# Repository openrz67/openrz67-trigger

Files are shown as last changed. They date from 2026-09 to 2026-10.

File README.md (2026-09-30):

# openrz67-trigger

ESP32 firmware and hardware for remote-triggering the Mamiya RZ67 analog camera over
Bluetooth LE. It runs on an ESP32-C3 connected to the camera's electrical remote port and is
controlled from the companion apps, [openrz67-android](https://github.com/openrz67/openrz67-android)
and [openrz67-ios](https://github.com/openrz67/openrz67-ios).

## Features

* Instant shutter release
* Bulb mode for remote long exposures
* Self-timer countdown with app-configurable duration
* Runs off a small LiPo, with light sleep between BLE events (see [Power](#power))

## Hardware

A custom PCB in a 3D-printed case:

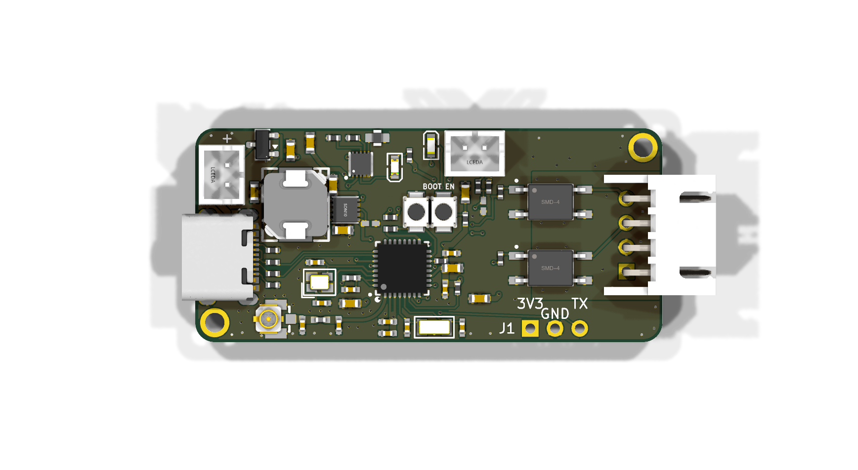
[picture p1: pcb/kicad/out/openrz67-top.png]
Custom PCB


| Directory | What |
|---|---|
| [`pcb/kicad/`](pcb/kicad/) | KiCad source, generated fab files in `out/`, design history in `notes/` |
| [`pcb/archive/`](pcb/archive/) | exactly what was sent to the fab, one folder per order |
| [`case/`](case/) | parametric build123d enclosure |
| [`BOM.md`](BOM.md) | every part that is not soldered to the PCB (cell, switch, antenna, cables) |

The boards in use are **rev 2**, verified working. The source is **rev 3**, not yet fabricated;
the case fits both.

On the board:

* ESP32-C3FH4 with an FPC antenna on a U.FL connector
* 2× Toshiba TLP172AM PhotoMOS relays (solid-state, isolated) close the shutter contacts
* TI BQ25185 charger (111 mA) and TPS63031 buck-boost, 250 mAh LiPo on `BAT1`, reverse-battery
  P-FET (rev 3)
* KCD11 rocker power switch on `S3`
* `J1`, unpopulated header for bench logging: 3V3, GND, GPIO21/TX (plus GPIO6 on rev 2)

The firmware also runs on any ESP32-C3 board with two isolated switch channels: assign two
output-capable GPIOs in `src/main.cpp`. On the PCB each GPIO drives a PhotoMOS LED through
150 Ω; the isolated output closes S1 or S2 to camera ground while the GPIO is HIGH. Keep
ESP32 ground and camera ground separate.

Wiring diagram for the ESP32-C3, two TLP172AM PhotoMOS channels and the Mamiya RZ67 camera port

### Pinout

| GPIO | Rev 2 (built) | Rev 3 (source) |
|---|---|---|
| 3 | Shutter output S2 (`S2_DRV`) | Battery sense (`VBAT_SENSE`): `SW_SYS` through a 1 MΩ / 1 MΩ divider |
| 4 | Shutter output S1 (`S1_DRV`) | same |
| 6 | `J1` pin 4, spare | Shutter output S2 (`S2_DRV`) |
| 20 | Status LED (`D4`, blue) | same |

The firmware covers every revision through build flags in `platformio.ini`: `S1_PIN` (rev 1),
`S2_PIN` and `VBAT_ADC_PIN` (rev 3).

### LEDs

Both LEDs sit under the same light pipe in the lid.

| LED | Meaning |
|-----|---|
| Red `D3`, steady | Charging. Driven by the charger IC, so it works with the power switch off. Off = full, no USB, or fault |
| Blue `D4`, slow soft pulse | On, waiting for a phone |
| Blue `D4`, dim steady | Phone connected |
| Blue `D4`, full steady | Trigger pulse (2 s) or bulb exposure |
| Blue `D4`, fast blink | Countdown running |

### Camera connector

`U4` is a JST S4B-XH-A four-pin side-entry header, opening out of the right board edge:

| U4 pin | Camera signal |
|---|---|
| 1 | Camera 6 V, unused by the board |
| 2 | GND |
| 3 | S1 |
| 4 | S2 |

Verify the pin 1 orientation before assembling the camera cable.

## Camera connection

Viewed from the front, the camera's four-pin remote-control port is:

1. 6 V — wired through, unused by the board
2. GND
3. S1 switch
4. S2 switch

To trigger the shutter, the PhotoMOS outputs short S1/S2 to camera GND. For bulb exposures,
set the shutter-speed dial to `B`. The camera closes the shutter by itself after about
60 seconds even if the switches stay closed.

## BLE protocol

The device advertises as `OpenRZ67` with service UUID `c9239c9e-6fc9-4168-b3aa-53105eb990b0`
and characteristic `458d4dc9-349f-401d-b092-a2b1c55f5319`. Send commands using Write Without
Response. The characteristic is open (no pairing): anyone in radio range can fire the camera,
which is accepted for a shutter release.

Also exposed: the standard Device Information Service (`0x180A`, firmware revision `0x2A26` =
`FW_VERSION` from `platformio.ini`), and on rev 3:

* characteristic `cda71ce6-4af9-4aa2-8d34-329c2acdae09` (read + notify): the `SW_SYS` voltage
  in millivolts, little-endian `uint16`, refreshed every 10 s. On battery this is the cell
  voltage (about 4200 full, 3500 low); on USB it is the charger's SYS voltage, which is higher.
  It is not a reliable USB-present flag: treat roughly 4250–4350 as undecided.
* Battery Service (`0x180F`, Battery Level `0x2A19`): the same reading as a percentage, linear
  from 3500 mV (0 %) to 4200 mV (100 %), which is what phones show without any app.

**Single-byte commands** (value = button × 10 + state):

| Value | Action |
|---|---|
| 11 | Trigger shutter with a 100 ms pulse |
| 10 | Clear status LED; no shutter action |
| 21 | Start bulb mode: holds S1/S2 closed until 20 is sent. Camera dial must be on `B` |
| 20 | End bulb mode |
| 31 | Start countdown with the default duration of 10 s |
| 30 | Cancel countdown |

**Three-byte commands** `[command, duration, action]`:

| Bytes | Action |
|---|---|
| `[3, n, 1]` | Start countdown of *n* seconds (`1–255`) |
| `[3, _, 0]` | Cancel countdown |

Starting a trigger or bulb exposure cancels any pending countdown. Commands are queued in
the BLE callback and executed in `loop()`, so the BLE stack never blocks on shutter timing.

## Building

[PlatformIO](https://platformio.org/) with the [pioarduino](https://github.com/pioarduino/platform-espressif32)
platform (Arduino core 3.3, ESP-IDF 5.5, NimBLE):

```bash
pio run
pio run -t upload
```

If uploading does not start, hold `BOOT`, press and release `EN`, then release `BOOT` and retry.

| Env | Board |
|---|---|
| default | rev 2 |
| `rev1` | rev 1 (S1 on GPIO 21) |
| `rev3`, `rev3-debug` | rev 3 (S2 on GPIO 6, battery sense on GPIO 3) |
| `debug` | rev 2 with USB CDC logging and `VERBOSE=1` |

The production build has no serial output. UART0 is not used for logging because its RX pin
(GPIO 20) drives the status LED; GPIO 21 (UART0 TX) is on `J1` for a TX-only dongle.

`pio check` runs cppcheck over `src/`; CI (`.github/workflows/firmware.yml`) builds every env
and runs it on each push.

## Power

The chip runs at 80 MHz with DFS down to 10 MHz, 0 dBm BLE TX power, and automatic light
sleep between BLE events: the radio wakes it for each one, so the phone connection stays up
and a trigger arrives as before. `custom_sdkconfig` in `platformio.ini` has pioarduino
rebuild the Arduino core with `CONFIG_PM_ENABLE`, tickless idle, BLE modem sleep and the
32.768 kHz crystal `X2` as the BLE low-power clock (the first build per machine takes a few
minutes). Consequences:

* The status LED runs on LEDC from `RC_FAST` in keep-alive mode, since the APB clock stops
  in light sleep.
* Light sleep releases every GPIO, so a PM lock keeps the chip awake while the shutter is
  open (bulb and the trigger pulse).
* The USB Serial/JTAG port drops off the bus in light sleep, so the `debug` env stays awake,
  and flashing a sleeping production build may need the `BOOT`/`EN` sequence above.

If `X2` does not start, ESP-IDF falls back to the internal RC and BLE keeps working without
light sleep. Current draw is not measured yet.

## License

[MIT](LICENSE), covering the firmware in `src/`, the KiCad design files in `pcb/kicad/` and
the enclosure sources in `case/`. MIT is written for software, but its grant is broad enough
to serve a hardware design; the closest hardware-specific equivalent is CERN-OHL-P.

Two things in this repository are **not** covered, because they are not mine to license:

* The footprints in `pcb/kicad/openrz67.pretty/` and the symbols in `openrz67.kicad_sym`
  were imported from the EasyEDA/LCSC part libraries.
* The 3D models in `pcb/kicad/openrz67.3dshapes/` were fetched per LCSC part number with
  `easyeda2kicad`.

Both are redistributed here for convenience under their originators' terms.

## Credits

The camera connector pinout that made this project possible was described to me by
Julio Ryuuzaki, who built and sold the Bluetooth [RZ Blue](https://ryuuzaki.jp/) trigger
for years. He answered a cold email in December 2022 with the essentials — four pins, one
ground, two live, one unconnected — and the warning that the camera closes the shutter by
itself after about a minute in bulb mode. Thank you.

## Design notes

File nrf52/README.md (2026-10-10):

# nRF52 coin-cell trigger

Second board design for the RZ67 trigger: an nRF54L15 module on a CR2032, no regulator,
charger or power switch. Rev A is ordered (fab package in [`kicad/archive/`](kicad/archive/)).

| Directory | What |
|---|---|
| `kicad/` | the board, generated from `tools/design.py`; fab files in `out/` |
| `case/` | build123d snap-fit box |
| `firmware/` | Zephyr application, builds on nRF Connect SDK v3.4.1 |
| `notes/` | reasoning and history |

## Parts to buy

Nothing is soldered by hand. The board comes assembled, everything else plugs in.

| What | Where | Note |
|---|---|---|
| Assembled board | JLCPCB, upload `kicad/out/openrz67-nrf-gerber.zip` + BOM + pos from `kicad/out/` | assembly on both sides |
| CR2032 | anywhere | one per board |
| SH1.0 4P to Dupont female cable (Qwiic / STEMMA QT pigtail) | AliExpress | three: one camera cable (`J1`), one for flashing (`J2`), one spare |
| Raspberry Pi Pico 2 WH | any Pi reseller | the flashing probe; H = headers pre-soldered, W is irrelevant here. Load Raspberry Pi's `debugprobe_on_pico2.uf2` on it; a Pico H (`debugprobe_on_pico.uf2`) works the same |

`J2` pin 2 carries the cell voltage out. Never plug a powered Qwiic device into `J2`; only the
probe cable belongs there. The camera end of the `J1` cable goes to the RZ67 socket as today (GND, S1, S2). Wiring for
`J2` to the Pico is in [`firmware/README.md`](firmware/README.md).

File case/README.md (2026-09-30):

# Parametric enclosure (build123d)

`openrz67_case.py` is a parametric two-part enclosure for the OpenRZ67 trigger PCB, written
in [build123d](https://build123d.readthedocs.io/). It is built from the board file and its
footprints, not from eyeballed measurements. Drawn for rev 2 (tag `pcb-rev2`); rev 3 keeps
the outline, holes and every connector and LED position, so the same case fits.

Layout: the LiPo cell lies flat **under the PCB** in a low rib pocket, the PCB sits on 8 mm
posts, and open pockets in front of (2 mm) and behind (4 mm) the board take fingers and the
battery lead. `U4` and its plug stay inside; only the heat-shrunk camera cable leaves
through a keyhole slot in the right wall. The lid snaps on, no hardware.

Finished size with default values: ~**64.9 × 36.0 × 25.5 mm**. The lid height is set by the
rocker switch's latch pocket. Printed in ABS; all fit numbers are ABS-measured.

The reasoning behind the numbers, and everything that was tried and dropped, is in
[`notes/design-history.md`](notes/design-history.md).

## Source data

Board coordinates in the script have the origin at the board's front-left corner with Y
toward the back; KiCad measures Y from the other long edge, so `board_y = 22 - kicad_y`
(`../pcb/kicad/out/openrz67-pos.csv` lists KiCad Y as negative numbers; drop the sign).

| Measurement | Value | Source |
|-----|---|---|
| Board outline | 48.0 × 22.0 mm, R2.0 | `openrz67.kicad_pcb` Edge.Cuts |
| Mounting holes | 2× Ø2.0 at (2,2) and (46,20) | `MountingHole_2.0mm_Pad3.0` footprints |
| PCB thickness | 1.6 mm | `pcb_t` (as ordered) |
| Component placement | see `openrz67_case.py` | `out/openrz67-pos.csv` |
| U4 camera connector | side-entry S4B-XH-A, pin row at (44.3, 11), mouth facing +X; body 12.4 wide × 6.1 tall, mouth 5.5 mm past the board edge | `CONN-TH_S4B-XH-A-LF-SN.kicad_mod` + `.wrl` |
| USB-C connector | body 8.95 × 3.2 mm, left edge 4.8 mm in from the PCB's left edge; shell protrudes ~2 mm past the board | measured |
| Rocker switch (KCD11) | snap-in body 13.5×8.5 (= panel cutout), flange 15×10, 10 deep behind the flange, two 2.8 mm tabs ~5 long at ~7 mm pitch; vendor drawings differ by ~0.5 mm | vendor data — measure your switch |
| FPC antenna | Ebyte TX2400-FPC-2509, 25 × 9 × ~0.2 mm, U.FL, ~100 mm cable, to `A1` | vendor data |
| LEDs | D3 red (20.5, 18.0), D4 blue (24.2, 20.2), 0603 top-emitting | `out/openrz67-pos.csv` |

Component heights are editable constants (`h_usbc`, `h_ph_plug`, `xh_h`) from the datasheets
and 3D models. Check them against your own parts.

The script carries **module-level assertions**: outer dimensions, probe checks that every
opening breaks through (USB, camera cable slot, LED window, locating-pin recesses, switch
hole and latch pocket), and that the fit-critical keepouts (switch body + tabs + receptacles,
USB-C body, U4 + mated plug, the cell under the PCB) stay open. They run on every export, so
a parameter tweak that closes a hole or re-introduces a known collision fails loudly.

## Construction

- **Base** (tub): floor, four **8 mm posts** (`standoff_h`; two at the mounting holes, two at
  `pcb_supports = [[2,20],[46,2]]`), and two **Ø1.85 locating pins** (`pin_d`) up into the
  board's Ø2 mounting holes. The cell lies on the floor between the posts, lengthwise from
  board-X `batt_x0`, inside a low rib ring (`batt_rib_t/h`, `batt_clr`) with foam tape on top.
  - **Through-hole solder relief** (`th_keepouts`, `[board_x, board_y, diameter]`,
    `th_keepout_depth` 3.5): a pocket in a post top where a through-hole part's tails stick down.
  - **Guide fins** (`frame_*`): fins from the wall across the pockets hold the PCB in Y, two
    per long edge (`frame_ribs_front/back`), ending `frame_clr` from the board edge with a
    lead-in lip `frame_proud` above it. The lid tongue is notched where they stand.
- **Lid**: telescopes into the base via a perimeter tongue (`lap` 7 mm). Carries the USB-C
  opening (left), the camera cable slot (right), the LED light-pipe seat (top) and the snap-in
  hole for the rocker switch (front). Top edge chamfered `lid_top_r` (2 mm, 45°): the lid
  prints upside-down, so this is the bed-side edge.
  - **Camera cable slot** (`cut_cable`): the U4 body and the mated XHP-4 plug (`xh_plug_proud`
    2.5 past the mouth, an estimate) stay inside; `xh_slack` (1.5) sets `pcb_overhang_right`
    (9.1). The cable leaves through a **keyhole** in the right wall: round top of `cable_d` +
    2 × `cable_clr` (Ø6) at the header's mid-height, open straight down to the seam, so the
    bundle drops in as the lid closes and the lid lifts off untethered.
  - **LED light pipe** (`led_*`, separate part, clear filament): a top hat with a tapered
    head in a 26.6° funnel seat and a rod down to `led_pipe_gap` (0.8) above the LEDs. **Slip
    fit, glued**: `led_stem_clr` = `led_pipe_clr` (0.2). A collar `led_collar_h` (2.6) off the
    ceiling keeps it straight. Parameters: `led_win_l/w/r`, `led_head_lip/t`, `led_pos`.
  - **Component clearance** (`comp_keepouts`): rectangles cut out of the lid's hold-down
    bosses where a boss would hit a component (e.g. the boss at hole (2,2) is D-shaped to
    clear the USB-C body).
  - **Antenna recess** (`ant_*`): a 25.6 × 9.6 × 0.3 mm pocket in the lid ceiling for the
    adhesive FPC antenna, in the free band between the rocker body and the light-pipe stem.
    `ant_cx_frac` (0.25) slides it along the band. Asserted to fit the band and to leave
    ≥ 0.8 mm of top plate under the lid text.
- **USB-C side**: `pcb_overhang_left` (2.0) makes room for the shell; `usb_shell_poke` (1.4)
  slides the board toward that wall so the shell noses into the recess. On the right,
  `pcb_overhang_right` (9.1) makes room for the mated XH plug.
- **Battery** (31 × 20 × 6 LiPo): under the PCB with `batt_foam` (1.5) between. Its lead comes
  out at the left end over the rib, into the 4 mm pocket behind the board, up past the edge
  and into BAT1 on top. Nothing is threaded: cell in, board onto the pins, lead over the
  edge, lid on. Parameters: `batt_w/l/t`, `batt_x0`, `batt_foam`, `batt_clr`, `batt_rib_t/h`,
  `pocket_front/back`.

## Closure — snap fingers

Four **cantilever fingers** cut free in the lid tongue (two per long wall, `snap_fingers_x`)
carry a bead (`snap_bead` 0.55, `bead_h` 1.4; 0.4 click-in chamfer below, 0.15 above) that
clicks into a pocket in the base lip (`pocket_extra_d/h`, `pocket_ch`). Each finger is
`finger_l` (12) long and `finger_t` (1.0) thick with a `finger_slot` (0.8) relief at each end;
the bead sits `bead_tip_h` (1.1) above the tip, so the lever is ~6 mm: about 2 % strain at
full deflection. The rest of the tongue and the base lip stay rigid (`wall` 3.2). The PCB is
pressed onto the posts by the lid's hold-down bosses (blind pin recesses, no holes through
the top). Open with a coin in the **pry slot** (`pry_w/d/h`) on the back wall; the back
fingers release first.

**Tune before the full print:** `SNAP_TEST=true ./export.sh` also exports a cropped
front-left corner pair (`openrz67-snaptest-*`) with one finger and one locating pin. Print
those and adjust `snap_bead` (click strength), `finger_t` (stiffness) and `lap_gap` (sliding
fit) until the corner snaps shut and pries open with reasonable force.

## Orientation mark — `orient_mark`

A raised rib on the front wall near the left corner, split across the seam: base carries the
lower half, lid the upper. Lid on the right way round, the halves line up; 180° wrong, the
lid's half lands at the other corner. Parameters `orient_mark_x/w/d/h`; delete the two
`orient_mark_rib` lines to remove it.

## Lid text — second colour (`lid_texts`)

Debossed nameplate in front of the LED seat: **"OpenRZ67"** (9.5 mm) over a tracked all-caps
**"TRIGGER"** (5 mm, +1.0 letter spacing), Futura Bold (macOS system font; OCCT falls back to
Arial if missing). A thin rail (`lid_rail_*`) runs across the LED row and breaks around the
light-pipe seat. Pockets are `lid_text_depth` (0.8 mm, 4 layers; 0.9 is the cap) deep and an
**inlay** solid (`lid_text`, exported as `openrz67-lid-text.stl`) fills them exactly.
Assertions enforce placement and printability (every glyph stroke ≥ `lid_text_min_stroke`
0.6 mm).

Colour it by **part, not by slicer paint**: `make_3mf.py` adds the inlay to the lid object as
a second part on filament 2 (`SUB_PARTS`). Set filament 2 to the letter colour and print. On
a single-filament printer, delete the inlay part and do a manual filament change at Z = 0.8
(slice the lid alone).

Edit `lid_texts`, `lid_font`, `lid_text_gap` and `lid_rail_*` to restyle; `LID_TEXT_SHOW=false`
disables the text.

## Usage

The parameters are plain Python constants at the top of `openrz67_case.py`. Requires
[uv](https://docs.astral.sh/uv/); the script carries its own dependency header.

```bash
cd case
./export.sh            # base, lid, lightpipe, lid text -> stl/  + openrz67-case.3mf
./export.sh out        # custom output dir (skips the .3mf)
```

Overrides from the environment:

```bash
LID_TEXT_SHOW=false  ./export.sh   # hide the lid text
LID_TEXT="My text"   ./export.sh   # the name line (TRIGGER stays)
LID_TEXT_SIZE=8.0    ./export.sh   # its font size (mm, default 9.5)
SNAP_TEST=true       ./export.sh   # also export the corner test pair
PCB_T=1.0            ./export.sh   # PCB thickness (sets the base/lid split)
MAKE_3MF=false       ./export.sh   # skip the .3mf
```

Or run the script directly: `uv run openrz67_case.py`. For a plain interpreter there is a
local venv: `uv venv .venv && uv pip install -p .venv "build123d>=0.11.1"` (git-ignored, as
is `stl/`). For a 3D preview, open the file with an OCP viewer (e.g. `ocp_vscode`) or inspect
the STLs in the slicer.

### Slicer project (.3mf)

`export.sh` rebuilds `openrz67-case.3mf`, a Bambu Studio / OrcaSlicer / QIDI Studio project:
base + lid on plate 1 (filament 1, lid text on filament 2), the light pipe alone on plate 2
(filament 3 = clear) with its own object settings (0.28 layers, 100 % infill, 8 walls,
20 mm/s). `make_3mf.py` swaps the fresh meshes into a template saved from the slicer
(`bambu-template.3mf`), so all slicer settings are preserved. To change print settings, plate
layout or filament mapping, edit the project in the slicer and re-save it over
`bambu-template.3mf`. Plate thumbnails are not regenerated; the slicer refreshes them.

Do not use height-range modifiers in the template: QIDI Studio crashes on opening a .3mf
that carries them. Per-object settings are safe.

## Print orientation

- **Base**: floor down. No supports.
- **Lid**: **upside down** (top plate on the bed). Bosses and lip point up, and the LED funnel
  is widest at the bed. Turn elephant-foot compensation on (~0.15) so the first layer does
  not close in on the funnel rim; support threshold 30° or lower.
- **Light pipe**: clear filament, upright (head down). For the clearest light: thick layers
  (0.28–0.3), 100 % infill, slow, hot, fan off, on a **smooth** plate (the head's top face
  prints against it).

## Worth adjusting before printing

- `pcb_t`: PCB thickness (1.6 as ordered). Sets the base/lid split height.
- `pcb_overhang_left`: air for the USB-C shell. Measure your connector. Default 2.0.
- `h_ph_plug`: PHR-2 plug + wire bend height on `BAT1`/`S3`. Lower it if yours sit lower.
- `xh_plug_proud` / `xh_slack`: mated XHP-4 plug past the U4 mouth (2.5, estimate) and air to
  the wall. `cable_d`: the heat-shrunk bundle's diameter (5.0).
- `snap_bead` / `finger_t` / `lap_gap`: tune with the `SNAP_TEST` corner pieces.
- `batt_*`: your cell and its pocket. `standoff_h` must stay ≥ cell + foam (asserted).
- `ant_l/w/clr/depth` / `ant_cx_frac`: the antenna and its recess. Optional part; BLE works
  without it at much less range.
- `sx`: rocker switch position, centred on the lid (`outer_w / 2`) on the front wall. The
  back wall carries S3, the LEDs and the lead pocket. `kcd_gap` (1.6) is the body's height
  above the PCB.
- **Switch mount**: hole `kcd_body_l/h` + 2 × `kcd_hole_clr` (0.3); the wall is pocketed from
  the inside to `kcd_panel_t` (2.0) for the latches, `kcd_latch_clr` (1.2) past the hole.
  Asserted clear of the tongue, ceiling, seam and chamfer. **Measure your switch first**: body,
  flange, depth, tab length and pitch, panel thickness.
- **Switch wiring**: two 2.8 mm **flag (90°) receptacles** on the tabs, 4–6 cm of 26 AWG to
  the PH plug in S3. A straight receptacle does not fit behind the switch (asserted). Fold
  the thin wire end double for the crimp.

## USB-C opening

Three layers in the wall, outside in:

- **Plug pocket** `usb_pocket_w/h/r/d` = 14 × 9.5 mm, R3, 1.2 deep, 45° bevel `usb_pocket_ch`
  (0.6). The cable's overmold sinks into it. Fits overmolds up to 13 × 8.5.
- **Pass-through** `usb_open_w/h` = 10 × 4.6 mm, R1.8. Its edge is the lip (0.8 mm, asserted)
  that stops the overmold.
- **Inner recess** `usb_recess_w/h/d` = 13 × 9 × 1.2 mm on the cavity side: the receptacle
  shell noses into it, 0.2 short of its floor (asserted).

The opening's centre (`usb_zc`) sits 1.65 mm above the base/lid split, so `cut_usb` is
subtracted from both parts and the base keeps full wall through the lap zone (`usb_solid_w`).
Measure your charging cable; test with a print of just the left end first.

## Known / to verify

- Check that your charging cable reaches the port.
- Measure `xh_plug_proud` and `cable_d` against your cable.
- Print the `SNAP_TEST` corner first.
- **Light pipe**: verify the rod lands over D3/D4 (`led_pos`) and clears them
  (`led_pipe_gap`). Drop it in and glue it on top. Rattles sideways: lengthen `led_collar_h`.
  Never a negative `led_stem_clr`.
- The USB-C and switch openings are open by necessity; the LED window is sealed by the pipe.

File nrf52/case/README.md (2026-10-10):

# Parametric enclosure for the nRF52 board (build123d)

`openrz67_nrf_case.py` is a two-part snap-fit box, plus a light pipe, for the coin-cell board in
[`../kicad/`](../kicad/). Outer size with default values: **39.7 × 37.2 × 12.6 mm**. Printed in
ABS, lid upside-down, base floor-down, no supports. The light pipe prints in clear filament,
head-down, and is glued into the lid.

Layout: the board rests on a 1 mm ledge around the base cavity, component side up, with the
CR2032 and its clip hanging below it. The lid presses the board onto the ledge with four
bosses and carries the button tab, the LED light pipe and the opening for the camera plug. The
floor is flat and closed, for velcro on the camera. Two hooks in the lid clip under the
board's side edges. To change the cell, pry the lid off with a coin in the front slot: the
board comes with it, and the cell slides backwards out of the clip. To take the board out of
the lid, pull the tab under each hook outward.

## Source data

Board coordinates are the KiCad coordinates of `openrz67-nrf.kicad_pcb` (origin top-left,
Y toward the back wall). KiCad's view turned 180° puts the antenna at the front, so board X
runs right to left in the case: the module sits front-right, the camera plug back-left. Values come from `../kicad/tools/design.py` and the part datasheets:

| What | Value |
|---|---|
| Board | 29.5 × 29 mm, R0.8, 1.6 thick, no mounting holes |
| Cell clip `BT1` (back) | 25.9 × 9.4, 3.75 high, cell Ø20 × 3.2 under it, centre (13.5, 18) |
| Button `SW1` | B3U-1000P at (6.0, 27.6), 1.6 high |
| LED `D1` | (18.2, 27.6) |
| Camera connector `J1` | SM04B-SRSS-TB at (23.6, 24.7), 6.0 wide, 2.9 high, mouth toward board y = 29 |
| SWD connector `J2` | same part at (12.3, 24.7), same mouth direction, no wall opening |
| Module `U1` | 15 × 19 × 2.0 incl. pads, antenna end at board y = 0 |

## Construction

- **Base**: tub with a board ledge: a wall standing on the floor up to `pcb_z`, `ledge_gap`
  (0.2) inside the lid tongue, reaching 1.0 under the board on every side (`ledge_w` 1.4
  from the front and back walls). Below the tongue it joins the outer wall. Broken on both
  sides where the clip passes and the hooks hang, and along the back where the cell comes
  within 1 mm of the board edge. The base keeps its full wall along the whole back. A 10 mm
  "+" is debossed 0.4 into the floor under the cell: the cell's + side faces the floor. The front
  ledge bridges `ant_wall_clr` (1.0 mm of air in front of the antenna end). Flat closed
  floor. Pry slot on the front wall at the seam. The bottom edge has the same 1 mm 45°
  chamfer (`edge_r`) as the lid's top edge.
- **Orientation rib** (`orient_mark_*`): a 2.5 × 0.8 rib on the front wall, 7 tall, split at
  the seam between base and lid. The halves line up only when the lid is on the right way
  around. Off-centre at board x 4, clear of the pry slot.
- **Lid**: telescoping tongue (`lap` 5) with four snap fingers on the **side** walls (the
  back wall carries the plug opening). Hold-down bosses (`bosses`, board x/y/Ø) at four free
  spots: the module owns the board's (0, 0) corner and `C1` + `J1` the (29.5, 29) one.
  - **Button**: a `tab_w × tab_l` (6 × 7.45) cantilever tab cut free by a `tab_slot` (0.7)
    U-slot with `tab_r` (1.5) corners at the free end, hinged at its front end, thinned to `tab_t` (0.8) from the inside, with a
    Ø`nub_d` (2.4) nub that stops `nub_gap` (0.3) above the switch cap. The free end is
    `tab_tip` (1.45) past the switch centre, so it ends over the cavity, not over the wall.
  - **LED light pipe**: a top hat over `D1`, as on the ESP32 case. Ø`led_stem_d` (2.2) stem,
    ending `led_pipe_gap` (0.8) above the board, in a slip-fit window (`led_pipe_clr` 0.2)
    that a collar off the ceiling lengthens down to the pipe's lower end. The head tapers out
    by `led_head_lip` (0.7) over `led_head_t` (1.4), 26.6° from vertical, into a matching
    funnel in the top, so it self-centres and nothing needs support. Glued.
  - **Text**: "OpenRZ67" (5.8) over a tracked "TRIGGER" (4.0), Futura Bold grown
    `lid_text_bold` (0.05) per side so every stroke is at least 0.6 mm, debossed
    `lid_text_depth` (0.8) into the top. Centred in X, and in Y between the front chamfer and
    the LED. A 0.9 mm rail runs from the left side into the LED seat, as on the ESP32 case.
    The pockets are filled by
    `openrz67-nrf-lid-text.stl` (text and rail), a second part of the lid on filament 2 in the .3mf.
    `LID_TEXT_SHOW=false` turns it off; `LID_TEXT` / `LID_TEXT_SIZE` change the name line.
  - **Board hooks** (`hook_*`): a 1.0 × 3.4 finger off the ceiling on each side wall, at
    board y 13.45, between the snap fingers and in front of the clip's solder legs. The barb
    reaches `hook_grip` (0.5) under the board, with a flat face toward the board and a 45°
    lead-in below it. `hook_flex` (0.7) of air behind the finger lets it spring out as the
    board goes in. A `hook_tab` (1.5) below the barb is the release: pull it outward with a
    fingernail between the tab and the clip leg. The hooks set the board-to-side-wall gap,
    `side_clr` (1.9).
  - **Plug opening**: connector width + 2 × `conn_clr` (0.5), from the board top up
    `conn_h + conn_clr`, open to the seam, so the lid lifts off with the plug in place.
  - **No tongue on the back wall**: the base has its full wall there instead. That gives the
    plug a floor, and with the board in the lid the cell slides out backwards under it.
- **Snap**: the ESP32 case's finger geometry unchanged (`snap_bead` 0.55, `bead_h` 1.4, 0.4
  click-in / 0.15 retention chamfers, `finger_t` 1.0, `finger_slot` 0.8), fingers 10 long,
  `wall` 3.2 so both lap halves stay two perimeters thick. Tune with `SNAP_TEST=true`.

The script carries module-level assertions: each part is one body, base and lid do not
overlap, outer dimensions, the board / cell / clip / module / connector / switch / LED
keepouts (the clip as strap plus solder legs, from its 3D model), the bosses and the light-pipe collar clear of every top-side part, the light pipe
clear of the lid, the button tab tip over the cavity, the
camera plug opening on the left (a board mapped without the mirror fails here), every opening breaking through, the orientation rib clear of the pry slot and the
lid chamfer, the front ledge actually being under the
board, the board hooks (placed where intended, clear of the snap finger slots, air behind
them, reaching under the board) and the cell's way out backwards with the board in the lid. They run on every export.

## Usage

```sh
cd nrf52/case
./export.sh                          # base + lid + light pipe -> stl/, then openrz67-nrf-case.3mf
SNAP_TEST=true ./export.sh           # also a cropped corner pair (not in the .3mf)
```

Requires [uv](https://docs.astral.sh/uv/); the script carries its own dependency header.

`openrz67-nrf-case.3mf` is the QIDI Studio project: plate 1 base floor-down and lid upside-down
(ABS profile, lid text on filament 2), plate 2 the light pipe head-down on filament 3 (clear,
0.28 mm layers, 100 % infill, 20 mm/s). The template has the ESP32 case's settings, except a
0.42 mm first-layer line width (the lid text is the first layer). `../../case/make_3mf.py` builds it by swapping the fresh STLs into
`qidi-template.3mf`, so the slicer settings survive every re-export. To change settings or the
plate layout: open the project in QIDI Studio, change it, save, and copy it over
`qidi-template.3mf`.

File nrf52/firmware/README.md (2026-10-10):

# Firmware for the nRF52 board (Zephyr / nRF Connect SDK)

Zephyr application for the coin-cell trigger in [`../kicad/`](../kicad/). Same Bluetooth
services and command bytes as the ESP32-C3 firmware in the repository root, so the
[Android](https://github.com/openrz67/openrz67-android) and
[iOS](https://github.com/openrz67/openrz67-ios) apps work unchanged. Builds with nRF Connect
SDK v3.4.1 (MCUboot 39 kB, app 147 kB flash, 45 kB RAM); not yet flashed on hardware.

| File | What |
|---|---|
| `src/main.c` | the application: GATT, advertising, shutter, countdown, LED, battery, sleep |
| `prj.conf` | Kconfig: Bluetooth peripheral, BAS, DIS, SMP (updates), ADC, GPIO, HFINT calibration, no serial |
| `sysbuild.conf`, `sysbuild/mcuboot.conf` | MCUboot as the bootloader, fed watchdog during a swap |
| `debug.conf` | add-on: logging over Segger RTT |
| `boards/openrz67/openrz67_nrf/` | the board: pin map (devicetree), SoC, flash runners |

## Behaviour

- Power on (or a button press from sleep): advertises as `OpenRZ67` for 5 minutes. No
  connection in that time: System OFF (about 0.7 µA), the button wakes it.
- Connected: stays on as long as the app holds the link. After a disconnect it advertises
  5 minutes again (started from the `recycled` connection callback), then sleeps.
- Button held 3 s: off. It disconnects the app, waits for the button to be released (a held
  button would wake it again at once) and goes to System OFF. A press wakes it.
- Commands on the command characteristic, write without response:
  - 1 byte `button * 10 + state`: button 1 trigger, 2 bulb, 3 countdown; state 1 start, 0 stop.
  - 3 bytes `[3, seconds, state]`: countdown with its duration.
- Trigger: S1 on, 10 ms, S2 on, 100 ms, both off. Bulb: S1 then S2 on until stop or a
  disconnect. Countdown: fast LED blink, then a trigger.
- Watchdog: 5 s. A hung main loop resets the chip, which releases S1/S2.
- LED: solid while the shutter is held or for 2 s after a trigger, fast blink in a
  countdown, a short blink every 2 s while advertising, off when connected and idle.
- Battery: VDD measured on the internal ADC channel every 60 s; mV on the custom
  characteristic (uint16 LE, notify), percent on the Battery Service, linear 2.5 to 3.0 V.

## Pins

| Function | nRF54L15 | Module pad |
|---|---|---|
| S1 PhotoMOS LED, high drive | P2.04 | 27 |
| S2 PhotoMOS LED, high drive | P2.05 | 28 |
| Status LED | P2.00 | 18 |
| Button, to GND (SENSE, latch detect, no GPIOTE channel) | P1.04 | 7 |
| SWCLK / SWDIO | | 11 / 12, `J2` pins 3 / 4 |

Both crystals (32 MHz, 32.768 kHz) are inside the module. Ebyte does not give their load
capacitance; the devicetree uses the nRF54L15 DK values. At boot the firmware asks the chip
whether the module has the DC/DC inductor and turns DC/DC on if so (about half the radio
current); otherwise it stays on the LDO.

Chip anomalies handled: 114 (a bouncing button on a SENSE pin can leave ~300 µA on in idle;
`latch-detect` on the port), 30 (HFINT drifts in the cold and GRTC wake-ups fail;
`CONFIG_CLOCK_CONTROL_NRF_HFINT_CALIBRATION`).

## Build and flash

Needs the nRF Connect SDK (west workspace) and the Zephyr SDK toolchain. One-time setup, as
done on the development Mac:

```sh
brew install cmake ninja dtc
uv venv --python 3.12 ~/ncs/.venv && uv pip install -p ~/ncs/.venv west
cd ~/ncs && source .venv/bin/activate
west init -m https://github.com/nrfconnect/sdk-nrf --mr v3.4.1 . && west update --narrow -o=--depth=1
uv pip install -p .venv -r zephyr/scripts/requirements.txt -r nrf/scripts/requirements-build.txt
# Zephyr SDK 1.0.1 (zephyr/SDK_VERSION): minimal bundle + the arm toolchain into gnu/, then setup.sh -h -c
```

Build (the board lives in this directory, so pass it as `BOARD_ROOT`). Sysbuild builds
MCUboot and the app and signs the app:

```sh
cd ~/ncs && source .venv/bin/activate && export ZEPHYR_SDK_INSTALL_DIR=~/zephyr-sdk-1.0.1
FW=/path/to/openrz67-trigger/nrf52/firmware
KEY=~/.openrz67/mcuboot-ed25519.pem
west build -b openrz67_nrf/nrf54l15/cpuapp -s $FW -d $FW/build -- -DBOARD_ROOT=$FW -DSB_CONFIG_BOOT_SIGNATURE_KEY_FILE=\"$KEY\"
west build -b openrz67_nrf/nrf54l15/cpuapp -s $FW -d $FW/build -- -DBOARD_ROOT=$FW -DSB_CONFIG_BOOT_SIGNATURE_KEY_FILE=\"$KEY\" -DEXTRA_CONF_FILE=debug.conf   # RTT logging
```

MCUboot only boots images signed with the key it was built with. Make the key once, outside
the repository, and keep a backup: without it, updates need the probe again.

```sh
mkdir -p ~/.openrz67 && ~/ncs/.venv/bin/python ~/ncs/bootloader/mcuboot/scripts/imgtool.py keygen -t ed25519 -k ~/.openrz67/mcuboot-ed25519.pem
```

Without `SB_CONFIG_BOOT_SIGNATURE_KEY_FILE` the build uses MCUboot's public test key (with a
warning), and anyone could sign an image the board accepts.

Outputs: `build/merged.hex` (MCUboot + app, for the probe) and `build/dfu_application.zip`
(app only, for an update over Bluetooth).

### Update over Bluetooth

Once MCUboot is on the board, the app updates from a phone. Close the OpenRZ67 app first, the
board takes one connection.

1. Copy `build/dfu_application.zip` to the phone.
2. Wake the board (button) so it advertises.
3. In nRF Connect Device Manager (Nordic, iOS and Android): pick `OpenRZ67`, Image, Firmware
   Upgrade, select the zip, mode "Test and Confirm", Start.

The board restarts into the new image. If that image does not come back on Bluetooth, MCUboot
falls back to the old one on the next reset.

### First flash with the probe

Flashing is over SWD through `J2`, a JST SH 1.0 mm connector: a Qwiic / STEMMA QT cable with
female Dupont ends goes straight onto a Raspberry Pi Pico 2 WH (pre-soldered headers) running
Raspberry Pi's `debugprobe_on_pico2.uf2` (CMSIS-DAP; `debugprobe_on_pico.uf2` on a Pico H),
no soldering anywhere. pyOCD drives it; a
J-Link works through its own runner:

```sh
pip install 'pyocd>=0.37'    # nrf54l target built in, no pack
west flash -d $FW/build --runner pyocd
west flash -d $FW/build --runner jlink
```

| `J2` pin | Qwiic wire | Pico pin |
|---|---|---|
| 1 GND | black | GND (pin 3) |
| 2 VDD | red | 3V3(OUT) (pin 36), with the cell **out**: the probe powers the board, so both sides run at 3.3 V. Never with the cell in, it would charge the CR2032 |
| 3 SWCLK | blue | GP2 (pin 4) |
| 4 SWDIO | yellow | GP3 (pin 5) |

There is no reset line; the probe resets the chip over SWD.

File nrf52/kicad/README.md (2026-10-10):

# openrz67 nRF52 PCB — KiCad project

KiCad 10 project for the coin-cell trigger: 29.5 × 29 mm, 2 layers, Ebyte E73-2G4M08S1F
(nRF54L15) module, CR2032 clip on the back, two TLP172AM PhotoMOS relays, JST SH 1.0 mm
side-entry camera connector, a second SH connector for SWD, one button, one LED, a P-MOSFET against a reversed cell. No regulator, no charger, no power
switch. Concept stage, not fabricated.

The schematic and the board are **generated**: `tools/design.py` holds parts, placement,
nets and every track, and the two generators write the KiCad files from it. Edit the model
and run `tools/regen.sh`; do not edit the `.kicad_sch` / `.kicad_pcb` by hand, the next
run overwrites them.

| File | What |
|---|---|
| `tools/design.py` | the design: parts with LCSC numbers, positions, nets, tracks, vias, keepout |
| `tools/gen_sch.py` | writes `openrz67-nrf.kicad_sch`: one symbol per part, a global label on every used pin, a no-connect on every unused one |
| `tools/gen_pcb.py` | writes `openrz67-nrf.kicad_pcb` with pcbnew: footprints, nets, outline, GND pours, antenna keepout, tracks, design rules |
| `tools/regen.sh` | runs both generators, then exports everything in `out/` and runs DRC (with schematic parity) and ERC |
| `tools/fetch_3d.sh` | downloads STEP+WRL models for every LCSC part in the BOM into `openrz67-nrf.3dshapes/` |
| `tools/module_3d.py` | box model of the E73 module (none on LCSC or from Ebyte): `uv run tools/module_3d.py` |
| `tools/export_step.sh` | board STEP to `out/openrz67-nrf.step` (gitignored); fetches missing part models first |
| `openrz67-nrf.3dshapes/` | 3D models; `.wrl` committed (renders), `.step` gitignored except the module's |
| `openrz67-nrf.kicad_sym`, `openrz67-nrf.pretty/` | project libraries: LCSC/EasyEDA imports via easyeda2kicad and KiCad's `R` |
| `out/` | generated: Gerber+drill zip, position file, BOM with LCSC numbers, schematic PDF, top/bottom renders, DRC/ERC reports |

## Regenerate

```sh
tools/regen.sh
```

Close KiCad first. Needs `kicad-cli` and KiCad's bundled python (for pcbnew); override with
`KICAD_CLI=… KICAD_PY=…`. It exits non-zero on any DRC/ERC error or unconnected pad.

## Circuit

The cell (`VBAT`) feeds the module through `Q1`, an AO3401A P-MOSFET with its drain on the
clip, source on `VDD` and gate on GND. The right way round the body diode conducts until the
channel turns on (under 85 mΩ at V<sub>GS</sub> = −2.5 V, about 1 mV at 15 mA). A cell put in upside
down leaves it off, so `VDD` never goes negative. The module has one supply pad (9, 1.8–3.6 V
per Ebyte; the nRF54L15 itself starts at 1.75 V) and both crystals inside. 100 µF sits at the clip terminal, ahead of `Q1` (a ceramic, a reversed cell does not harm it),
100 nF right at module pad 9 (`C3`, ground straight to pad 10) and 100 nF at `Q1`/SWD (`C2`).
Each PhotoMOS LED is driven from a GPIO through 220 Ω: about 4 mA at 2.7 V with the worst-case
LED forward voltage, the TLP172AM needs up to 3 mA. The status LED has 1 kΩ (about 1 mA).
With a fresh cell both relays and the LED draw about 14 mA, inside Nordic's recommended 15 mA
sustained total for all GPIOs.
The PhotoMOS outputs go to the camera connector; camera ground (`CAM_GND`)
is a separate net from the cell's `GND`.

| nRF54L15 | Module pad | Function |
|---|---|---|
| P1.04 | 7 | button to GND, internal pull-up, wake from System OFF |
| P2.00 | 18 | status LED through 1 kΩ |
| P2.04 | 27 | S1 PhotoMOS LED through 220 Ω |
| P2.05 | 28 | S2 PhotoMOS LED through 220 Ω |
| SWCLK / SWDIO | 11 / 12 | `J2` pins 3 / 4 |
| nRESET | 19 | not brought out; reset over SWD |

The button has to be on P0 or P1: P2 cannot wake the chip from System OFF. The three outputs run
at high drive (S0H1) so the PhotoMOS LEDs get their 5 mA. The left pad column faces the board
edge; `VDD` (pad 9) and the button (pad 7) leave it on two tracks between the module and the edge.

Connectors:

| Ref | Pin | Signal |
|---|---|---|
| `J1` camera, SH 1.0 mm (Qwiic/STEMMA QT cable) | 1 | camera ground (black) |
| | 2 | not connected |
| | 3 | S1 (blue) |
| | 4 | S2 (yellow) |
| `J2` SWD, SH 1.0 mm (Qwiic cable to the probe) | 1 | GND (black) |
| | 2 | VDD (red). With the cell out, the probe's 3.3 V powers the board here. Never with the cell in: it would charge the CR2032 |
| | 3 | SWCLK (blue) |
| | 4 | SWDIO (yellow) |

## Design rules

Clearance 0.127 mm, min track 0.127, default track 0.20 (signals 0.16, power 0.25), via
0.45/0.25, hole-to-track 0.175, hole-to-hole 0.30, copper-to-edge 0.30, mask expansion
0.051. JLCPCB silkscreen minimums (1.0 mm text, 0.15 mm line). A rule area over the
module antenna (x 0–15, y 0–5.3) keeps copper, tracks and vias off both layers.

## Accepted warnings

DRC and ERC have **0 errors**. The warnings left in the reports:

| Check | Count | What |
|---|---|---|
| ERC `endpoint_off_grid` | 17 | Pins of the imported symbols are not on the 1.27 mm grid. Connectivity is by label; verified by the schematic-parity DRC. |
| `silk_over_copper` | 11 | The holder footprint's own silkscreen crosses its centre pad. Fab clips it. |

## Mechanical

Outline 29.5 × 29 mm, R0.8 corners, no mounting holes. All parts on top except the cell clip
on the back. Module antenna end is flush with the top edge (y = 0); both SH connectors sit along the
bottom edge with their mouths facing it (y = 29), SWD left of camera (the SWD cable is a
lid-off job, no wall opening); the button sits bottom-left, the LED between the two connectors.

| Part | Height over the board |
|---|---|
| CR2032 clip `BT1` (back) | 3.75 mm, the cell under it; cell centre (13.5, 18), slides in from either long side |
| `J1` camera and `J2` SWD connectors | 2.9 mm, body 6.0 × 4.3 each |
| Module `U1` | 2.4 mm (Ebyte drawing) |

`BT1` is only the positive clip (MYOUNG drawing: "TERMINAL(+)"). The cell's negative face
rests on the Ø10 mm bare pad in the middle of the back. It has no paste, so the cell rests on
the pad's finish, not on a solder dome with flux on it. On the back a copper-free ring 7.5 to 10.2 mm from the cell centre lies
under the cell's rim, where the + can wraps over the edge; inside the ring only GND copper,
the same potential as the cell face resting on it. Ebyte's manual gives no antenna keepout figure; the rule area covers the
PCB antenna (the module's top 5.2 mm) plus 2 mm to its right. The module's 3D model is a plain box from
`tools/module_3d.py`: blue PCB with the antenna, grey shield.

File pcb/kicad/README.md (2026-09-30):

# openrz67 PCB — KiCad project

KiCad 10 project for the OpenRZ67 trigger board: 48 × 22 mm, 2 layers, ESP32-C3, two
TLP172AM PhotoMOS relays, BQ25185 charger + TPS63031 buck-boost. This is the source.
Each fabricated revision's upload package is frozen in `../archive/`, and the EasyEDA Pro
project it was ported from in `../archive/easyeda/`.

| File | What |
|---|---|
| `openrz67.kicad_pro/.kicad_sch/.kicad_pcb` | project, schematic (1 sheet), board |
| `openrz67.kicad_sym`, `openrz67.pretty/` | symbols and footprints as imported from EasyEDA/LCSC (project-local libs) |
| `tools/regen.sh` | rebuilds everything in `out/`; run it after any change to the board or schematic |
| `tools/post_import.py` | design rules, net classes, zone settings, layer names. **Authoritative**: it overwrites `openrz67.kicad_pro`, so rule changes made in Board Setup are reverted on the next run. Edit the values in the script. Close KiCad first. Idempotent. |
| `tools/fetch_3d.sh` | downloads STEP+WRL models for every LCSC part into `openrz67.3dshapes/` |
| `tools/export_step.sh` | board STEP to `out/openrz67.step` (gitignored, ~20 MB); fetches missing part STEPs first |
| `openrz67.3dshapes/` | 3D models; `.wrl` committed (render), `.step` gitignored |
| `out/` | generated: Gerber+drill zip, position file, BOM (with LCSC numbers), schematic PDF, top/bottom renders, ERC/DRC reports |
| `notes/` | design history, reviews and research; see [Revisions](#revisions) |

## Regenerate outputs

Everything in `out/` is generated. Rebuild all of it with one command, so the committed
outputs and the check reports always describe the committed sources:

```sh
tools/regen.sh
```

It runs `post_import.py`, exports Gerbers, drill files and their maps, zips them, writes the
position file, the BOM, the schematic PDF and the two board renders, then runs DRC with
schematic parity and ERC. It exits non-zero on errors; warnings are printed and accepted
(see below). Close KiCad first: `post_import.py` rewrites the board and the project file.

Override the tool paths if KiCad is not in the macOS default location:

```sh
KICAD_CLI=/usr/bin/kicad-cli KICAD_PY=/usr/bin/python3 tools/regen.sh
```

## Design rules

Clearance 0.127 mm, min track 0.127, default track 0.16, via 0.45/0.25 (min 0.40/0.20),
hole-to-track 0.175, hole-to-hole 0.30, solder-mask expansion 0.051, thermal spoke 0.254 /
gap 0.152. Net classes: `gnd` (GND, 0.13 track), `3v` (VCC, VDDA, 0.20), `5v` (VBUS, BAT+,
BAT_CELL, VSYS, SW_SYS, SW1, SW2: 0.254 track, 0.5/0.3 via). Copper-to-edge 0.30 mm.
Silkscreen minimums are JLCPCB's: 1.0 mm text height, 0.15 mm line width. The only custom
rule is in `openrz67.kicad_dru` (hole clearance around USB1's two locating-peg holes).

## Accepted warnings

ERC and DRC both have **0 errors**. The warnings below are known and left in the reports
rather than silenced, so a genuinely new one stands out. No exclusions are configured.

| Check | Count | What |
|---|---|---|
| ERC `endpoint_off_grid` | 15 | The redrawn charger section sits on whole millimetres, not the 1.27 mm grid. Cosmetic; connectivity verified by netlist. |
| `courtyards_overlap` | 15 | Neighbours closer than 0.1 mm (USB1 corner, the U2/L3 power corner, R23 at U1, C32 at R24/R25, Q3 at BAT1/L3, C24 at L3/U2). Pad-to-pad ≥ 0.16 mm everywhere. |
| `silk_over_copper` | 4 | L3's and U2's outlines cross C24's mask openings by 0.05 mm; the fab clips silk there. |
| `silk_overlap` | 1 | U2's pin-1 dot touches L3's outline (0.02 mm). |
| `text_height`, `text_thickness` | 2 | The `BOOT EN` label is 0.5 mm / 0.10 mm, under JLCPCB's minimum. There is no room to enlarge it without moving parts. |

## Mechanical

Outline 48 × 22 mm, R2 corners, mounting holes at (2, 20) and (46, 2). All components are
on top. Under-board clearance the enclosure has to provide, from the datasheets:

| What | Height below the board |
|---|---|
| BAT1, S3 and U4 through-hole tails | 3.4 mm unclipped |
| USB1 shell posts | ~1 mm |

The cell can only sit against the board if those tails are clipped flush.

## Revisions

| Rev | Status | Package |
|---|---|---|
| 1 | fabricated, working; LGS5500 charger replaced in rev 2 | `../archive/2025-09-23-rev1/` |
| 2 | fabricated 2026-09-07, **working** (the boards in use) | `../archive/2026-09-07-rev2/` |
| 3 | **source**, not yet fabricated | this directory |

Rev 3 over rev 2: routing fixes from the 2026-09-08 review, R23 pull-up on GPIO8, battery
voltage sense on GPIO3 (S2 drive moved to GPIO6, J1 shrunk to 1×3), Q3 reverse-battery
P-FET, C24 moved to the buck-boost output, paste windows on the exposed pads, RF line
0.8 mm. The full change-by-change record, with coordinates and the reasoning behind every
part choice, is in [`notes/revisions.md`](notes/revisions.md); the reviews that drove it are
the other files in `notes/`.

Still open, not blocking: one-via ground islands, 0.16 mm power necks at the U2/U3 pads,
the U3 mask dam, and a 1 µF on VDD_SPI (no room on top).

## Ordering

Fab notes: 2 layers, 1.6 mm FR-4, 1 oz copper, no impedance control, smallest via
0.45/0.25 mm (pick the 0.25 mm minimum-hole option if the form asks). No bottom-side
assembly. BAT1, S3 and U4 are through-hole: confirm the assembler's through-hole service or
hand-solder them. J1 is DNP and absent from the BOM and position file.

`tools/regen.sh` writes `out/openrz67-gerber.zip`, which is what you upload; it is tracked so
the fab-ready file is always in the repo. `out/gerber/` is tracked unpacked so copper diffs
in git. When a revision is ordered, copy the zip, BOM and position file into
`../archive/<date>-rev<n>/`.

The BOM and position file are written in JLCPCB's column layout, so they upload without
mapping. Gerbers, drill and position all use the aux origin at the board's top-left corner.
`ROT_FIX` in `regen.sh` adds +90° for U1 (QFN-32) and U5/U6 (SO-4) because JLCPCB's library
orientation for those packages is 90° off the KiCad footprint.

**Before confirming the order:** U1, U5 and U6 must look like `out/openrz67-top.png` in the
preview; check pin 1 of U2, U3, U5, U6, Q3 and BAT1 against the same render; then check the
DFM analysis in Order History (U1, U5, U6, X1, D3, D4).

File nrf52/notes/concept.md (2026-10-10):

# nRF52 trigger: concept

A from-scratch second design. Same job as the ESP32-C3 board (close S1 and S2 to the camera's
ground over BLE, controlled from the existing apps), but built around the one thing the current
design cannot do: live on a coin cell with no power switch, no charger and no regulator.

## What stays

- The GATT: service `c9239c9e-…`, command characteristic `458d4dc9-…`, battery mV characteristic
  `cda71ce6-…`, DIS 0x180A, BAS 0x180F. The apps do not change.
- Two TLP172AM PhotoMOS channels. Isolated, bidirectional, proven on the camera.
- The camera cable's camera end. The board end becomes a JST SH plug (see layout decisions).

## What goes

| Today | Why it is not needed |
|---|---|
| TPS63031 + 7 × 6.5 mm inductor + 6 × 10 µF | nRF52 runs 1.7–3.6 V straight off the cell |
| BQ25185, USB-C, NTC, reverse-battery FET, LiPo + JST PH | primary cell, replaced not charged |
| KCD11 rocker + SW_SYS divider | System OFF is ~0.5 µA; the button is the power button |
| Bare ESP32-C3 + 2 crystals + matching + U.FL + FPC antenna | module with ceramic antenna |
| VBAT divider | nRF52 ADC measures VDD internally |

## Board

- **MCU**: nRF52840 module with ceramic antenna. Candidate Ebyte E73-2G4M08S1C (13 × 18 mm, LCSC
  stock, JLC-assemblable). Smaller alternative Raytac MDBT50Q-1MV2 (10.5 × 15.5 mm, not at LCSC).
  nRF52840 over nRF52832 for the USB peripheral: not used now, free option for a USB-flash variant later.
- **Cell**: CR2032 in an SMD holder. 220 mAh, 20 mm. CR2450 (620 mAh, 24.5 mm) if the case
  can take it; same holder family, decide when the outline is drawn.
- **Outputs**: 2 × TLP172AM, LED resistor **330 Ω** (not 150 Ω): 5.2 mA at 3.0 V, 3.4 mA at
  2.5 V, still above IFT max 3 mA (TLP172AM datasheet §11, see `../../pcb/kicad/notes/review-2026-09-10-verify.md` 4.2).
  Nominal IF 5 mA is the RON ≤ 2 Ω test point. Camera GND stays separate from cell GND.
- **Bulk cap**: 100–220 µF across the cell. CR2032 internal resistance is 10–40 Ω and climbs
  with age; worst-case peak is 2 × 5 mA LEDs + ~6 mA radio TX at 0 dBm ≈ 16 mA ≈ 0.6 V sag at
  end of life. The cap carries the radio bursts; TX power stays at 0 dBm.
- **UI**: one button (B3U-1000P, as today), one 0603 LED.
- **Programming**: SWD pads (SWDIO, SWCLK, GND, VDD, RESET), Tag-Connect TC2030 footprint or
  five 1.27 mm pads. No USB on the device. Probe: a Raspberry Pi Pico running debugprobe
  (CMSIS-DAP) or a J-Link EDU Mini.
- **Size**: the holder sets it, roughly 26 × 30 mm, 2 layers. Module antenna end over the
  board edge, keepout per the module datasheet, cell holder at the other end.

## Power behaviour

| State | Current | Note |
|---|---|---|
| System OFF, button wake | ~0.5 µA | default state |
| Advertising, 30–60 ms interval | ~150 µA (estimate) | 5 min after a press or a disconnect, then OFF |
| Connected, idle, 30–50 ms interval | ~25 µA (estimate) | no timeout, lasts as long as the app holds the link |
| Shutter held | 5 mA per channel | 1 min bulb = 0.1 mAh |

A press wakes it and it advertises for 5 min. Once the app connects the timer no longer
applies. After a disconnect it advertises for another 5 min so the app can reconnect
unattended, then goes back to OFF. A 5 min advertising window is 0.01 mAh, a whole day connected
is 0.6 mAh of 220; cell life is set by shelf life, not use. The fast intervals are the ESP32
firmware's values, kept so the apps behave the same; slowing them is a tuning item for later.

## Firmware

Zephyr via nRF Connect SDK (west + the VS Code nRF Connect extension). System OFF, advertising
timeouts, BAS and DIS are built in, and the Nordic BLE stack is the reference one. The
Arduino route (Adafruit nRF52 core) needs the Adafruit bootloader on the module and gives less
control of sleep. The command protocol is reimplemented 1:1 from `src/main.cpp`.

## Case

A new, much smaller box: cell holder, module and two PhotoMOS stacked in one layer, roughly
30 × 34 × 12 mm. Button through the lid, LED through a thin wall or a short pipe (glued, as
today). The lid comes off for the cell, so the snap closure must survive many cycles; the
press-fit walls on the current case are known to loosen. Cable exit through the wall at the
XH connector, as today.

## To verify before drawing

- E73-2G4M08S1C: JLC assembly class. (LCSC C356849, stock OK; Ebyte gives no keepout figure.)
- CR2450 clip variant, if the case wants the bigger cell.
- 100–220 µF in 1206/1210 at 6.3 V, or a tantalum.
- Actual TX current of the chosen module at 0 dBm with DC/DC enabled.
- Camera-side requirements in `../../case/notes/rz67-remote-inputs.md` still hold for 5 mA drive.

## Layout decisions (kicad/, first pass)

- **Board 27 × 29.** The clip's two feet span 25.9 mm, that is the width. The cell sits on
  the back, centred, 5 mm below the antenna end. (The first pass was 31 × 30 because of the
  17 mm wide XH connector.)
- **JST SH 1.0 mm (SM04B-SRSS-TB, C160404) instead of XH.** The user does not need the XH
  plug. XH side-entry is 7 mm tall and 17 mm wide with its tabs, SH is 2.9 × 6 mm, and SH
  4-pin is the Qwiic / STEMMA QT cable, so pigtails are everywhere. Pin 1 is camera ground
  so a Qwiic cable's black wire is ground. (The through-hole XH was never an option here:
  its tails would sit under the cell.)
- **Connector at the bottom edge, module at the top.** With the connector on the right edge
  there was no corridor for the SWD and drive traces between the module pads and the
  connector pads.
- **SWD on a second JST SH connector (`J2`)**, not Tag-Connect and not bare pads. The
  user does not want to solder: a Qwiic cable onto a Pico H is a zero-solder probe. Pin 1
  GND so the cable's black wire is ground, like `J1`. Reset is not brought out: pyOCD /
  J-Link reset the nRF52 over SWD. (Tag-Connect's locating holes did not fit anyway.) The
  mouth faces into the board, so flashing needs the lid off.
- **GPIO choice is dictated by the module footprint.** Only the outer pad rows can be
  routed on the top layer (the inner row is boxed in). Button on P0.30 (last pad of the left
  column), LED on P0.00/XL1 (first pad of the bottom row), S1/S2 on the NFC pins P0.09/P0.10.
  The module has no 32 kHz crystal, so XL1 is a free GPIO when LFCLK runs from RC.
- **Both clip feet are VDD** and tied together on the back layer below the cell pad; 100 µF
  sits at the right foot. Electrically redundant with the clip itself, but it keeps the
  netlist honest and puts the bulk cap at the cell.
- **Antenna keepout** is a rule area over the module's antenna end, both layers, 3.8 mm
  deep. Ebyte's manual gives no number; this is the module's own antenna length plus 1 mm.

## Case decisions (case/, first pass)

- **Board on a ledge, cell hanging below, component side up.** The button and LED must face
  the lid, and the cell only needs the board lifted out to be changed: lid off, base turned
  over, the board drops out. (The first pass had a Ø14 push-out hole in the floor; it went
  so the floor stays flat for velcro on the camera, as on the ESP32 case.)
- **Ledge stands on the floor.** Above `split_z - lap` the base wall is only its outer half,
  the lid tongue fills the inner half, so the first-pass ledge hung on the wall was two
  floating bodies in the STL. It is now a wall from the floor up, 0.2 mm inside the tongue.
  The same check found the lid tongue overlapping the base's full-thickness wall beside the
  plug opening (the tongue notch was narrower than the zone the base keeps); the notch now
  spans it. Both are module-level checks now: one body per part, no base/lid overlap.
- **Snap fingers moved to the side walls.** The back wall carries the plug opening, the
  front wall faces the antenna end; the ESP32 case's finger geometry is reused unchanged,
  which is why the wall stays 3.2 mm on a box this small.
- **Button as a cantilever tab in the lid**, not a separate cap: nothing to lose, no extra
  part, and ABS at 1.0 mm over an 8 mm tab flexes the 0.3 mm the switch needs. Untested.
- **No light pipe** (first pass; replaced, see below). A Ø1.6 hole 3 mm above a 0603 LED shows the light; a pipe can be glued
  in later if it is too dim. `D1` was moved 1.6 mm away from `SW1` on the board so the hole
  clears the tab's slot.
- **The clip feet are tied on the back layer outside the cell**, up at y = 6.5 and down the
  two side edges: the LED drive had to cross to the back to get under `J2`, and nothing but
  GND may lie under the cell (see the review fixes below).
- **Lid bosses sit on free copper, not on the board corners.** The module fills the
  front-left corner and `C1` + `J1` the back-right one; `J1` moved 0.7 mm and `C1` 2.8 mm
  on the board to free a spot.

## Review fixes (2026-10-04, before ordering)

A second-opinion review of the board and the firmware. Applied:

- **Copper-free ring under the cell rim** (`CELL_KEEPOUT`, B.Cu rule area, r 7.5 to 10.2 mm):
  the CR2032's + can wraps over the edge of its negative face, and the only thing between it
  and the back-layer copper was solder mask. Nothing but mask now sits under that rim; inside
  the ring the GND pour stays, it is the same potential as the cell face on it. The VDD loop
  that tied the clip feet at y = 10 ran under the cell and moved to y = 6.5.
- **GND vias on the back under the module** (6.0, 10.0), (20.8, 8.8), (21.0, 5.2), (7.0, 19.7):
  the VDD loop and the ring had cut the back pour into islands that the filler removed, so
  the module had no ground under it on the back.
- **PhotoMOS pins at high drive** (`NRF_GPIO_DRIVE_S0H1`): standard drive guarantees only
  about 2 mA at 3 V, the TLP172AM needs up to 3 mA; the 330 Ω asks for 5.
- **Advertising restarts from `recycled`**, not from `disconnected`: with one connection slot
  the object is still held in `disconnected()` and `bt_le_adv_start` returns -ENOMEM, which
  would have left the board unreachable until it slept.
- **Button on SENSE** (`sense-edge-mask`), not a GPIOTE channel, so the idle current while
  awake stays at the sleep figure.
- **PhotoMOS 3D model**: LCSC ships a 6-pin SOP model for C2152276; the board now uses the
  main board's `SMD-4_L3.7-W4.6-H2.2-LS7.0-P2.54` model, so the STEP export (and the case
  that reads it) sees the real 4-pin body.

Noted, not changed:

- **DC/DC regulator stays off.** It would halve the radio current, but it needs an inductor on
  the nRF52840's DCC pin, and that pin is inside the module. Ebyte's user manual (checked
  2026-10-04) lists DCCH (pad 25, "DC/DC converter output") but no DCC and says nothing about
  an inductor, so whether REG1 can run as DC/DC is unknown. First thing to try on hardware,
  with the probe attached: set `regulator-initial-mode = <NRF5X_REG_MODE_DCDC>` on `&reg1`
  and see if the chip stays up. Without the inductor the core rail collapses and it resets,
  which is harmless. The gain is about 10 µA connected and 70 µA while advertising, not a
  battery-life question for a 220 mAh cell.
- `J2` pin 2 is the cell voltage; a powered Qwiic device plugged in there with the cell in
  would charge it. There is no silkscreen room for a warning.
- `J1`'s mouth sits about 1.7 mm inside the board edge, so the plug reaches through the case
  wall; the case opening is sized for it.
- `S2_DRV` runs at y = 2.3 beside the antenna keepout, and copper fills the top-right corner
  from y = 0. Slight range cost at most; left as is.
- `BT1` on the back means two-sided assembly at JLCPCB (or hand-soldering the clip).
- The power table above was corrected to the intervals the code actually uses.

## Firmware decisions (firmware/, builds, not flashed)

- **Zephyr app with its own board** (`boards/openrz67/openrz67_nrf`), not an overlay on the
  nRF52840 DK: the pin map lives in one devicetree file next to the code, and `west build
  -b openrz67_nrf` says what it is.
- **GATT copied byte for byte** from the ESP32 firmware, including the legacy 1-byte and
  the 3-byte countdown commands, so both apps keep working.
- **Main loop sleeps as long as it can.** `next_wait()` wakes it for LED edges and the
  countdown only; idle and connected it wakes once a second. The radio runs on its own.
- **System OFF, not deep sleep with a timer**: the button's SENSE wakes the chip, nothing
  else needs to. Advertising runs 5 minutes after boot and after each disconnect.
- **No UART, no console** in the normal build; `debug.conf` adds RTT logging for a probe
  session. The board has no serial pins.
- **Battery from VDD** on the SAADC's internal channel, no divider. 2.5 to 3.0 V = 0 to
  100 % on the Battery Service, raw mV on the custom characteristic.

## Second review (2026-10-04)

Datasheet pass over every part (all pins and footprints matched) plus firmware and case.
Board changes:

- **No paste on the cell's negative pad.** A 10 mm paste disc reflows to an uneven dome with
  flux on the contact surface; ENIG alone is the contact.
- **`VBUS` (pad 27) to GND**, as in nRF52840 PS reference config 6 (supply on VDD, no USB).
  It floated before.
- **Two vias out of pads**: the VDD via sat in both `C1`'s pad and the clip foot, the GND via
  beside `SW1` in its pad. Both wick solder; they now sit beside the pads.
- **Flashing powers the board from the probe, cell out.** The Pico's SWD lines are 3.3 V; on
  a cell at 2.8–3.0 V that is past the nRF52's VDD + 0.3 V limit. With the cell out and the
  red wire on the Pico's 3V3, both sides run at 3.3 V.

Checked and left: P0.09/P0.10 are "standard drive, low frequency I/O only" in the PS; high
drive at DC works and is what the PhotoMOS needs. NFC pins leak up to 10 µA when at
different levels; both idle low. The 100 µF X5R is about 58 µF at 3 V and may leak up to
6 µA by spec; measure sleep current on the first board.

Case changes:

- **Board X mirrored.** `bx()` mapped board X straight into case X while board Y (down in
  KiCad) went toward the back wall: that is a mirror image, not a rotation. Tab, LED hole,
  plug opening and bosses sat over the wrong parts, and the tongue notch lets the lid on one
  way only. Every keepout used the same mapping, so no check saw it. Now `bx` mirrors, and a
  check pins the plug opening to the left half.
- **Button tab tip off the wall.** The tip ended 0.2 mm over the inner wall with 0.6 mm of
  air; the nub needs 0.45 mm (gap 0.3 + B3U travel 0.15), which at the tip is 0.6 mm. The tip
  now ends 0.35 mm inside the cavity (`tab_tip` 1.45).
- **Tab 0.8 thick, not 1.0.** At 1.0 the tab alone takes about 6 N to bend 0.45 mm, 8 N with
  the switch; at 0.8 it is about 5 N. The "0.3 mm the switch needs" above was 0.45.
- **Bosses checked against every top-side part** (footprint bounding boxes); the board-wide
  keepout cut them out, so only a few parts were seen before.

Firmware changes:

- **Long-press power-off waits for a steady release** (three 20 ms reads in a row). It
  stopped at the first released read; a bounce after that pulled the SENSE pin low and woke
  the chip straight out of System OFF.
- **Commands follow the ESP32's `handleCommand()` exactly**: only value 1 starts, `10`/`20` no
  longer cancel a countdown and `30` no longer ends a bulb exposure. The apps never send
  these, but the GATT is meant to be the same device.
- **GAP preferred supervision timeout 4 s** (`BT_PERIPHERAL_PREF_TIMEOUT`), the same as the
  update request; the default was 420 ms until that request goes out 5 s after connecting.

Left as is: a link lost during bulb ends in power-off after the 5 min advertising window,
which closes the shutter. The camera closes it after about 60 s on its own anyway.

## Light pipe (2026-10-04)

The bare Ø1.6 hole was replaced by a printed clear light pipe, the ESP32 case's top hat made
round. The LED top is 4.5 mm under the lid surface and the advertising blink is 40 ms, so
through a hole it shows only from straight above and is easy to miss in daylight. The collar
ends at the pipe's lower end, 0.8 above the board: only `D1` and `R3` (both under 0.6) are
under its ring, `J1`'s body is 0.4 away. `qidi-template.3mf` was rebuilt from the ESP32
case's template (identical print settings) with the objects renamed, so the pipe keeps its
plate 2 / clear filament / per-object profile.

## Cell change with the board in the lid (2026-10-04)

Users put in and change the cell themselves, so the board no longer drops loose out of the
base. Two hooks off the lid ceiling hold it in the lid, and the lid tongue is gone from the
back wall, so the cell slides out of the clip backwards. It cannot go forwards: it needs
14.5 mm of travel to clear the strap, and the front ledge stops it after 7.

Rejected:
- **Coin-twist hatch in the floor**: the clip loads sideways, and no top-loading CR2032 holder
  on JLC fits a 27 × 29 board (all are 28-33 mm tail to tail).
- **Glue the board to the lid bosses**: a broken case would scrap the board. With hooks the
  board comes out and a new case can be mailed.

The hooks hang from the ceiling, not off the tongue: on the tongue the barb would sit 1.6 mm
below the finger root, too stiff to spring 0.5 mm. From the ceiling the finger is 5.6 mm to the
barb, about 2.4 % strain, under the snap fingers' 3.3 %. They need 1.9 mm between the board's
side edge and the wall (was 0.4), so the case is 3 mm wider. The clip keepout was a full box;
the 3D model shows only the solder legs within 2.5 mm of the board, so the check is now strap
plus legs, and the hooks sit in front of the legs.

Untested: the hook click and release force, and the barb's flat face. It prints as a 0.7 mm
overhang, like the snap bead's retention face.

Polarity marking: the nRF52 has no reverse protection, and a cell put in upside down puts
-3 V on VDD. There is a "+" in the base floor under the cell and `CR2032  + SIDE OUT` on
B.SilkS in the strip between the front edge and the cell (`SILK` in design.py).

## Visual pass (2026-10-04)

- Lid text printed fuzzy. "TRIGGER" at 3.2 was too small for a 0.4 nozzle, and the 0.1 bold
  growth closed the counters in "OpenRZ67". Now 5.8 / 4.0 with 0.05 growth. 5.8 is the
  widest the lid allows: caps 4.4 mm, at the ~4.4 mm legibility limit for a 0.4 nozzle;
  lowercase is 3.0. DIN Condensed Bold would give 7.0 / 5.0 at the same width, but Futura
  keeps the ESP32 case's look. Avenir Next Condensed was in between; Futura Condensed
  ExtraBold breaks OCCT's offset. A diagonal text line gains nothing with two lines.
- The ESP32 case's rail added: from the left side into the LED seat. It cannot run past the
  LED as on the ESP32 case: the button tab sits on the same row.
- Base bottom edge got the lid's 1 mm chamfer; the button tab's free end got round corners.
- First-layer line width 0.5 -> 0.42 in `qidi-template.3mf`: the lid text is the first layer, and
  0.5 lines blurred it. It is a print-wide setting in QIDI/Bambu Studio (GCodeConfig), not per
  object, so the base and light pipe get it too. The textured PEI plate also roughens the text
  edges; no smooth plate on hand.

## Third review (2026-10-05)

- C2 -> CL05B104KO5NNNC (C1525, basic) and R3 1 kΩ -> 330 Ω (same part as R1/R2): one
  extended part and one BOM line fewer. The LED gets ~3 mA instead of ~1 mA.
- Firmware: 5 s watchdog, and a disconnect ends a bulb. Before, a hung loop or a lost link
  mid-bulb kept S1/S2 on until the cell was pulled.
- Case: module height 2.0 -> 3.1 (manual: 3.0 ±0.1). Only the lid keepout check uses it;
  it still passes and the meshes do not change.
- Kept as is: R1/R2 at 330 Ω. 220 Ω only helps a worst-case VF at an almost empty cell, and
  costs ~50 % more cell current per channel while the shutter is held. DC/DC off: cell life
  is set by shelf life, not use (see Power behaviour), so the saving is small and an LDO
  boots with or without the module's inductor.
- Cheaper parts checked: LTV-357T-C (C119091) for U2/U3 saves ~1.1 USD per board but conducts
  one way only; measure S1/S2 polarity on the camera first. No cheaper module fits without a
  new layout. Everything stays JLC-assembled, BT1 included.

## Reverse-cell block (2026-10-08)

- `Q1` AO3401A (C15127, basic, the main board's Q3 part and KiCad `SOT-23` footprint) between
  the clip and `VDD`: drain on the new net `VBAT` (both clip feet, the back loop, `C1`), source
  on `VDD`, gate on GND. Before, the "+" marks were the only guard and a cell put in upside down
  put −3 V on the module, a new assembled board. Q1 sits at (5.4, 21.3) rot 90 where the left
  foot's via fed the module; "SWD" moved to (4.3, 24.4) off its pads.
- `C1` stays at the clip, on `VBAT`: a ceramic takes −3 V, and moving it would cost a track
  across the cell rim ring.
- `J2` pin 2 is on `VDD`. With the cell in, the channel is on, so the probe's 3.3 V still
  reaches the cell: the README rule (cell out when the probe powers the board) stands.
- Rotation for JLC: none in `ROT_FIX`. The main board's Q3 with the same footprint matched the
  order preview on 2026-09-25 without one.
- Case: `Q1` added to the boss clearance list; all checks pass, meshes unchanged.

## Surface finish (2026-10-08)

ENIG is no longer a requirement in the READMEs. The argument was oxidation of the bare cell
pad, but tin's oxide film is thin enough that the clip pressure breaks through it, and the
user's other HASL boards show no trouble. Nothing measured says HASL fails here; ENIG stays an
option if the cell contact ever proves flaky.

## Module change: E73-2G4M08S1F / nRF54L15 (2026-10-09)

- Why: the S1F is about 2 USD cheaper per board at JLC (5.66 vs 7.63), 12 × 17.2 mm instead of
  13 × 18, and the nRF54L15 needs roughly half the radio current of the nRF52840 when its DC/DC
  runs (TX 0 dBm 4.8 mA, RX 3.4 mA vs 10.6 / 9.9 mA on the LDO). Nothing was ordered yet, so
  the change costs no extra test boards. USB, the reason for the nRF52840, was never used.
- Rejected: E73-2G4M08S1CX (same footprint, IPEX instead of an antenna), nRF52832/52810
  modules (28.7 mm long, or out of stock), a bare nRF54L15 (own RF design).
- Pins: the button must be on P0/P1, since P2 has no SENSE and cannot wake from System OFF.
  P1.04 on the left column; P1.02/P1.03 (NFC), P1.08 (CLK16M/EXTREF) and P1.11/P1.12 avoided.
  The outputs sit on P2 (P2.00, P2.04, P2.05), which faces the parts. Total GPIO current
  with both PhotoMOS and the LED on is about 14 mA, under the 15 mA the PS recommends.
- Layout: module at (7.0, 11.2), rot 0, antenna at the top edge. Its left column faces the
  board edge, so `VDD` (pad 9) and the button (pad 7) run down two tracks between the module and
  the edge. SWD comes off pads 11/12 in the order SWCLK, SWDIO, so `J2` pins 3/4 swapped to
  SWCLK/SWDIO; the other order crosses. Antenna keepout 15 × 5.3 mm. `SW1`, `D1`, `J1` and the
  case are unchanged; `J2` stays in place.
- DC/DC: the inductor goes on DCC, which the module does not bring out, and Ebyte does not say
  whether it is inside. The firmware reads `VREGMAIN.INDUCTORDET` at boot and enables DC/DC
  only when it is there.
- Crystals are in the module (the S1C had none): LFXO replaces the RC oscillator. Load
  capacitance unknown, DK values used. Check the 32 MHz frequency on the first board.
- Flashing: pyOCD ≥ 0.37 has the `nrf54l` target built in and erases a locked chip itself.
  The Pico debugprobe stays.
- Errata: 114 (SENSE + bouncing button, `latch-detect`), 30 (cold, HFINT calibration).
  Chip revision on Ebyte's parts unknown.
- No nRESET RC as in Ebyte's reference circuit: a reset pulse during power-on prolongs
  anomalies 100/103, and the internal pull-up holds it.
- Risk: new module (datasheet 2025-11), 144 in stock at JLC on 2026-10-08. No 3D model from LCSC or Ebyte;
  `kicad/tools/module_3d.py` draws a box from the manual's dimensions instead.

## Relay drive and module decoupling (2026-10-10)

From `kicad/notes/review-2026-10-10.md`.

- R1/R2 330 Ω -> 220 Ω (C25091, basic). The third review kept 330 Ω on typical figures; with
  the datasheet limits (VOH = VDD − 0.4 V, VF 1.4 V) 330 Ω drops below the TLP172AM's 3 mA
  IFT at about 2.8 V, well before a CR2032 is empty. 220 Ω gives 4.1 mA at 2.7 V and 3.2 mA
  at 2.5 V. The extra cell current only runs while the shutter is held, 3–4 s in normal use.
- R3 330 Ω -> 1 kΩ (C11702, basic): the LED shares Nordic's 15 mA recommended GPIO total with
  both relays. A fresh cell gives about 14 mA for all three. Costs one BOM line back.
- C3 100 nF at module pad 9, GND straight to pad 10, below the module's bottom-left corner.
  C2 sat 8.7 mm away at Q1 with about 20 mm of VDD track to pad 9; it stays for J2 and Q1.
- Open: bulb test at 4 s and 60 s with a used and a cold cell on the first boards.

## Updates over Bluetooth (2026-10-10)

- Why: flashing needs the lid off and the Pico on `J2`. MCUboot + SMP over Bluetooth makes
  the probe a one-time tool; later updates come from nRF Connect Device Manager on a phone.
- Rejected: USB-C. The nRF54L15 has no USB, so it needs a bridge chip, a 5 V to 3 V path that
  can never charge the CR2032, edge space on a 29.5 mm board and a case opening. Going back to
  the nRF52840 for its USB gives up the 2 USD and the half radio current that motivated the
  module change.
- Swap using move (NCS default on the nRF54L15), so a new image that never confirms falls
  back. MCUboot feeds the watchdog during a swap: NCS turns that off for the nRF54L15, but the
  app's 5 s watchdog may still run after the reset into the bootloader.
- Signing key outside the repository, passed at build time. The build falls back to MCUboot's
  public test key with a warning.
- Cost: 39 kB MCUboot, app 127 to 147 kB, RAM 26 to 45 kB. Each wake from System OFF goes
  through MCUboot, which checks the app's signature first; measure that on the first board.

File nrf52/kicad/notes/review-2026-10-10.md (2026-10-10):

# Review av nRF-boardet

> Status: relédrift (R1/R2 220 Ω, R3 1 kΩ) og lokal avkobling (C3 ved U1.9) er fikset,
> se `../../notes/concept.md`. Bulb-testen på 4 og 60 sekunder står igjen.

Dato: 2026-10-10. Grunnlag: arbeidskopien etter `456e1cb`, med U1-bytte i
`6eff6cd`. KiCad 10, 29,5 × 29 mm, to kobberlag, 14 komponenter.

Ingen pinoutfeil eller manglende forbindelser ble funnet i den nye U1-koblingen.
Relédriften har derimot for liten dokumentert margin ved lav batterispenning.
Jeg ville løst strøm- og avkoblingspunktene før produksjon. En prototype må
testes med et belastet, delvis utladet CR2032. Bulb brukes normalt i 3–4 sekunder,
med en absolutt bruksgrense på 60 sekunder oppgitt av brukeren.

## Funn

| Prioritet | Funn | Grunnlag og sikkerhet | Tiltak |
|---|---|---|---|
| P1 | R1/R2 på 330 Ω gir utilstrekkelig dokumentert innkoblingsmargin ved lav VDD. | Datablad og beregning. Høy sikkerhet om manglende garanti; faktisk svikt er ikke målt. | Dimensjoner relédriften for valgt minste batterispenning og temperatur. Vurder relé med lavere innkoblingsstrøm eller separat driver. |
| P2 | CR2032 må levere reléstrøm gjennom bulb, normalt 3–4 s og maksimalt 60 s; C1 dekker bare korte topper. | Skjema, firmware og ladningsberegning. Høy sikkerhet om belastningen; batteriets spenningsfall må måles. | Test 4 s og 60 s med brukt og kald celle. Behov for endring avgjøres av spenningsfall og reléfunksjon. |
| P2 | C2 er 8,65 mm fra U1 pad 9, med omtrent 20,13 mm VDD-spor mellom padsentrene. | Målt i rå PCB-fil. Høy sikkerhet. | Flytt eller legg til lokal avkobling ved pad 9, med kort forbindelse til pad 10/GND. |

### Reléstrøm og batterigrense

U2/U3 drives fra P2.04/P2.05 gjennom 330 Ω. Firmware velger `S0H1`.
Nordic spesifiserer VOH ≥ VDD − 0,4 V ved 3 mA i high drive fra 1,7 V,
og ved 5 mA fra 2,7 V. Det er spenningsgarantier ved angitt last, ikke en
hard strømbegrensning. [Nordic, GPIO Electrical Specification](https://docs.nordicsemi.com/r/bundle/ps_nrf54l15/page/_tmp/nrf54l15/autodita/gpio/parameters.elec_spec.html).

TLP172AM oppgir IFT maksimalt 3 mA ved 25 °C. Anbefalt LED-strøm starter på
5 mA; maksimal RON og switchingtider er også oppgitt ved 5 mA.
VF maksimalt 1,4 V er spesifisert ved 10 mA og brukes her som et konservativt
anslag ved 25 °C. Dette er ikke en full temperatur- eller toleranseanalyse.
[Toshiba, TLP172AM, side 3 og 5](https://toshiba-semicon-storage.com/info/TLP172AM_datasheet_en_20230522.pdf?did=36714&prodName=TLP172AM).

`IF = (VDD − 0,4 V − 1,4 V) / 330 Ω` gir:

| VDD under last | Beregnet IF per relé |
|---|---:|
| 3,0 V | 3,64 mA |
| 2,7 V | 2,73 mA |
| 2,5 V | 2,12 mA |
| 2,0 V | 0,61 mA |

Ved 2,5 V er det dermed ikke dokumentert margin til maksimal innkoblingsstrøm.
Omtrent 2,79 V gir 3 mA i denne beregningen, før motstandstoleranse, temperatur
og aldringsmargin. Typiske eksemplarer kan fungere ved lavere strøm.
`VBAT_EMPTY_MV = 2500` brukes til batteriprosent, men stopper ikke utløsning.
U1 kan derfor fortsatt kjøre og motta kommandoer etter at relédriften har
mistet innkoblingsmarginen.

Ikke reduser R1/R2 uten å kontrollere hele strømområdet. Nordic anbefaler
maksimalt 15 mA samlet vedvarende GPIO-strøm. To reléer og status-LED deler
denne grensen, og en mindre motstand øker også batteribelastningen.
Ved ny dimensjonering bør R3 økes slik at status-LED ikke bruker unødig strøm.

### Bulb og strømreserve

`open_shutter()` aktiverer S1 og deretter S2. Begge blir stående aktive gjennom
hele bulb-eksponeringen. Tiltenkt reléstrøm på 5 mA per kanal betyr omtrent
10 mA under eksponeringen, i tillegg til MCU, BLE og LED-blink.
Brukeren oppgir normalt maksimalt 3–4 sekunder og absolutt maksimalt 60 sekunder.
Dette er bruksforutsetningen for reviewen; håndheving av 60-sekundersgrensen
er ikke kontrollert i app eller firmware.

Ved 10 mA bruker reléene omtrent 0,011 mAh på 4 sekunder og 0,167 mAh på
60 sekunder. Varigheten gir dermed liten ladningsbruk per eksponering.
Det uavklarte punktet er spenningsfall under last, særlig med brukt eller kald
celle. Batteripunktet vurderes som P2 og et krav til prototypetest, ikke som en
påvist grunn til å endre strømforsyningen.

Selv en ideell C1 på 100 µF gir bare `C × ΔV / I = 5 ms` ved 0,5 V fall og
10 mA last uten bidrag fra cellen. Den kan ikke holde spenningen oppe gjennom
en eksponering på 3–4 eller 60 sekunder. Dette påviser ikke at CR2032
svikter; cellen leverer hoveddelen av strømmen. Test begge varigheter, og
kontroller reléenes innkobling og hold, samt laveste VDD under BLE-aktivitet.

C1 er Samsung CL31A107MQHNNNE, 100 µF ±20 %, X5R, 6,3 V.
Effektiv kapasitet ved DC-bias er ikke målt eller hentet fra bias-kurven;
beregningen over bruker nominell verdi. [Samsung komponentdata](https://product.samsungsem.com/cn/mlcc/CL31A107MQHNNN.do).

### Lokal avkobling

C2 ligger ved Q1 og J2, mens U1s VDD går rundt nedre venstre del av boardet.
Den bør derfor ikke beskrives som lokal avkobling ved modulen.
En ekstra 100 nF ved U1.9 med kort retur til U1.10/GND vil redusere sløyfen.
Vurder også en liten lokal bulk-kondensator; nødvendig verdi må avklares mot
modulens interne avkobling og belastningstest. Modulens interne komponenter
er ikke kartlagt i denne reviewen.

### SWD

| J2 | Signal |
|---|---|
| 1 | GND |
| 2 | VDD |
| 3 | SWCLK |
| 4 | SWDIO |

Dagens skjema, PCB og README er enige. Boardet har aldri vært produsert,
så tidligere pinout gir ikke noe kompatibilitetskrav. SWD er godkjent i denne
reviewen. Det er ingen fysisk nRESET på J2.
Nordic støtter reset via CTRL-AP, og nRESET har intern pull-up.
[Nordic, Pin reset](https://docs.nordicsemi.com/r/bundle/ps_nrf54l15/page/chapters/power-and-clock/reset/doc/reset.html-pin_reset).

## Kontroll av komponenter og forbindelser

KiCad-eksportert XML-netliste ble sammenholdt med alle PCB-padnettene:
78 netlistede pads, inkludert NC-nett, ga 0 avvik. Antall komponenter er 14
i skjema, netliste og PCB; rå skjema-fil har dessuten tre PWR_FLAG-symboler.
Det finnes 15 tilkoblede nett og 29 NC-nett.

| Komponent | Kontroll | Resultat og begrensning |
|---|---|---|
| U1 | Alle 40 pinnavn, brukte nett og footprintorientering. | Samsvar med Ebytes pin-tabell. Pad 7 = P1.04, 9 = VDD, 11/12 = SWCLK/SWDIO, 18 = P2.00, 27/28 = P2.04/P2.05. Alle sju GND-pads er tilkoblet. |
| U1, firmware | GPIO-valg og wakeup. | Devicetree stemmer. Knappen bruker P1.04, som kan vekke fra System OFF. P2 brukes bare som utganger. |
| U2/U3 | Fysisk anode/katode og utgangsside mot Toshiba side 2. | Korrekt. Lokale padnumre 1/2/3/4 tilsvarer produsentens 1/3/4/6; ren nummerforskjell er ikke en feil. |
| Q1 | AO3401A, pinfunksjoner og body-diode mot AOS side 1. | G = GND, S = VDD, D = VBAT er korrekt for reverscellebeskyttelsen. Q1 er P-kanal. |
| J1/J2 | JST SH pitch, pinne 1, orientering og alle nett. | Samsvar med JST SH-katalog side 3 og PCB. J1.2 er NC; øvrige signaler er CAM_GND/S1/S2. |
| R1/R2/R3 | Verdier, footprint og begge padnett. | Alle 330 Ω, 0402, ingen intern avvik. Reléverdiene har marginproblemet over. |
| C1/C2 | Verdi, footprint, strømnett og polaritet. | 100 µF på VBAT, 100 nF på VDD. Begge keramiske og upolariserte. C2-plassering må forbedres. |
| SW1 | Knappenett og retur. | BTN til GND stemmer; fysisk produsenttegning ble ikke kontrollert. |
| D1 | Symbol- og PCB-nett. | Anode via R3, katode til GND. Fysisk KENTO-polaritetsmerking er ikke kontrollert mot datablad. |
| BT1 | Begge klipsføtter på VBAT og midtpad på GND. | Intern konsistens og kobberfri ring kontrollert. MYOUNGs mekaniske tegning og faktisk kontakttrykk ble ikke kontrollert på nytt. |

Ebytes nedlastingslenke merket E73-2G4M08S1F leverer nå en manual med navnet
E73-2G4M54LP(15). Pin-tabellen samsvarer med den opprinnelige produktsiden,
og måltegningen har samme 12 × 17,2 mm modul, padmønster og antenneretning.
Dette navneskiftet bør avklares mot konkret modul før endelig godkjenning av
footprintet. [Ebyte produktside og manual](https://www.ebyte.com/product/2769.html).
[Nordic portfunksjoner](https://docs.nordicsemi.com/r/bundle/ps_nrf54l15/page/gpio.html-concept_port_capabilities),
[AOS AO3401A](https://www.aosmd.com/pdfs/datasheet/AO3401A.pdf),
[JST SH-katalog](https://www.jst-mfg.com/product/pdf/eng/eSH.pdf).

## Strøm, layout og produksjon

Strømveien er `CR2032 → VBAT → Q1 → VDD → U1/J2`.
C1 er foran Q1, C2 etter. Reléinngangene returnerer til GND; reléutgangene
bruker CAM_GND. Det er ingen tilsiktet galvanisk forbindelse mellom
batterijord og kamerajord. Dette er lavspenningsisolasjon for funksjon,
ikke vurdert som sikkerhetsisolasjon for nettspenning.

- Antenne-keepout finnes på begge kobberlag, x = 0–15 og y = 0–5,3 mm.
  DRC finner ingen keepoutbrudd. RF-rekkevidde med batteri og kapsling er ikke målt.
- Alle 13 viaers kobberskiver ligger utenfor batteriets rim-bånd,
  r = 7,5–10,2 mm fra (13,5; 18). Midtpad for cellens minus har ingen paste.
- Strømspor på 0,25 mm er ikke en begrensning for den tiltenkte mA-lasten.
  Viaene er 0,45/0,25 mm med 0,10 mm annular ring. Dette møter prosjektets
  regler; fabrikkens aksept av disse dimensjonene er ikke kontrollert her.
- SW1 står med kanten omtrent 0,1 mm fra boardkanten. Det er en tilsiktet
  plassering, men panelisering og depanelisering må gi plass til knappen.
- Det finnes ingen dedikerte testpunkter. J2 gir tilgang til strøm og SWD;
  målepunkt ved U1-VDD vil gjøre feilsøking av spenningsfall enklere.
- Ved ekstern strøm på J2.2 kan Q1 lede tilbake til cellen. Kravet i README
  om å ta ut CR2032 før probe-strøm er fortsatt nødvendig.

## Kjørte kontroller

| Kontroll | Resultat |
|---|---|
| Ny KiCad DRC med schematic parity | 0 feil, 0 uforbundne pads, 0 parity-avvik. 11 advarsler gjelder BT1-silketrykk over minuspad. Første sandbox-kjøring krasjet; ny kjøring utenfor sandkassen fullførte. |
| Ny KiCad ERC | 0 feil, 17 off-grid-advarsler. Labels/netliste/parity kontrollert. |
| `analyze_schematic.py` | Kjørt; MPN på alle komponenter. Ingen lokal datasheet-cache i prosjektet. Kritiske deler kontrollert manuelt. |
| `analyze_pcb.py --full` | Kjørt; 14 footprints, 64 sporsegmenter, 13 vias, komplett routing. |
| `cross_analysis.py` | Kjørt; eneste funn var en ikke relevant VBAT-plane-advarsel. |
| `analyze_emc.py` | Kjørt; 13 heuristiske funn, gjennomgått under. Ingen målt EMC-vurdering. |
| `analyze_thermal.py` | Kjørt, men ingen kvantifiserbar Tj-vurdering: mangler modeller for faktisk dissipasjon. Ingen termisk godkjenning. |
| `analyze_gerbers.py` | Kjørt på eksisterende eksport. Kobber/mask/paste/silk/outline og begge drillfiler finnes; 13 hull. |
| `lifecycle_audit.py` | Kjørt; API-oppslag ga ukjent status for alle 10 unike MPN-er. Resultatet sier ingenting om EOL. |
| `diff_analysis.py` | Kjørt mot skjema før U1-bytte. Manuell gjennomgang av routing og J2-endringen i tillegg. |
| Deep review og `deep_review_gate.py` | Tre beregningsfunn passerte evidenskontroll, ingen quarantined-funn. |

SPICE ble ikke kjørt: ngspice, LTspice og Xyce ble ikke funnet.
Datablad ble lest manuelt; ingen strukturert ekstraksjonscache ble skrevet.
Det finnes ingen tidligere reviewrapport for nRF-boardet i repoet.
ESP32-reviewene gjelder et annet board og brukes ikke som godkjenningsgrunnlag.
Analyser, datablad og beregningsscript ligger midlertidig i
`/tmp/openrz67-review-20261010/`; tallene og relevante kilder er gjengitt her.

## Falske treff og reviewer-overstyringer

- PhotoMOS har ingen VCC-pin. Krav om avkoblingskondensator på U2/U3 forkastes.
- Keepout-analysen bruker bounding box og treffer hullet i batteriets ring.
  Geometrisk kontroll av hele via-kobberskiven og faktisk DRC gir ingen brudd.
- Manglende nRESET-pull-up er et falskt treff: Nordic har intern pull-up.
- VBAT er et strømnett med spor, ikke en referanseplane for signalretur.
  Plane-split-funnet er derfor ikke en layoutblokkering.
- CAM_GND skal være separat. Den skal ikke kobles til GND for å fjerne EMC-varsel.
- J1 har to aktive signaler, én kamerajord og NC-pad/mekaniske pads.
  Verktøyets «fem signaler per jordpinne» er misvisende.
- Plane-gap på det 1,8 mm lange LED_A-nettet gjelder en langsom status-LED.
  Det er ikke en kritisk EMC-feil. S1 bruker CAM_GND som retur.
- SWCLK ved SWD-kontakten er tilsiktet. SWD-kabel er et servicegrensesnitt.
- Få pasteåpninger på baksiden er korrekt: bare klipsføttene loddes;
  cellens minuspad og viaer skal ikke ha paste.
- Via i BT1s minuspad er ingen solder-wicking-feil siden denne pad-en ikke loddes.
  Kontaktflate og slitasje må likevel vurderes på fysisk prototype.
- Automatiske merker for Q1 som N-kanal og C1 som X7R forkastes mot produsentdata.

## Begrensninger og anbefalt neste steg

Det er ikke kjørt fysisk RF-/ESD-test, batteribelastningstest eller temperaturtest.
Kamerakabelens pinout og kamerainngangenes strøm/spenning er ikke målt på nytt.
Gerberne er analysert fra eksisterende eksport; de er ikke regenerert i reviewen.
Produksjonsrotasjonene er ikke validert i en ny assembly-preview.

U1-bytte og firmware-pinvalg ser konsistente ut. Prioriter reléstrømmen over
batteriets arbeidsområde og lokal avkobling ved U1.
Produksjonsgodkjenning krever at disse punktene avklares,
og at bulb-testene på 4 og 60 sekunder holder med brukt celle.

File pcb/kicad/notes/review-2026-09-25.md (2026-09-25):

# Review 2026-09-25: rev 3 source against industry practice

Question asked: is the board "as good as it gets", does it follow reference designs and
good practice? Reviewed with the kicad analyzers, ERC/DRC via kicad-cli, and the Espressif
ESP32-C3 hardware design guidelines, BQ25185 / TPS63031 datasheet layout sections, USB-C and
LiPo practice from memory (no `datasheets/` extraction in the repo). Verdict: electrically
sound and unusually well documented for a hobby board; the gaps below are the distance to a
commercial reference layout, not bugs. Rev 2 works; nothing here is a must-fix.

| Sev | Finding | Disposition |
|---|---|---|
| should | No ESD/TVS on USB-C D+/D−/VBUS/CC | **Accepted.** No room: the 0402 column (R4/R5/R9/R10) sits 0.4 mm from the USB pads and L3 / A1 close the corner above and below. The bottom side is 0.5 mm over the cell's foam and would need two-sided assembly. The C3's USB pins are ±2 kV HBM behind 22 Ω, D± only carry the `debug` build, and VBUS feeds the 20 V-rated BQ25185 IN through 10 µF. Revisit if the USB corner is ever re-laid out (a SOT-23-6 USBLC6-2SC6 in flow-through between the pads and the resistors). |
| should | RF line ~60 Ω (0.5 mm coplanar, 0.127 gap, 1.6 mm FR-4) | **Widened to 0.8 mm** (~52 Ω, hand calculation) from the U.FL pad to C2. The 0.3 mm tail into pin 1 stays: nothing wider fits between 0.5 mm pitch pads, and 7 mm total is ≈ λ/10. |
| should | π-match at the U.FL end, 5 mm from LNA_IN, values untuned | **Accepted.** Moving C1/L1/C2 next to pin 1 means re-laying the strip past C15/C4 and the VCC via. Values are Espressif's placeholders; tuning needs a VNA. Range is verified good in use. |
| should | TPS63031 output cap 5 mm from VOUT (pin 1) | **Fixed.** C24 to (134.15, 95.9), VCC pad 0.8 mm from pin 1, return GND via beside its GND pad. (First cut went next to pin 10 = FB; PR review caught it.) |
| should | BQ25185 IN/SYS/BAT caps 5–10 mm from the pins | **Accepted.** Linear charger: no switching loop, the 10 µF caps remain the transient sink. Moving three 0603 into the U3 corner means moving D3, the ISET/ILIM parts and the STAT2 route. |
| should | Battery input unprotected (reverse polarity, no fuse) | **Fixed for polarity:** Q3 AO3401A P-FET reverse-battery block, `+` on the top silk. No fuse/PTC: the cell's own PCM covers overcurrent, and there is no room for a 1206 PTC in the BAT+ path. README already requires a protected cell. |
| should | Bottom silk said `v2` | **Fixed** (`v3`). |
| should | Schematic note said S2 = GPIO3 | **Fixed.** |
| should | 0.4/0.2 via (JLCPCB surcharge); 0.10 mm annular rings board-wide | **Via fixed** to 0.45/0.25 at (144.605, 104.295). **Rings accepted:** 0.45/0.25 is what rev 1 and rev 2 were fabricated with and is the no-surcharge floor. |
| nice | CHIP_EN RC 11 mm from pin 7 | **Accepted.** The strip below the pad row (GPIO2, 32K_N, VBAT_SENSE) has no 0402 slot. |
| nice | EP paste 100 % with untented vias | **Fixed.** U1 four windows (66 %), U2/U3 85 % area. |
| nice | Still-open README items (VDD_SPI 1 µF, BAT1 `+`, U3 mask dam, power necks, one-via islands) | `+` done, the rest still open. |
| nice | No test points or fiducials | **Accepted.** JLCPCB adds panel fiducials; the bottom faces the cell, the top is full. |
| nice | No fab notes / stackup statement | **Added** to the Ordering section. |

Analyzer output dropped as false positives: "no MPNs" (they are in `Manufacturer Part`),
"U2 VIN has no DC path" (through S3), "VBAT_SENSE no source" (divider tap), "missing pull-up"
on STAT1/STAT2/TS (open-drain / NTC), one-via GND islands (DRC: 0 unconnected), courtyard
edge-distance warnings (copper-to-edge 0.3 passes).

Result: DRC 0 errors / 16 warnings (13 courtyard, 1 silk, 2 text; 2 new courtyard from Q3, 1
gone with C24), ERC 0 errors / 15 warnings (unchanged), schematic parity clean.

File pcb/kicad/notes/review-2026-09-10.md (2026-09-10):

# Designgjennomgang 2026-09-10: nåværende KiCad-brett mot rev 1 (EasyEDA)

Metode: 10 uavhengige gransker-agenter (lader, buck-boost, ESP32-kjerne, PhotoMOS/kamera, USB, bibliotek/pinkart,
layout/DFM, strømbudsjett, rev 1-delta, friske øyne) med datablad for BQ25185, TPS63031, ESP32-C3 (datablad +
HW-guidelines), 40 MHz-krystall, JST PH, TLP172AM (hentet fra Toshiba underveis). Skeptiker-runden (to motlesere per funn)
og samle-agenten falt ut på tokenkvote. Funnene under er derfor **ikke motlest av en andre agent**; de tre viktigste
(GPIO8, VDD_SPI, X2 på GPIO0/1) er kontrollert manuelt mot schematic.json og databladteksten og stemmer.
Analyse-JSON fra kicad-skillen (schematic/pcb --full/gerber/cross/thermal) ble brukt som spor, ikke som fasit.

## 1. Konklusjon

- **Brettet fungerer.** Ingen funn sier «virker ikke». Alle pinkart (U1, U2, U3, U5/U6, USB1, U4, BAT1/S3, LED-er, krystaller)
  er verifisert mot datablad eller mot rev 1-kobber som er bygget og virker. Ladestrøm, buck-boost-komponenter, USB-CC,
  AGND-isolasjon og firmware-pinner stemmer.
- **Klart for neste bestilling? Nesten.** Tre små schematic-endringer bør inn først, alle billige 0402-deler som allerede er i BOM:
  1. **10 kΩ pull-up på GPIO8** (U1 pinne 14 er i lufta). Uten den er BOOT+EN-nødprosedyren et myntkast. Arv fra rev 1.
  2. **1 µF på VDD_SPI** (U1 pinne 18 er i lufta). Espressif anbefaler den for innebygd flash. Arv fra rev 1.
  3. **Bestem X2 (32,768 kHz).** Firmware bruker den ikke, og den opptar GPIO0/GPIO1, de eneste frie ADC-pinnene.
     Fjern X2/C30/C31 og legg en batterispenningsdeler på GPIO0, så kan firmware varsle før BQ25185 kutter ved 3,0 V.
- **Viktigste ikke-PCB-funn:** firmware har ingen lavstrømstilstand mens S3 er på. BLE annonserer kontinuerlig, ~40–70 mA,
  dvs. 3,5–6 timer på 250 mAh uansett bruk. Maskinvaren støtter dyp søvn. Dette bør måles på rev 2-prototypen først.
- **Rev 2-brettene som er i posten** er commit 0e1376e og mangler alle 2026-09-08-fiksene (U2/U3 EP-vias, C23-flytting,
  GND-halser, GPIO21-omlegging, pin-1-prikker). BOM/CPL er like (unntatt C23-posisjon), så monteringen påvirkes ikke.

## 2. Bør fikses før neste bestilling

| Id | Hva | Hvor | Bevis | Fiks |
|---|---|---|---|---|
| U1-01 / FE-1 | GPIO8 strapping-pinne flyter | U1 pinne 14, ingen nett | ESP32-C3 DS tabell 3-1: GPIO8 default «Floating»; tabell 3-3: Joint Download Boot krever GPIO8=1. esptool via USB-Serial-JTAG tvinger download uavhengig, derfor har det virket. | 10 kΩ 0402 (C25744, samme som R6/R7/R8) fra pinne 14 til VCC |
| U1-02 / FE-2 | Ingen 1 µF på VDD_SPI | U1 pinne 18, ingen nett | HW-guidelines 1.3.2: «add a 1 µF capacitor close to VDD_SPI». FH4 driver intern flash via RSPI 7,5 Ω. | 1 µF (C15849, i BOM) fra pinne 18 til GND med egen via |
| U1-03 / FE-3 / PWR-02 | X2 ubrukt, blokkerer ADC1-pinner, ingen batterimåling | X2, C30, C31 på GPIO0/1 | sdkconfig i framework: RTC_CLK_SRC_INT_RC, PM_ENABLE av; main.cpp har ingen sleep/RTC-kode. BQ25185 BUVLO 3,0 V m/ 150 mV hysterese gir boot-loop på tom celle. | Fjern X2/C30/C31; 2×1 MΩ + 100 nF fra VSYS til GPIO0 |
| DELTA-01 | Bestilte rev 2-brett mangler 2026-09-08-fiksene | archive/2026-09-07-rev2 vs out/ | Gerber-diff F_Cu 2949 linjer, B_Cu 1260; archive drc.rpt har 4 starved_thermal. | Test de mottatte brettene med det i mente; ikke oppdater archive/ før neste bestilling; evt. git-tag 0e1376e |
| L-01 | Østre tredel av B.Cu-GND henger på 0,26 mm bånd | B.Cu y 0,31–0,56, x 25,75–32,0 (brettramme) | Erosjonstest: 0,14 mm/side deler planet i 115 + 363 mm². 12 vias binder østblokken til F.Cu, så elektrisk OK. Samme klasse som halsen som ble fikset under U1. | Flytt B.Cu VCC-løpet ved y≈0,7 0,3 mm sør, eller to GND-vias ved (33,0, 1,0) og (33,5, 17,9) |
| TPS-01 / TPS-02 | C24 (eneste 10 µF på VOUT) 6,5 mm unna, ingen returvia; 0,16 mm halser i pinne 1/5/10-utganger | U2, C24 (19,3, 6,5) | SLVS696D 9.2.2.3.3: Cout så nær VOUT/PGND som mulig. 0,16 mm bærer ~0,5 A topp (IPC ~0,6 A), under 5v-klassens 0,254. | C24 på pinne 1-siden ca. (15,4, 6,3) med egen GND-via; 0,254 mm utganger; via på C23 pad 2 ned på B.Cu SW_SYS |
| L-02 | U3 maskedam 0,098 mm < JLCPCB 0,10 | U3 pads 1–10 | 0,20 gap − 2×0,051 ekspansjon. Kjent i README. | Lokal maskemargin 0,04 mm på U3s ti signalpads |

## 3. Bør vurderes (minor)

| Id | Hva | Kommentar |
|---|---|---|
| PWR-01 | Ingen lavstrømstilstand mens S3 er på (3,5–6 t batteritid) | Firmware/framework, ikke PCB. Mål aktiv strøm på prototypen først. |
| CHG-1 | D3-tolkning i README er ufullstendig | STAT2 lav også ved låst feil (safety timer 6 t); blinker uten batteri. Rett README, evt. STAT1 til GPIO6/J1. |
| CHG-3 / FE-4 / PWR-03 | R16 NTC 3,2 mm fra U3 måler laderens egenvarme; >67 °C tolkes som knappetrykk → factory mode-fall | Trip ~1 °C / ~59 °C ved brettet. Flytt R16 mot BAT1, eller fast 10 kΩ. Dokumenter. |
| U1-04 / SH-3 | GPIO3/GPIO4 har 10 mA default drivstyrke, LED-sløyfa vil ha 8–13 mA | DS tabell 2-1 fotnote 4. `gpio_set_drive_capability(..., GPIO_DRIVE_CAP_3)` i setup(); null BOM-kostnad. |
| L-04 | To GND-øyer med én via (68 mm² B.Cu, 56 mm² F.Cu) | Kjent i README. Én via hver til. |
| SH-1 | AGND/GND-gap er bare 0,127 mm (pour-clearance) | Elektrisk harmløst ved 6 V, men isolasjonen er «på papiret». Regel i .kicad_dru: AGND clearance 0,5 mm. |
| SH-2 / FE-6 / USB-1 | Ingen TVS på S1/S2/AGND eller USB | TLP172AM VOFF 60 V, ESD-følsom. Valgfritt: én bidireksjonal TVS per linje på AGND-øya. USB: rev 1 hadde heller ingen. |
| CHG-2 / USB-2 | IN/SYS/BAT-kondensatorer 5–11 mm fra U3 | Lineær lader, tåler det. Ved neste respin: C22 nær pinne 1, C20 nær pinne 10. |
| U1-08 | CHIP_EN RC 17 mm og to vias fra pinne 7 | Guideline vil ha kort spor. 100 nF rett ved pinne 7. Arv fra rev 1, ingen kjente resets. |
| U1-05 / U1-06 / U1-07 | RF-spor ~69 Ω (ikke 50), pi-match utenfor Espressifs område, 15 pF gir CL ~10 pF mot 12 pF | Alt arv fra rev 1, som fungerer på BLE. Mål TX-tone-offset før du endrer. |
| TPS-03 / TPS-05 | Power-save-rippel på VCC (ingen PWM-valg), én derated 10 µF på inngangen bak S3-ledninger | Mål rippel og BLE-sensitivitet på prototypen. |
| FE-5 | BOOT/EN ikke tilgjengelig med lukket kabinett | To Ø1,5 mm hull i lokket, eller noter i README. |
| PROC-01 | Bibliotek ikke beskåret som README sier | 6 symboler, 3 footprints, 4 .wrl (LGS5500, ME6211, R12, S2B) ligger igjen. |
| PROC-02 / L-11 / FE-8 / PROC-04 | Stale tekst | README mangler plassering av nye power-corner-deler; J1-GND-tekst; B.SilkS «5V/NC» på U4 pinne 1 (er ~6 V); schematic-note «ledPin = D7»; R20 Datasheet-URL peker på 10 k-delen; tittelblokk-dato. |
| LIB-03 | BAT1-polaritet har ingen «+» på silk | Kjent i README. |

## 4. Sammenlignet med rev 1

**Forbedret:** ladestrøm 1 A → 111 mA (cellen tåler 120); VCC holder 3,3 V ned til 3,0 V i stedet for LDO-sag; relé (67 mA
spolestrøm, 5,2 mm høy) → PhotoMOS (2,2 mm, ~10 mA); S1 flyttet fra GPIO21 (U0TXD, høy under boot) til GPIO4; C5 flyttet til VDDA
(før var VDDA udekoplet); J1 GPIO-header for logging; U2/U3 EP-vias, GND-halser og GPIO21-løp fikset (i kilden, ikke på de bestilte brettene).

**Regresjon / ny risiko:** PhotoMOS-utgangene er halvledere (60 V, ESD-følsomme) der reléet var passivt metall (SH-2);
switching-regulator gir rippel/EMI som LDO-en ikke hadde (TPS-03); TS/MR-factory-mode-fallen finnes ikke i rev 1 (FE-4);
ny 0,26 mm GND-hals langs S3-kanten (L-01).

**Uendret (arv):** GPIO8 flytende, VDD_SPI udekoplet, X2 ubrukt, RF-spor/matching, CHIP_EN-plassering, USB uten ESD, ingen
sikring på BAT+, USB1/U1/BAT1/S3/X1/X2/D3/D4/A1/L3/S1/S2-footprints identiske med rev 1-kobber.

## 5. Verifisert OK (fra granskerne, én linje per sjekk)

### Shutter output stage U5/U6 TLP172AM, LED drive R21/R22, camera connector U4, AGND isolation, firmware sequencing; comparison with rev 1 relay stage

- TLP172AM datasheet (Toshiba Rev.11.0.A, 2026-04-07, fetched via WebFetch, text+page renders in scratchpad/work/tlp172am.*): pin 1 anode, 3 cathode, 4 drain, 6 drain; internal circuit is two source-connected MOSFETs with body diodes -> output is bidirectional, no polarity constraint on S1/S2 vs AGND.
- Symbol->footprint->package map: openrz67.kicad_sym TLP172AM pins 1=A, 2=K, 3=D, 4=D; footprint pads 1 (3.5,1.27), 2 (3.5,-1.27), 3 (-3.5,-1.27), 4 (-3.5,1.27); datasheet top view has pin 1 across from pin 6 and pin 3 across from pin 4, rows 7.0 mm apart, 2.54 pitch -> pad1=pin1 anode, pad2=pin3 cathode, pad3=pin4 drain, pad4=pin6 drain. LED pair and output pair each on one row; no mirroring.
- Package dimensions vs footprint: lead span 7.0+/-0.4 (pads centred +/-3.5), pitch 2.54+/-0.25 (pads +/-1.27), body 4.55 x 3.7 (silk 4.6 x 3.6), lead width 0.4 / foot >=0.5 under 1.5 x 0.8 pads. Pin-1 dot (F.Fab 1.7,1.25; F.SilkS 3.5,2.2) sits at pad 1, matching the datasheet's marked corner.
- Board placement (board frame, aux origin 120,90): U5 (36.5,14.4) and U6 (36.5,7.6) rot 180 -> pad 1 (anode) at x=33.0, pad 2 (cathode, GND) at x=33.0, pads 3/4 (AGND, S1/S2) at x=40.0. Track ends confirm: Net-(U5-A) ends (33.0,13.13), S1 starts (40.0,13.13); Net-(U6-A) ends (33.0,6.33), S2 starts (40.0,6.33). out/openrz67-top.png shows both dots on the west (LED) side. LED side lies in the GND domain (AGND pour starts x=34.6), output side in the AGND island.
- Schematic netlist (analysis/schematic.json): U5 A<-R21<-S1_DRV (U1 pin 9 MTMS/GPIO4), U5 K=GND, U5 D3=AGND, U5 D4=S1->U4 pin 3; U6 A<-R22<-S2_DRV (U1 pin 8 GPIO3), U6 K=GND, U6 D3=AGND, U6 D4=S2->U4 pin 4; U4 pin 2=AGND, pin 1 no-connect. ESP32-C3 datasheet table 2-1 confirms pin 8=GPIO3, pin 9=MTMS=GPIO4.
- U4 pin order 1=BW(6 V, unused) 2=GND 3=S1 4=S2 matches notes/rz67-remote-inputs.md (repair manual p.104 fig.122) and is identical to the fabricated rev 1 EasyEDA PCB (PAD_NET rows: U4 pad2 AGND, pad3 S1, pad4 S2; K1 pads 3/4 AGND/S1, K2 pads 6/5 AGND/S2). Pin 1 is the square pad, at board (44.3,14.73), toward the switch edge.
- LED current: VF 1.1/1.27/1.4 V (IF=10 mA). Nominal 3.3 V, 150 ohm: (3.3-1.27)/150 = 13.5 mA (12.7 mA with VF max). Worst case VOH 0.8*3.3=2.64 V, VF 1.4 V, R +1%: 8.2 mA. Recommended IF 5-25 mA, trigger current IFT max 3 mA, abs max IF 30 mA, PD 50 mW (13.5 mA*1.27 V = 17 mW). All inside spec; RON 2 ohm max is specified at IF=5 mA, so 8.2 mA worst case keeps that guarantee.
- GPIO source capability: ESP32-C3 IOH 40 mA at PAD_DRIVER=3 (datasheet DC table); current is set by R21/R22, max 13.5 mA, no pin overload.
- Off-state / dynamics: IOFF 1 uA max at 60 V (typ 0.1 nA), COFF 20 pF typ, tON 2 ms max, tOFF 0.5 ms max. Firmware openShutter() writes S1 high, delay(10), S2 high -> 10 ms >> 2 ms tON; closeShutter() drops S2 then S1. triggerShutter() holds 100 ms. VOFF 60 V vs ~6 V camera rail; ION 500 mA.
- Boot state: src/main.cpp S1_PIN default 4 (rev1 env 21), shutterPinS2 = 3, matching the schematic. ESP32-C3 table 2-1: GPIO3 at reset IE only, MTMS at reset no pull, after reset IE; neither drives high, so both PhotoMOS LEDs are off until setup(). pinMode(OUTPUT) via gpio_config leaves the output register at 0 -> LOW. GPIO3/GPIO4 are not strapping pins (GPIO2/8/9 are). S1-on-GPIO21-at-boot from rev 1 is fixed.
- Isolation: AGND net members in schematic = U4 pin 2, U5 pin 3, U6 pin 3 (+PWR_FLAG). On the PCB the AGND net has those three pads, 30 AGND stitching vias, and F.Cu/B.Cu pours (bbox x 34.6-47.7, y 4.47-17.66). No track, via or footprint of any other net has an endpoint inside the AGND island (scan of pcb.json tracks/vias/footprints). Analyzer ground_domains: two domains, only U5/U6 bridge them (LED side GND, output side AGND) which is by design. No GND/AGND copper bridge.
- AGND island is separated from the GPIO header J1 (y=20.6) and from the mounting holes; U5/U6 GND cathode pads (x 32.25-33.75) are 0.85 mm from the AGND pour edge.
- DRC/ERC (out/drc.rpt, out/erc.rpt): no item mentions U4/U5/U6/AGND/S1/S2. BOM: U5,U6 TLP172AM C2152276; R21,R22 150 ohm C25082; U4 S4B-XH-A C157925. POS: U5/U6 rotation 270 after ROT_FIX (README documents JLCPCB's 90 deg library offset).
- Rev 1 -> current, gains: no coil current (relays gone), no contact bounce, 3750 Vrms isolation vs relay coil-contact, tallest part 5.2 -> 2.2 mm, 8 parts -> 4, S1 no longer on U0TXD (closed during boot log in rev 1).
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

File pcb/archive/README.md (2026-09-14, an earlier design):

# PCB archive

Frozen fabrication packages: exactly what was uploaded to the fab, one folder per order.
Nothing here is the source of truth and nothing here changes after the order; the live
design is the KiCad project in [`../kicad/`](../kicad/). Whether a revision turned out to
work is a status line in its section below, not a separate folder.

## `2026-09-07-rev2/`

**Status: fabricated, assembled and working.** Received and tested 2026-09-14: powers up on
USB and battery, advertises over BLE, fires the camera.

The fabrication package for **rev 2** (PhotoMOS relays, side-entry `U4`, BQ25185 +
TPS63031 power path, `J1` header), generated by `../kicad/tools/regen.sh` at commit
`0e1376e`. The boards do *not* have the pin-1 silk dots (`24bc07f`) or the routing
review fixes (`64ef2b8`, `4550987`: C23 at U2 VIN, opened GND necks, GPIO21 on one
layer, U3 EP vias) that are in `../kicad/` now; those go on the next order.

| File | What |
|---|---|
| `openrz67-gerber.zip` | Gerber and drill files, downloaded back from the JLCPCB order (identical to `0e1376e` apart from the header timestamp) |
| `openrz67-bom.csv` | BOM, downloaded back from the order; identical to `0e1376e` |
| `openrz67-pos.csv` | CPL, downloaded back from the order; identical to `0e1376e` |
| `openrz67-schematic.pdf` | schematic at that commit |
| `openrz67-top.png`, `openrz67-bottom.png` | renders |
| `drc.rpt`, `erc.rpt` | KiCad DRC/ERC at that commit (clean) |

## `2025-09-23-rev1/`

**Status: fabricated, assembled and working.** Its LGS5500 charger/boost was the reason
for the rev 2 power-path change.

The fabrication package for **rev 1**, exported from EasyEDA Pro on 2025-09-23. The enclosure in
[`../../case/`](../../case/) was first drawn against it; since 2026-09-05 it follows rev 2.

| File | What |
|---|---|
| `Gerber_…zip` | Gerber and drill files as ordered, including the board outline (`.GKO`) and `Drill_PTH_Through.DRL` |
| `BOM_…csv` | bill of materials as ordered |
| `PickAndPlace_…csv` | component placement as ordered; the source for the case's component positions |
| `3D_…step` | assembled board as STEP |
| `3D_…png` | render |

## `easyeda/`

The EasyEDA Pro project the KiCad port was made from, kept so the port stays
reversible.

| File | What |
|---|---|
| `ProPrj_…epro` | EasyEDA Pro **v2** export. This is the one that imports into KiCad; use it if the port ever has to be redone. |
| `ProPrj_…epro2` | EasyEDA Pro **v3** export. KiCad 10.0.6 imports this as an empty board, so it is kept for EasyEDA's own use only. |

The filenames carry spaces because they are the exports as EasyEDA produced them.
They are left unrenamed so they can be matched against the cloud project.

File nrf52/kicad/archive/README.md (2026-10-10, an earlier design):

# nRF board archive

Frozen fabrication packages: exactly what was uploaded to the fab, one folder per order.
Nothing here changes after the order; the live design is generated in [`../`](../).
Whether a revision turned out to work is a status line in its section below.

## `2026-10-10-rev-a/`

**Status: ordered, not received.** Two boards, JLCPCB Standard PCBA, assembly on both sides.
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

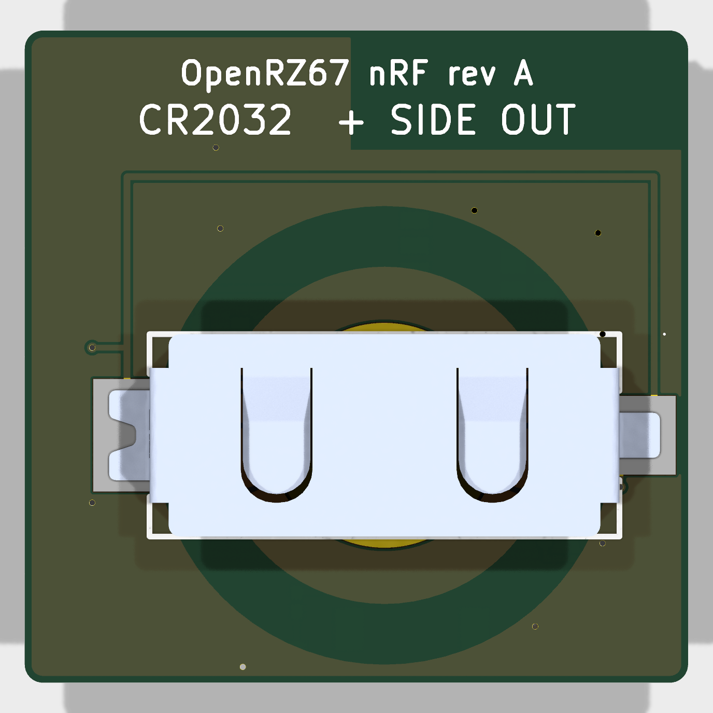
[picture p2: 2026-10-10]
nrf52/kicad/out/openrz67-nrf-bottom.png

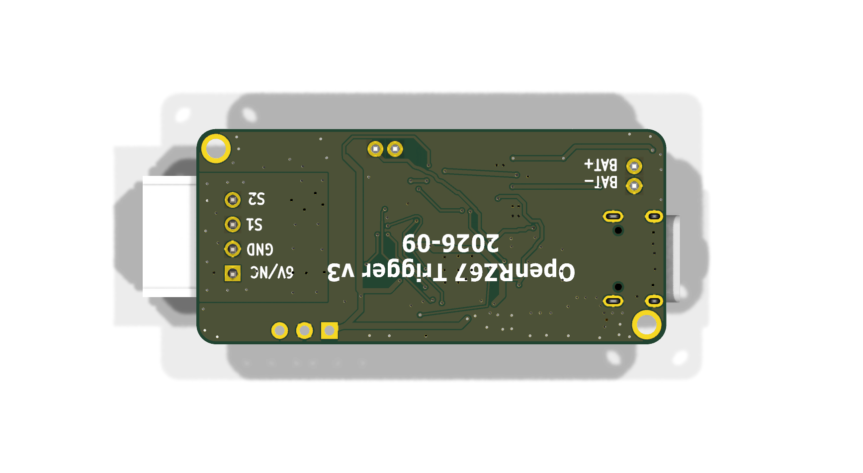
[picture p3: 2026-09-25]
pcb/kicad/out/openrz67-bottom.png

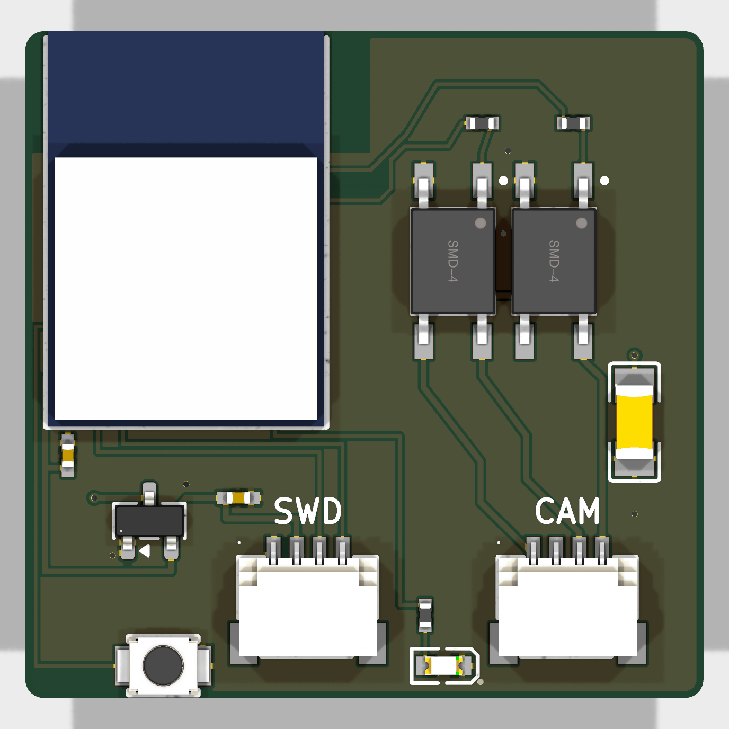
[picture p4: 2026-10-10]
nrf52/kicad/out/openrz67-nrf-top.png

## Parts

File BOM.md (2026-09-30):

# Off-board parts (external BOM)

Everything the trigger needs that is **not soldered on the PCB**. The on-board parts are in
[`pcb/kicad/out/openrz67-bom.csv`](pcb/kicad/out/openrz67-bom.csv). Mating connector part
numbers follow [`pcb/kicad/README.md`](pcb/kicad/README.md); case geometry follows
[`case/README.md`](case/README.md).

| # | Part | Spec | Qty | Mates with | Notes |
|---|---|---|-----|---|---|
| 1 | LiPo cell | 250 mAh, 3.7 V, **31 × 20 × 6 mm** (602030 size), with protection PCB, lead terminated in a **JST PHR-2** plug | 1 | `BAT1` (B2B-PH-K-S, top entry) | Lies flat under the PCB in the base pocket. Cell rated ≥ 120 mA charge (charger delivers 111 mA). Lead ~30–40 mm; longer leads must loop in the 2 mm air above the plug. |
| 2 | Power switch | **KCD11** snap-in rocker, SPST, panel cutout 13.5 × 8.5 mm, two 2.8 mm tabs | 1 | `S3` via wire | Snap-in from outside, no screws. Vendor drawings disagree by ~0.5 mm: measure the switch before printing the lid. |
| 3 | Switch lead | 2× **2.8 mm flag (90°) crimp receptacle**, 2× wire 26 AWG ~60 mm, 1× **JST PHR-2** housing + 2× **SPH-002T-P0.5S** contacts | 1 set | KCD11 tabs ↔ `S3` header | Flag type, not straight: a straight receptacle plus wire bend does not fit behind the switch. |
| 4 | Antenna | **Ebyte TX2400-FPC-2509**, 2.4 GHz FPC, 25 × 9 mm, 2 dBi, adhesive back, U.FL / IPEX-1 plug, ~100 mm cable | 1 | `A1` (Hirose U.FL-R-SMT-1(80)) | Stuck in the 25.6 × 9.6 × 0.3 recess in the lid ceiling. The board has no PCB antenna, so BLE works without this part but with much shorter range. Not MHF4/IPEX-4. Fallback: Molex 146153-0050 (34.9 × 9, 50 mm cable). |
| 5 | Camera cable, board end | **JST XHP-4** housing + 4× **SXH-001T-P0.6** contacts, wire 26 AWG | 1 | `U4` (S4B-XH-A side entry, mouth through the right wall) | Mated plug sticks ~2.5 mm past the mouth (estimate, `xh_plug_proud`). |
| 6 | Camera cable, camera end | 4× female **2.54 mm Dupont sleeves**, pushed onto the camera pins one by one and taped | 1 | Mamiya RZ67 RC outlet (Ø0.8 pins, 2.54 pitch) | Triangle-marked position = camera 6 V pin, wired through to `U4` pin 1, which the board leaves unconnected. Camera ground stays isolated from ESP32 ground. |
| 7 | USB-C cable | Any USB 2.0 C cable, plug shell ≤ 10 × 4.6 mm at the case opening | 1 | `USB1` | Charging and flashing. |
| 8 | Printed: base + lid | ABS (all fit numbers are ABS-measured); the lid text is a separate inlay part on filament 2 | 1 each | — | `case/stl/openrz67-base.stl`, `openrz67-lid.stl`. See [`case/README.md`](case/README.md). |
| 9 | Printed: light pipe | **Clear** filament, 0.28 mm layers, 100 % infill, slow | 1 | lid funnel seat | `openrz67-lightpipe.stl`. Glued in. |
| 10 | Glue | Clear CA or UV glue, one drop | — | light pipe | Optional: removable tack (Blu Tack) to hold the PCB on the pins during assembly. Never CA on the PCB or pins. |
| 11 | Bench only: J1 header | 1×3 2.54 mm pin header (3V3, GND, TX) on rev 3, 1×4 on rev 2 | 0 (DNP) | `J1` | Not fitted; the lid boss sits over it. Solder flying leads if needed. |

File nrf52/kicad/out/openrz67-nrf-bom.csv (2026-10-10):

Comment | Designator | Footprint | LCSC Part # | Manufacturer | MPN | Qty
CR2032 | BT1 | BAT-SMD_MY-2032-16 | C2902340 | MYOUNG | MY-2032-16 | 1
100uF | C1 | C1206 | C15008 | Samsung | CL31A107MQHNNNE | 1
100nF | C2,C3 | C0402 | C1525 | Samsung | CL05B104KO5NNNC | 2
LED | D1 | LED0603-RD | C2286 | KENTO | KT-0603R | 1
Camera | J1 | CONN-SMD_4P-P1.00_SM04B-SRSS-TB-LF-SN | C160404 | JST | SM04B-SRSS-TB(LF)(SN) | 1
SWD | J2 | CONN-SMD_4P-P1.00_SM04B-SRSS-TB-LF-SN | C160404 | JST | SM04B-SRSS-TB(LF)(SN) | 1
AO3401A | Q1 | SOT-23 | C15127 | Alpha & Omega Semicon | AO3401A | 1
220Ω | R1,R2 | R0402 | C25091 | UNI-ROYAL | 0402WGF2200TCE | 2
1kΩ | R3 | R0402 | C11702 | UNI-ROYAL | 0402WGF1001TCE | 1
B3U-1000P | SW1 | KEY-SMD_B3U-1000PM | C231329 | OMRON | B3U-1000P | 1
E73-2G4M08S1F | U1 | WIRELM-SMD_E73-2G4M08S1F | C54337734 | Ebyte | E73-2G4M08S1F | 1
TLP172AM | U2,U3 | SMD-4_L4.6-W3.7-P2.54-LS7.0-BR | C2152276 | TOSHIBA | TLP172AM(TPL,E) | 2

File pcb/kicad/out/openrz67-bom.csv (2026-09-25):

Comment | Designator | Footprint | LCSC Part # | Manufacturer | MPN | Qty
U.FL-R-SMT-1(80) | A1 | RF-SMD_FRF05002-JSS103M | C88374 | HRS(广濑) | U.FL-R-SMT-1(80) | 1
B2B-PH-K-S(LF)(SN) | BAT1,S3 | CONN-TH_B2B-PH-K-S | C131337 | JST | B2B-PH-K-S(LF)(SN) | 2
1pF | C1,C2 | C0402 | C277493 | YAGEO(国巨) | CC0402CRNPO9BN1R0 | 2
100nF | C3,C4,C5,C6,C7,C25,C32 | C0402 | C77020 | muRata(村田) | GRM155R71H104KE14D | 7
15pF | C8,C9 | C0402 | C441742 | muRata(村田) | GJM1555C1H150FB01D | 2
1uF | C14,C26,C29 | C0603 | C15849 | Samsung Electro-Mechanics | CL10A105KB8NNNC | 3
10uF | C15,C20,C21,C22,C23,C24 | C0603 | C96446 | SAMSUNG(三星) | CL10A106MA8NRNC | 6
18pF | C30,C31 | C0402 | C161534 | muRata(村田) | GRM1555C1H180FA01D | 2
KT-0603R | D3 | LED0603-RD | C2286 | KENTO | KT-0603R | 1
XL-1608UBC-04 | D4 | LED0603-RD_BLUE | C965807 | XINGLIGHT(成兴光) | XL-1608UBC-04 | 1
3.9nH | L1 | L0402 | C77109 | muRata(村田) | LQG15HS3N9S02D | 1
BLM15AG601SN1D | L2 | L0402 | C76884 | muRata(村田) | BLM15AG601SN1D | 1
2.2uH | L3 | IND-SMD_L7.1-W6.5-P5.60 | C76855 | TDK | SPM6530T-2R2M | 1
AO3401A | Q3 | SOT-23 | C15127 | Alpha & Omega Semicon | AO3401A | 1
22Ω | R4,R5 | R0402 | C25092 | UNI-ROYAL(厚声) | 0402WGF220JTCE | 2
10kΩ | R6,R7,R8,R23 | R0402 | C25744 | UNI-ROYAL(厚声) | 0402WGF1002TCE | 4
5.1kΩ | R9,R10 | R0402 | C25905 | UNI-ROYAL(厚声) | 0402WGF5101TCE | 2
2.7kΩ | R11 | R0402 | C25885 | UNI-ROYAL(厚声) | 0402WGF2701TCE | 1
18kΩ | R13 | R0402 | C25762 | UNI-ROYAL(厚声) | 0402WGF1802TCE | 1
NCP18XH103F03RB | R16 | R0603 | C13564 | muRata(村田) | NCP18XH103F03RB | 1
3kΩ | R18 | R0402 | C2909355 | FOJAN | FRC0402F3001TS | 1
1kΩ | R20 | R0402 | C11702 | UNI-ROYAL(厚声) | 0402WGF1001TCE | 1
150Ω | R21,R22 | R0402 | C25082 | UNI-ROYAL(厚声) | 0402WGF1500TCE | 2
1MΩ | R24,R25 | R0402 | C26083 | UNI-ROYAL(厚声) | 0402WGF1004TCE | 2
B3U-1000P | S1,S2 | KEY-SMD_B3U-1000PM | C231329 | OMRON(欧姆龙) | B3U-1000P | 2
ESP32-C3FH4 | U1 | QFN-32_L5.0-W5.0-P0.50-BL-EP3.7 | C2858491 | ESPRESSIF(乐鑫) | ESP32-C3FH4 | 1
TPS63031DSKR | U2 | VSON-10_L2.5-W2.5-P0.50-EP1.2x2.0 | C15516 | Texas Instruments | TPS63031DSKR | 1
BQ25185DLHR | U3 | WSON-10_L2.2-W2.0-P0.40-EP0.9x1.5 | C19725033 | Texas Instruments | BQ25185DLHR | 1
S4B-XH-A(LF)(SN) | U4 | CONN-TH_S4B-XH-A-LF-SN | C157925 | JST | S4B-XH-A(LF)(SN) | 1
TLP172AM | U5,U6 | SMD-4_L4.6-W3.7-P2.54-LS7.0-BR | C2152276 | TOSHIBA(东芝) | TLP172AM(TPL,E) | 2
TYPE-C 16PIN 2MD(073) | USB1 | USB-C-SMD_TYPE-C-6PIN-2MD-073 | C2765186 | SHOU HAN(首韩) | TYPE-C 16PIN 2MD(073) | 1
40MHz | X1 | CRYSTAL-SMD_4P-L2.0-W1.6-BL-2 | C20885029 | YJX(雅晶鑫) | T201640MFBDE2X | 1
32.768kHz | X2 | CRYSTAL-SMD_L3.2-W1.5-1 | C5213671 | YXC(扬兴晶振) | XKXGI-SUA-32.768K | 1

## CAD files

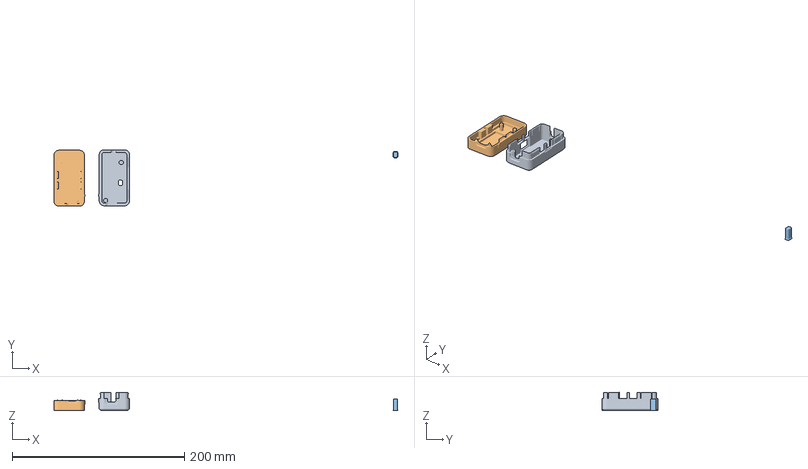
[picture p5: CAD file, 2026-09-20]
case/bambu-template.3mf
398.9 x 65.4 x 20.9 mm
openrz67-lid.stl
openrz67-base.stl
openrz67-lightpipe.stl

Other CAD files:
nrf52/case/qidi-template.3mf

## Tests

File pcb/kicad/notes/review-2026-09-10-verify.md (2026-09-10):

# Motlesing 2026-09-10: adversariell verifikasjon av review-2026-09-10.md

Metode: 6 motleser-agenter + verifikasjonsrunde på hver av dem (den runden originalen mistet på tokenkvote).
Hver rad i originalens seksjon 2 er regnet ut på nytt fra `pcb/kicad/openrz67.kicad_pcb`, `openrz67.kicad_sch`,
`openrz67.kicad_pro`, `openrz67.kicad_dru`, `openrz67.pretty/`, `openrz67.kicad_sym`, `out/gerber/`, arkivpakkene
og databladene — ikke lest ut av originalen. Verktøy: `kicad-cli` 10.0.6 (`/opt/homebrew/bin/kicad-cli`, samme binær
som `/Applications/KiCad/`) og KiCads egen `pcbnew`-Python for eksakte polygonbooleans. Datablad: ESP32-C3 DS v2.4,
ESP Hardware Design Guidelines (master, esp32c3), ESP32-C3-MINI-1 DS v2.2, TPS63031 SLVS696D, BQ25185 SLUSF65B,
TLP172AM Rev.11.0.A (Toshiba, 2026-04-07), JST ePH.pdf.

**Read-only:** ingen designfil er endret. Alle "hva skjer hvis"-tester (flyttet spor, innlagte vias, nye DRU-regler,
fjernede no-connect-flagg) er kjørt på kopier utenfor repoet. `git status` er uendret.

Denne fila **erstatter ikke** originalen; den sier hvilke rader som står, hvilke som faller, og hva som ble målt feil.
Der originalen og denne fila er uenige, gjelder denne — hvert tall her er reprodusert to ganger uavhengig.

## 1. Sammendrag

- **Ingen rad i seksjon 2 faller helt.** Alle sju identifiserer en reell egenskap ved brettet.
- **Tre fiksforslag er feil og må ikke gjennomføres som skrevet:** X2-deleren på VSYS (feil node, bryter
  strømbudsjettet i originalens §5), L-01s to GND-vias (måler 0,2610 mm hals før *og* etter — nullverdi), og
  L-01s 0,3 mm sørflytting av VCC (fysisk umulig, maks 0,170 mm).
- **Fire delpåstander er REFUTED:** «C24 er eneste 10 µF på VOUT» (C15 er også 10 µF på samme nett),
  «bare U3 er under maskedam-grensen» (USB1 pads 3–10 er på nøyaktig samme 0,098 mm, og brettets minste dam
  er 0,0655 mm ved U2/C25), «NTC-selvoppvarming kan nå knappetrykk-terskelen og felle brettet i factory mode»
  (HOT-trippen kutter varmekilden 8 K før), og originalens bevisledd for U1-04 («tabell 5-4 VOH 0,8×VDD
  spesifisert med PAD_DRIVER = 3» — tabellen har ingen slik betingelse; fotnoten sier høyimpedant last).
- **Ett nytt funn av samme klasse som seksjon 2:** J1s GPIO6-spor på F.Cu står **0,170 mm** fra AGND-pouren i to
  segmenter, altså trangere enn alt annet på brettet unntatt AGND↔GND selv — og `pcb/kicad/README.md:170-171`
  påstår eksplisitt at J1 ikke rører kameraisolasjonen. En AGND-regel skrevet som «AGND mot GND» lar den stå.
- **Originalen motsier seg selv ett sted:** linje 289 sier at arkivpakken «was not unpacked and diffed», mens
  DELTA-01s bevislinje (311) sier «diff of unzipped archive gerbers vs out/gerber». Konklusjonen holder uansett —
  diffen er nå faktisk kjørt.
- **DRC/ERC er kjørt friskt** og er bit-for-bit identisk med `out/drc.rpt` og `out/erc.rpt`. Sonefyllet i fila er
  ferskt (`--refill-zones --save-board` gir byte-identisk `.kicad_pcb`).
- **Minnenotatet om at 2026-09-08-fiksene er «uncommitted» er utdatert.** `24bc07f`, `64ef2b8`, `4550987` og
  arkiveringen `5f30622` er alle i `main`; det eneste usporede er selve review-fila.

## 2. Verdikt per rad i originalens seksjon 2

| Id | Verdikt | Hva står | Hva faller / må korrigeres |
|---|---|---|---|
| U1-01 / FE-1 | **CONFIRMED** | GPIO8 er eksplisitt no-connect i sch og har `unconnected-(U1-GPIO8-Pad14)` uten kobber i pcb. Fiks og del er riktig. | Bevis-kolonnen bør bytte kilde: HDG *anbefaler* ikke pull-up på GPIO8 spesifikt; grunnlaget er DS tabell 3-3 + HDG §1.3.10 + esptool-doket. «esptool tvinger download uavhengig» er for absolutt (HDG §1.5). Fiksen krever *to* schematic-endringer: motstand **og** fjerning av no-connect. |
| U1-02 / FE-2 | **CONFIRMED, styrket** | Pinne 18 er no-connect (`power_out`) og har ikke kobber. HDG §1.3.2 ordrett; Espressifs egen MINI-1 med samme FH4-brikke har C11 = 1 µF på pinne 18 (figur 8-1, s. 32). | «RSPI-fall 150–190 mV» er et statisk IR-fall en kondensator ikke fjerner — feil mekanisme, funnet er dekopling. C15849 er **0603**, ikke 0402. Plassen ved pad 18 er verre enn originalen tror (se §3.2). |
| U1-03 / FE-3 / PWR-02 | **Delt: «X2 ubrukt» CONFIRMED · fiksen REFUTED som skrevet** | X2/C30/C31 er ubestykket brukt: begge Arduino-pakkene på disk (3.20014 og 3.20017) har `RTC_CLK_SRC_INT_RC=y` og `PM_ENABLE` av. GPIO0/1 er de eneste frie ADC1-pinnene og er ikke strapping. | **VSYS er feil node** (oppstrøms S3 → 2,1 µA døgnet rundt, +35 % på originalens eget ≤ 6 µA-budsjett). VSYS er dessuten låst til 4,5 V med USB i. Boot-loop-en er *ikke* argumentet for en ADC. C30/C31 = 18 pF er **riktig** matchet mot X2. |
| DELTA-01 | **CONFIRMED** | Alle **fem** 2026-09-08-endringene mangler i arkivpakken, hver verifisert i `.kicad_pcb`. 4 `starved_thermal` bekreftet. BOM byte-identisk, CPL skiller i én linje (C23). | F_Cu er 2953 diff-linjer (ikke 2949); PTH.drl 19 uten tidsstempel (23 med). Av de fem via-koordinatene originalen tilskriver GPIO21 er to på nett GND, og en femte GPIO21-via er utelatt. Drill-deltaet er 10 nye / 5 fjernet / 2 flyttet. |
| L-01 | **CONFIRMED · begge fikser REFUTED** | Halsen er **0,2610 mm** konstant over 6,3 mm (x 25,75–32,06, y 0,3005–0,5615), reprodusert med to uavhengige metoder. 12 GND-vias binder østblokken; DRC 0 unconnected. | Fiks 1 (0,3 mm sør) gir **to** `shorting_items` mot S3 pad 1/2 + 2× `solder_mask_bridge`; maks lovlig flytt er **0,170 mm** → hals 0,427 mm. Fiks 2 (to GND-vias) endrer **ingenting**: hals og sonearealer identiske etter refill. |
| TPS-01 / TPS-02 | **Avstand CONFIRMED · «eneste 10 µF» REFUTED · konsekvens nedgradert** | 6,521 mm kobber U2.1 → C24.2, ingen parallell vei; nærmeste GND-via til C24s GND-pad er 2,866 mm; 0,16 mm-halsene finnes. SLVS696D §11.1 sier «must be placed as close as possible». | «6,5 mm» er *sporlengde*, ikke avstand (senter 5,064, kant 4,278). C15 er også 10 µF på VCC. `VCC` er netklasse `3v` (0,20 mm), ikke `5v`. IR-fall/varme er neglisjerbart — det som står igjen er induktans/EMI, som ikke kan lukkes uten skop. **Fiks 1 er ikke gjennomførbar**: (15,4, 6,3) er okkupert av BAT+-via og -løp. |
| L-02 | **Geometri CONFIRMED · «bare U3» REFUTED · alvorlighet nedgradert** | 0,400 − 0,200 = 0,200 kobbergap, − 2×0,051 = **0,0980 mm**, målt direkte i `out/gerber/openrz67-F_Mask.gts` (aperture D47, ti separate flash). Fiksen (margin 0,04 → dam 0,120) er aritmetisk riktig og innenfor TIs «0.05 MAX ALL AROUND». | Brettets minste dam er **0,0655 mm** (U2 pad 6 ↔ C25 pad 2, begge `SW_SYS`), og USB1 pads 3–10 ligger på samme 0,098 som U3. Det fabrikerte rev 1-settet hadde 0,0198 mm damer på samme USB1-rad og ett par sammensmeltede åpninger — JLCPCB bygde det. Risikoen er **loddebro på 0,4 mm pitch under montering**, ikke at fabben avviser fila. |

## 3. Detaljert motlesing

### 3.1 U1-01 / FE-1 — GPIO8

| Felt | Innhold |
|---|---|
| Verdikt | **CONFIRMED** |
| Schematic | `openrz67.kicad_sch:3200` `(no_connect (at 158.75 207.01) …)`. U1-instans `:5545` `(at 154.94 180.34)` rot 0 + symbolpinne 14 `GPIO8` `(at 3.81 -26.67)` = nøyaktig (158,75, 207,01). Strengen finnes én gang i fila — pinnen er **eksplisitt** NC-merket, derfor er ERC ren og vil aldri minne om funnet. |
| PCB | `openrz67.kicad_pcb:14489` pad `"14"` `(at 2.55 -0.75)`, footprint `(at 141.257 104.4195)` → brettkoordinat **(23,807, 13,669)**, net `unconnected-(U1-GPIO8-Pad14)`, netnavnet forekommer 1 gang i fila → ingen kobber. |
| Datablad | DS v2.4 tabell 3-1 «GPIO8 · Floating»; tabell 2-1 pinne 14 «At Reset: **IE**» (mot GPIO9 «IE, WPU»); tabell 3-3 «Joint download boot: GPIO2 1, GPIO8 **1**, GPIO9 0»; tabell 3-4 med `EFUSE_UART_PRINT_CONTROL = 0`: GPIO8 «Ignored». HDG tabell 5 «GPIO8 nr. 14 Reset 1», legende «1 – input enabled, in high impedance state». HDG **§1.3.10 GPIO**: «For unused pins in the high-impedance state without an internal pull-up or pull-down, it is recommended to add a pull-up or pull-down resistor …» — den dekker GPIO8 og er den HDG-hjemmelen originalen mangler. esptool-doket: «The strapping combination of GPIO8 = 0 and GPIO9 = 0 is invalid and will trigger unexpected behavior.» |
| Korreksjon til originalen | (a) «esptool via USB-Serial-JTAG tvinger download uavhengig» er for absolutt: HDG §1.5 sier «If the flash is empty, set the chip or module to Joint Download Boot mode», og at auto-download faller bort når applikasjonen slår av USB PHY — nøyaktig scenariet READMEs BOOT+EN-prosedyre skal berge, og som light sleep utløser. (b) Feilmodus er verre enn «kommer ikke inn i download»: låser pinnen lavt mens S1 holdes, er GPIO8 = 0 / GPIO9 = 0, som esptool kaller «invalid». (c) Fiksen krever at `no_connect`-flagget på `:3200` fjernes samtidig, ellers ERC-feil. |
| Kontekst | R6/R7/R8 = 10 kΩ (C25744, 0402) sitter allerede på GPIO9, CHIP_EN og GPIO2. GPIO8 er **den eneste** strapping-pinnen uten. Firmware rører ikke GPIO8 (`grep -rn "GPIO8\|GPIO_NUM_8" src/ README.md` → 0 treff), så en pull-up koster ingenting i drift. Ukoblet også i rev 1: `["PAD_NET","e579","14","","e95",0]` i `.epcb`. |
| Fiks-feasibilitet | Ikke kartlagt godt nok til å love. Originalens «pinne 17 / C29-området er ved siden av» og motlesningens første forslag «rut til pad 11» er **begge** tvilsomme: pad 11 (VDD3P3_RTC) ligger 1,50 mm unna i samme 0,5 mm-pitch-kolonne, med pad 12 og 13 imellom — et spor langs kolonnen er umulig. Nærmeste VCC-kobber er B.Cu-sporet (18,847, 12,293)→(23,727, 12,293), 1,378 mm fra pad 14. Avgjør med et faktisk layoutforsøk + DRC, ikke på papiret. |

### 3.2 U1-02 / FE-2 — VDD_SPI

| Felt | Innhold |
|---|---|
| Verdikt | **CONFIRMED, og styrket av Espressifs eget referansedesign** |
| Schematic | `openrz67.kicad_sch:3191` `(no_connect (at 176.53 186.69) …)`; symbolpinne 18 `VDD_SPI` er type **`power_out`** (`openrz67.kicad_sym:724-727`), derfor måtte flagget settes for å holde ERC ren. |
| PCB | `openrz67.kicad_pcb:14517` pad `"18"` `(at 1.25 -2.55)` → **(22,507, 11,870)**, net `unconnected-(U1-VDD_SPI-Pad18)`, 1 forekomst → ingen kobber. Pinnene 19–24 (SPIHD/SPIWP/SPICS0/SPICLK/SPID/SPIQ) er alle NC — **korrekt** for in-package flash og identisk med MINI-1-skjemaet. Bør stå i «Verifisert OK», ellers ser seks NC-flagg på rad ut som en glipp. |
| Datablad | HDG §1.3.2 *Power Supply → Digital Power Supply*, ordrett: «When the VDD_SPI outputs 3.3 V, it is recommended that users add a 1 μF capacitor close to VDD_SPI.» + Attention: «When using VDD_SPI as the power supply pin for the in-package flash …, the supply voltage should be 3.0 V or above». DS tabell 2-9: pinne 18 «Output: In-package and off-package flash»; tabell 5-3 R_SPI 7,5 Ω typ. **Referansedesign:** ESP32-C3-MINI-1 DS v2.2, figur 8-1 (s. 32), modulen bygget på ESP32-C3FH4: pinne 18 → **C11 1 µF → GND**, pinne 17 → C10 0,1 µF → GND. |
| Korreksjon til originalen | (a) «FH4 driver intern flash via RSPI 7,5 Ω» brukt som begrunnelse er feil mekanisme. 20–25 mA × 7,5 Ω = 150–188 mV er et **statisk** IR-fall som en kondensator på pinne 18 ikke fjerner; marginen er dessuten grei (3,3 − 0,19 = 3,11 V > DS-kravet 3,0 V). Funnet er dekopling/robusthet. Bytt bevis-kolonnen til HDG-setningen + MINI-1 figur 8-1 — det er langt sterkere. (b) C15849 er **0603** (`out/openrz67-bom.csv:7`, gruppen C14/C26/C29), ikke 0402. |
| Fiks-feasibilitet | **Trangere enn originalen antar.** Kobber rundt pad 18: F.Cu VCC-stubben fra pad 17 løper (23,058, 11,993)→…→(19,895, 11,049) w 0,2285 og passerer **0,82 mm** fra padden; på B.Cu ligger et 0,635 mm bredt VCC-spor (18,847, 12,293)→(23,727, 12,293) **0,42 mm** unna. GPIO9-sporet på y = 10,320 er altså ikke den nærmeste hindringen. Et 0603 (~2,6 × 0,95 mm landmønster) er tvilsomt her; et 0402 1 µF er tryggere, men blir en **ny** BOM-linje. Kravet om egen GND-via står (brettet har GND-soner på begge lag, men ikke inn i denne lommen). |

### 3.3 U1-03 / FE-3 / PWR-02 — X2, GPIO0 og VSYS-deleren

| Felt | Innhold |
|---|---|
| Verdikt | **«X2 ubrukt»: CONFIRMED · «blokkerer eneste frie ADC1-pinner»: CONFIRMED · foreslått fiks: REFUTED som skrevet** |
| PCB | X2 `XKXGI-SUA-32.768K` CL 12,5 pF (C5213671), `openrz67.kicad_pcb:100` (144,5595, 110,4765) rot 180; pad 1 → `32K_N`, pad 2 → `32K_P`. U1 pad 4 → `32K_P`, pad 5 → `32K_N` = **GPIO0 / GPIO1**. C30/C31 = 18 pF ±1 % mot GND. ADC1-status: GPIO2 (CH2) opptatt av strapping-pullup R8, GPIO3 (CH3) = S2_DRV, GPIO4 (CH4) = S1_DRV, GPIO5 = ADC2 (ikke fabrikkkalibrert, JTAG). GPIO0/1 er de eneste frie ADC1-pinnene. |
| Framework | `framework-arduinoespressif32@3.20014.231204/tools/sdk/esp32c3/sdkconfig:832` `CONFIG_ESP32C3_RTC_CLK_SRC_INT_RC=y`, `:833` EXT_CRYS not set, `:983` `# CONFIG_PM_ENABLE is not set`; samme i den forkompilerte `qout_qspi/include/sdkconfig.h:269-270`. **Også** den nyere pakken på disk (3.20017.241212) har `:846 INT_RC=y` og `:1002 PM_ENABLE` av. `.pio/build/rev1/idedata.json` bekrefter at det er 3.20014 som bygges. Dette **lukker** originalens åpne post «the prebuilt sdkconfig was not inspected on disk». |
| Firmware | Ingen ADC-kode, ingen treff på GPIO0/GPIO1/32768/`esp_sleep`/`analogRead`. `src/main.cpp:294-316` `configurePowerManagement()` ber faktisk om light sleep (`:300 .light_sleep_enable = !ARDUINO_USB_CDC_ON_BOOT`, `:308 esp_pm_configure()`), men kallet er inert fordi `CONFIG_PM_ENABLE` er av. Originalens brødtekst (linje 542) har dette riktig; den komprimerte raden i seksjon 2 («main.cpp har ingen sleep/RTC-kode») er upresis. |
| Datablad | DS tabell 2-6: GPIO0 = ADC1_CH0, GPIO1 = ADC1_CH1. GPIO0/1 er **ikke** strapping (kun GPIO2/8/9) og står ikke i tabell 2-2 «Power-Up Glitches» — premisset i oppgaven holder. Tabell 5-6: ATTEN2 0–1300 mV ±10 mV, ATTEN3 0–2500 mV **±35 mV**. Tabell 5-5: ADC-karakteristikken er målt «with an external 100 nF capacitor» — 100 nF-delen av fiksen er godt underbygd. BQ25185: `VSYS_REG` 4,5 V ±2 % når `VBATREG ≤ 4,3 V` (R13 = 18 k → 4,2 V), SYS_OVP 104–106 %, BUVLO 3,0 V typ med 90/150/210 mV hysterese **ved VIN = 0**. |
| Hvorfor fiksen er feil | (a) **Node.** `U3.1 SYS → VSYS → S3.1`; S3 er *nedstrøms*. 2 MΩ på VSYS trekker 4,2 V / 2 MΩ = **2,1 µA døgnet rundt, også med S3 av** — +35 % på originalens eget ≤ 6 µA av-budsjett i §5 (~4 år → ~3,5 år). Originalen bruker i §5 «No resistor divider across BAT+ or VSYS» som et *pluss* og foreslår i §2 nettopp en slik deler, uten å oppdatere budsjettet. Riktig node er **SW_SYS** (etter S3). (b) **Med USB i er VSYS låst til 4,5 V**, uavhengig av cellen; deleren blir da en «USB tilstede»-flagg, ikke en ladeindikator. (c) **Delingsforholdet.** 1 M/1 M lander SYS_OVP 4,77 V på 2,385 V, altså i ATTEN3 med ±35 mV = **±70 mV referert** (±5,8 % av 3,0–4,2 V-spennet). ATTEN2 er dobbelt så nøyaktig; men merk at 2,2 M/820 k med ±1 % kan gi 1,314 V i OVP-transienten, marginalt utenfor ATTEN2s 1300 mV — velg forholdet med toleranse-marginen regnet inn, eller aksepter ATTEN3. (d) **Begrunnelsen.** `U2.6 (EN)` er hardkoblet til `SW_SYS` og S3 er mekanisk, så en ADC kan ikke i seg selv hindre BUVLO-syklingen. Men den *muliggjør* mitigeringen: `esp_deep_sleep_start()` kutter ~40 mA til titalls µA, og GPIO0/1 ligger i `VDD3P3_RTC`-domenet, altså blant de få deep-sleep-wakeup-pinnene på C3 — nok et argument for å frigjøre dem. Formuler funnet som «varsling + muliggjør deep-sleep-mitigering», ikke «hindrer boot-loop». |
| Korrigert fiks | «Fjern X2/C30/C31 (alle tre — ellers henger 18 pF mot GND på ADC-noden). Legg motstandsdeler fra **SW_SYS** til GND med midtpunkt på GPIO0 og 100 nF fra GPIO0 til GND; velg forhold slik at SYS_OVP 4,77 V med ±1 % motstandstoleranse holder seg innenfor valgt ATTEN. Vent ~5τ etter oppvåkning før første lesning (τ = 50–60 ms). Formål: lavbatterivarsling og deep-sleep-mitigering.» |
| Strøket fra motlesningen | Påstanden om at C30/C31 = 18 pF er feilmatchet mot X2 holder ikke: C_L = 18·18/36 + C_stray = 9 + ~3,5 ≈ **12,5 pF**, altså krystallens CL. 18 pF er lærebokverdien (2×(12,5 − 3) = 19). Ingen parallell til originalens X1-funn (U1-07), som gjelder en reell undermatch. |
| Nyansering | «Arduino tillater ikke EXT_CRYS» er for sterkt. Ingen **prebuilt** Arduino-pakke aktiverer det; en egen ESP-IDF-/lib-builder-bygging kan, og originalen foreslår selv en custom sdkconfig (linje 543). Riktig formulering: X2 er død i alle bygg som bruker de forkompilerte pakkene. Boot-loop-en er dessuten **treg**: gjeninnkobling krever +90–210 mV på cellen med VIN = 0, altså OCV-relaksasjon over minutter — periodisk gjenoppstart, ikke en krasjløkke. |

### 3.4 DELTA-01 — arkiv mot out/

Proveniensen er sterkere enn README hevder: arkivets 13 gerber-/drill-filer skiller seg fra `git show 0e1376e:pcb/kicad/out/gerber/*` bare i to headerlinjer hver (`%TF.CreationDate` 2026-09-07T20:10:15 mot 20:25:08), `openrz67-job.gbrjob` i én linje, og `pcb/archive/2026-09-07-rev2/drc.rpt` er **byte-identisk** med `0e1376e`s. `top.png`, `bottom.png` og `schematic.pdf` er også byte-identiske. `out/openrz67-gerber.zip` er byte-identisk med det sporede `out/gerber/`.

| Endring (2026-09-08) | I arkiv? | Bevis |
|---|---|---|
| C23 flyttet til U2 VIN (`4550987`) | **Mangler** | `0e1376e`: C23 (136,5, 101,4) rot 0, pad 2 (`SW_SYS`) 3,572 mm fra U2 pad 5. HEAD: (135,15, 100,5) rot 180, pad 2 1,120 mm unna. Ny GND-via aux (15,85, 11,2) bare i `out/`. |
| U2/U3 EP-vias (`64ef2b8`+`4550987`) | **Mangler** | `0e1376e`: 0 vias i U2 EP (1,2×2,0) og 0 i U3 EP (0,9×1,5). HEAD: 4 + 2, på de oppgitte koordinatene. Totalt vias 140 → 145. |
| GPIO21 som ett B.Cu-løp | **Mangler** | `0e1376e`: 9 segmenter / 4 vias, F.Cu 18,083 mm + B.Cu 8,742. HEAD: 5 segmenter / 2 vias, 15,417 + 10,851. |
| GND-halsen under U1 åpnet | **Mangler** | B.Cu VCC (141,285, 110,117)→(140,32, 109,1515) erstattet av to segmenter via (141,047, 110,117); VCC-via aux (20,32, 19,151)→(20,33, 19,4); CHIP_EN-via (22,924, 17,94)→(22,924, 17,78). Sone: 15 → 14 fyllpolygoner. |
| Pin-1-prikker U1/U3 (`24bc07f`) | **Mangler** | `0e1376e`: U1 har ingen F.SilkS-sirkel, U3 kun r = 0,03 / w = 0,06. HEAD: fylt r = 0,2 begge, tegnet i `F_Silkscreen.gto` linje 713/721 og 789/797 med D14. |

| Felt | Innhold |
|---|---|
| Verdikt | **CONFIRMED.** Originalen teller fire fikser; det er **fem** endringer (pin-1-prikkene er en egen commit og er nevnt i påstandsteksten, men ikke i seksjon 2-raden). |
| Talltilfeller | F_Cu **2953** reelle diff-linjer (originalen: 2949). B_Cu 1260, F_Silkscreen 249, F_Mask 6, F_Paste 4 stemmer eksakt. PTH.drl **19** uten tidsstempel — originalens 23 er tallet *med*, altså inkonsistent med de øvrige. PTH-hull 158 → 163 (T1: 140 → 145): **10 lagt til, 5 fjernet, 2 flyttet**. `PTH-drl_map.gbr` 146 linjer, ikke nevnt. `erc.rpt` skiller bare i tidsstempelet. |
| Via-tilskrivelse | Originalen lister fem koordinater for GPIO21s «4 vias». To av dem — (18,186, 18,490) og (18,553, 17,320) — er på nett **GND**, ikke GPIO21, og (25,15, 19,00) er utelatt. GPIO21 hadde: (17,65, 16,55), (17,90, 14,25), (18,80, 18,00), (25,15, 19,00). |
| DRC-delta | Arkiv 14 brudd mot 10 i `out/`; differansen er nøyaktig 4 × `starved_thermal` (sone `[GND]` F.Cu prio 498, min spoke 2 / actual 1) ved U2 pad 7 (136,56, 98,9), U2 pad 9 (136,56, 97,9), USB1 pad 1 (125,982, 100,059), USB1 pad 12 (125,982, 106,459). |
| Datodiskrepans i kilden | `README.md` og `pcb/archive/README.md` sier «ordered 2026-09-07»; `pcb/kicad/README.md:268` og commit `24bc07f` sier «the 2026-09-08 order». Merk at pin-1-prikkene ble laget som **svar** på JLCPCBs DFM-spørsmål, altså etter opplasting — de er helt sikkert ikke på brettene. Et evt. git-tag bør merkes med commit-hashen, ikke datoen. |

### 3.5 L-01 — GND-halsen på B.Cu

| Felt | Innhold |
|---|---|
| Verdikt | **CONFIRMED på tredje desimal · begge foreslåtte fikser REFUTED** |
| Geometri | Zone `(net "GND") (layer "B.Cu")` uuid `c357cabf-…`, prio 499, `min_thickness 0.127`: 4 utlinjer / 642,50 mm², hovedøy 561,22. F.Cu-GND: 7 utlinjer / 506,65, hovedøy 413,61. Vertikale snitt hver 0,25 mm: bånd **y 0,3005–0,5615 = 0,2610 mm**, konstant x 25,75 → 32,06, taper 0,350 (x 32,25) / 0,850 (32,75), sammensmelting x ≈ 33,25. Uavhengig erosjonsbisektering (`SHAPE_POLY_SET::Inflate`): østblokken løsner ved r = 0,13050 → hals 0,2610. Ved r = 0,140/side: 363,3 + 115,4 mm² — originalens «115 + 363» reprodusert eksakt. |
| Hva klemmer | Nord: `Edge.Cuts` + `min_copper_edge_clearance` 0,30 → kobber starter y = 0,3005. Sør: B.Cu-spor på **VCC**, w 0,254, **senterlinje y = 0,816** (kant 0,689; + 0,127 sone-clearance = 0,5615). Originalens «VCC-løpet ved y≈0,7» treffer kanten, ikke senterlinja — og det er nettopp derfor fiksforslaget bommer. Ingen B.Cu-via eller pad i båndet; nærmeste er S3 pad 1/2 (Ø1,6, drill 0,9). |
| Fiks 1 REFUTED | S3 pad 1 (VSYS, (27,714, 2,040)) har overkant y = 1,240; VCC-sporets underkant er 0,943 → 0,297 mm ledig, minus 0,127 clearance = **maks 0,170 mm flytt**. Testet: dy = 0,30 gir **to** `shorting_items` (VSYS/VCC og SW_SYS/VCC mot S3 pad 1 og 2) + 2 × `solder_mask_bridge`. dy = 0,17 er lovlig og gir hals **0,4270 mm**, B.Cu-hovedøy 562,55 mm² (ikke 0,431/562,70 — det er summen 0,261 + 0,170, ikke en måling). Reell forbedring, men ikke de 0,56 mm originalen impliserer. |
| Fiks 2 REFUTED | Begge foreslåtte vias lagt inn (0,45/0,25 GND) + refill: halsen er fortsatt **0,2610 mm**, B.Cu-hovedøy fortsatt 561,22, og **samtlige** sonearealer er uendret (506,65 / 642,50 / 151,64 / 161,37). DRC 0 errors / 0 unconnected / samme 10 warnings. Viaene ligger øst for halsen og dupliserer de 12 som allerede binder østblokken. Nullverdi mot dette funnet. (Punktet (33,5, 17,9) ligger dessuten allerede i F.Cu-GND-fyllet, i sekundærøya på 55,81 mm² — «utenfor fyllet, pouren plukker den opp» stemmer ikke.) |
| Er parallellbanen solid? | Ja, men ikke av grunnen erosjonstesten gir. Erosjon på F.Cu er ikke et brukbart mål her (F.Cu-hovedøya splitter allerede ved r = 0,008 pga. tynne utløpere). Slab-målingen er den holdbare: bredeste sammenhengende F.Cu-GND-streng i et vertikalt snitt er **≥ 1,71 mm for hele x 20–40** (ved x = 29: 5,55 mm), altså langt bredere enn B.Cu-halsen. Bruk det tallet, ikke et erosjonstall. |
| Riktig fiks | Vil man ha halsen bort: flytt VCC 0,170 mm sør **og** flytt S3-paddene sørover, eller rut VCC-spinen forbi S3 på F.Cu. Vil man bare ha redundans: de 12 eksisterende viasene + F.Cu-banen er allerede nok — da er dette en DFM-/kantflis-merknad, ikke et elektrisk funn. |
| Nytt | **Ingen DRC-innstilling fanger dette.** `min_connection` = 0,0. Settes den til 0,3 får man 199 `connection_width`-warnings (alle 0,127/0,16-spor og 45 termiske eiker), men **ikke** halsen: KiCad måler bredden på forbindelser *mellom* elementer, ikke innsnevringer *inne i* et sonefyll. Erosjonstesten er eneste detektor — det bør stå i README, ellers dukker samme klasse feil opp igjen. |
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

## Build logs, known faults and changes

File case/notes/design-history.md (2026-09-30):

# Case design history

What was tried, what failed and why the current numbers are what they are. The README
describes the case as it is; this file is the reasoning. All fits are measured in ABS.

## Layout

- **Battery-beside box** (until 2026-09-12): the cell lay next to the PCB. Wider than
  needed. In git history before 2026-09-12.
- **First stacked attempt** (2026-08-31): cell under the PCB, but too tight to work in.
  Scrapped.
- **Stacked layout** (2026-09-12, current): cell flat under the PCB in a rib pocket, PCB on
  posts, open pockets in front of (2 mm) and behind (4 mm) the board for fingers and the
  battery lead. Roomier on purpose. First printed 2026-09-14.
- **Posts** were 11 mm until 2026-09-14, now 8 (cell 6 + foam 1.5 + 0.5 for solder on the
  bare PCB bottom). The BAT1 tails lie beside the cell in X, not over it, which is asserted.
- **Wire-management rule** from the first boxes: exits are open to the seam and at the
  wire's height. Stiff wires take neither threading nor a vertical detour. Printed wire
  clips and guides do not work; use shorter or softer wire and glue.

## Closure

- **Screws** (first cases): threads in plastic stripped; heat-set inserts made assembly slow.
- **Continuous snap bead** on a 2.4 mm wall left 0.45 mm of lip behind the groove, which
  loosened after a few openings.
- **Cantilever fingers** (current). First stacked print 2026-09-14 had a 0.45 bead with 45°
  ramps on both retention faces: closed but held loosely. Now bead 0.55, a 0.4 click-in
  chamfer below and only 0.15 above, so most of the bead is a flat retention face.
- Press-fit walls are still thin and may loosen after repeated disassembly (2026-09-02).
  Revisit with the next case revision.

## Light pipe

- **Stepped counterbore** (first stacked print, 2026-09-14): the lid prints upside-down,
  so the step was a 1 mm ledge over the bed-side opening. The slicer filled it with
  support and the edge came out ragged. Replaced by a 26.6° funnel, under the slicer's 30°
  support threshold.
- **Snap bead inside the collar**: a bead deep enough to click is deeper than a solid pipe
  can squeeze past, and the 0.6 mm collar wall just splayed.
- **Interference bore** (`led_stem_clr` −0.10, ~0.05/side): could not be pressed in by
  hand, reverted 2026-09-20.
- **Slip fit + glue** (current): stem and head both drop in, the 2.6 mm collar keeps it
  straight, one drop of glue holds it. Do not go back to a negative `led_stem_clr`.
- The pipe gap to the LEDs is 0.8 since 2026-09-16.

## Switch

- **SS12F15 slide switch** on M2 screw pillars, until 2026-09-14. The pillar bosses were the
  fit-critical interference; they are gone and the fit is now enforced as keepout geometry
  and asserts, not by looking at a preview.
- **KCD11 snap-in rocker** (current) on the front wall. The lid grew to make room for the
  latch pocket; that, not the PH plugs, now sets the lid height.

## USB-C opening

- **Plug pocket** (14 × 9.5 × 1.2) added 2026-09-14; the user's old Fusion case had one.
- **`usb_shell_poke`** 1.4 (2026-09-19): slides the board toward the USB wall so the shell
  noses into the recess instead of stopping 0.4 short. Plug seats deeper, box 1.4 narrower.

## Lid text

- **Arial "OpenRZ67" / "Trigger"** (until 2026-09-14): uneven weights, wide gap, near the
  edge. DIN Alternate was tried and dropped for Futura Bold.
- **Rail** across the LED row: the off-centre LED (fixed by the PCB) reads as an indicator
  on a line instead of a hole that missed the middle.
- **Empty pockets** at 0.6 mm: the lid prints upside down, so a pocket floor is a bridge.
  It sagged and the letters read fuzzy (2026-09-16). Now an inlay part on filament 2, so
  the letters print first, flat on the bed.
- **Depth** 0.6 (3 layers) until 2026-09-17: body colour ghosted through. 0.8 now; 0.9 is
  the cap from the antenna-recess assert at `lid_top_t` 2.0.
- **Why not slicer colour painting**: stored per mesh triangle, wiped by every re-export.
- **Why not a height-range modifier**: QIDI Studio (≤ v2.x) segfaults on opening a .3mf
  that carries `Metadata/layer_config_ranges.xml`. Per-object settings are safe.
- The inlay never matches a true empty recess (the colour boundary sits in the spreading
  first layer). Soluble support (HIPS under ABS) would allow a real recess: parked.

## Camera plug (removed in dff0c23)

`camera_plug.py` was a printed two-half clamshell around four Dupont sleeves, with press pegs and later
rib-and-groove sides (2026-09-08 to 2026-09-10). Hole tuning: Ø1.5 no-go, Ø1.7 very tight,
pegs sheared. Never got it working; the sleeves are still taped one by one (2026-09-18).
Candidate replacement: a stamped 2.54 mm female header strip cut to 4.

## Other

- D3 (red) moved next to the BQ25185 charger 2026-09-07, so the light-pipe window is
  centred between the two LEDs.
- Antenna: own 40 × 20 antennas were too big for the ceiling band; Ebyte TX2400-FPC-2509
  (25 × 9) chosen 2026-09-16, Molex 146153-0050 as fallback.
- The box is wider than the old Fusion case (59 mm) because of the side-entry U4 and the KCD11
  rocker, both deliberate.

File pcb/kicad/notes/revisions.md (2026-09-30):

# Revision history and port notes

The change-by-change record of the KiCad project: what moved, why, and what was ruled
out. Kept out of the README on purpose; read it when you need the reasoning behind a
part, a route or a rule. What was actually sent to the fab is in `../../archive/`.

## Rev 2 layout changes (2026-09-03)

Outline unchanged from rev 1: **48 × 22 mm**, 2 mm corner radius, mounting holes at
(2, 20) and (46, 2). Edges are named here by their landmark, because the enclosure in
`../../../case/` measures Y from the opposite side: the **USB-C end** is x = 0, the
**camera end** is x = 48, the **S3 edge** is y = 0, and the **switch edge** is y = 22.

- **U4** camera connector: side-entry S4B-XH-A (LCSC C157925) at (44.3, 11.0), opening
  out of the camera end.
- **BAT1** battery connector: vertical through-hole **B2B-PH-K-S(LF)(SN)** (LCSC C131337)
  on the **top** side, restored on 2026-09-05 from the layout before `d7d51ae`.
  Centre (3.275, 4.8105), rotation 90°. Pin 1 = BAT+, pin 2 = GND.
  The original 0.635 mm top-side BAT+ connection and five GND stitching vias are restored;
  the bottom-side BAT+ branch and its transfer via are removed. `BAT+` / `BAT-` labels
  on the bottom identify the through-hole solder pads. All components are now on top.
  The battery cable must reach around the board if the cell remains underneath.
- **Shutter outputs are PhotoMOS, not relays (2026-09-04).** K1/K2 (G6K-2F-Y), their DTC114E
  drivers Q1/Q2, flyback diodes D1/D2 and coil decoupling C27/C28 are gone. Each channel is one
  **TLP172AM** (Toshiba, LCSC C2152276, 4-pin SO6): the ESP32 GPIO drives the LED through a
  **150 Ω** 0402 (R21/R22, UNI-ROYAL 0402WGF1500TCE C25082), about 12.7 mA nominal. At 3.3 V,
  VOH = 0.8 × VDD, VF = 1.4 V and +1% resistance give 8.2 mA at 25 °C, within the datasheet's
  5 to 25 mA recommendation. (220 Ω until 2026-09-07: its 5.6 mA worst case sat exactly on the
  5 mA minimum that the 2 Ω on-resistance is specified at.) The MOSFET output closes S1/S2 to camera ground.
  TLP172AM replaced TLP172GM on 2026-09-05: maximum on-resistance is 2 Ω at 25 °C / IF = 5 mA,
  versus 50 Ω continuous for GM. AM's output rating is 60 V / 500 mA; package and pin functions
  are unchanged. The imported pad numbering 1/2/3/4 maps to Toshiba pins 1/3/4/6.
  Firmware activates S1, waits 10 ms, then activates S2. Camera input limits remain unverified;
  test the assembled prototype before ordering a production batch. See [research notes](rz67-remote-inputs.md)
  and the [Toshiba datasheet](https://toshiba.semicon-storage.com/info/docget.jsp?did=36714&prodName=TLP172AM).
  U5 = S1 (net `S1_DRV`, **GPIO4**, U1 pin 9), U6 = S2 (net `S2_DRV`, GPIO3, U1 pin 8). Rev 1
  drove S1 from GPIO21, which is U0TXD: the ROM boot log leaves it high until `setup()` runs,
  so S1 was closed during every boot. Harmless alone, since the camera needs S1 and S2 together,
  but GPIO4 is a plain input at reset and GPIO21 is now free for serial logging. Isolation is kept: camera ground `AGND` still touches only U4 pin 2 and the two
  output pins, and the AGND pours (both layers) were pulled in from x = 32.1 to x = 34.6 so the
  LED side of each part sits in the GND domain. Eight parts became four, the tallest top-side part
  went from 5.2 mm (relay) to 2.2 mm, and the coil current (about 67 mA while an exposure is
  held) is gone. Footprint `SMD-4_L4.6-W3.7-P2.54-LS7.0-BR` and the 3D model came from
  `easyeda2kicad` for C261926; the unused relay/SOT-346/SOD-523 footprints, models and symbols
  were removed from the project libraries. R4/R5 (USB 22 Ω) are UNI-ROYAL 0402WGF220JTCE
  (C25092, JLCPCB Basic) since JLCPCB had 2 of the Yageo part in stock.
- **C5** moved to the analog supply: the 100 nF that sat on VCC next to the ferrite bead
  L2 now sits on the far side of it, on the new **VDDA** net feeding U1 pins 31/32 (radio and
  ADC supply). Before, nothing decoupled that net; the bead alone was just series impedance.
  VCC reaches L2 pin 1 through a new via 0.55 mm below the pad and a short F.Cu stub. (Until
  2026-09-07 the via sat on the pad's edge with its hole 0.083 mm inside the pad copper — a
  paste-wicking risk DRC cannot see because both are VCC; the pre-fab review caught it.)
  Same part, same position, no BOM change. B.Cu ground under U1 stays connected.
- **Power path: LGS5500 + ME6211 → BQ25185 + TPS63031 (2026-09-07).** Rev 1 charged the
  250 mAh cell at 1 A (R11 = 100 kΩ on the LGS5500's ISET pin, latched at power-up); the
  LGS5500's lowest setting is 400 mA and the cell is rated for **120 mA**, so the charger IC
  was replaced rather than re-programmed. U3 is now a **BQ25185DLHR** (TI, LCSC C19725033,
  WSON-10): linear charger with power path, `IN` = VBUS, `BAT` = BAT+, `SYS` = VSYS.
  R11 2.7 kΩ ±1 % (C25885) on ISET → ICHG = 300 AΩ / 2.7 kΩ = **111 mA** nominal; the datasheet's
  ±10 % accuracy puts the worst case at ~122 mA against the cell's 120 mA rating, accepted
  (3.3 kΩ / 91 mA is the conservative alternative); R13 18 kΩ on ILIM/VSET → 500 mA input limit, 4.20 V regulation, 3.0 V precharge
  threshold (datasheet table 6-1, the value TI's own example uses); R16 (10 kΩ NTC, β 3434 K)
  on TS/MR matches the 10 kΩ / β 3435 K the pin is calibrated for — it still sits on the PCB,
  not in the pack. ~CE is grounded (always enabled), STAT1 is unused, STAT2 drives D3 (red)
  through R18 3 kΩ from VSYS: **lit = charging**, off = done / no USB / fault. SYS feeds the
  power switch S3 and then U2, a **TPS63031DSKR** fixed 3.3 V buck-boost (LCSC C15516,
  VSON-10, 1.8–5.5 V in, up to 500 mA out in boost), which replaces the ME6211 LDO: VCC now
  stays at 3.3 V down to the 3.0 V cutoff instead of sagging with the cell. L3 (2.2 µH,
  SPM6530T) is reused as its inductor (datasheet typical 1.5 µH; peak current ≈ 0.5 A at
  3.0 V in / 0.4 A out); C23 10 µF in, C24 10 µF out, C25 100 nF on VINA, PS/SYNC low =
  power-save, EN tied to VIN. LDO1, R12, R14, R17 and the +5V / +5V_VIN nets are gone.
  Footprints came from LCSC: the VSON-10 matches KiCad's `WSON-10-1EP_2.5x2.5mm_P0.5mm`
  pattern; the WSON-10 (TI `DLH`) has its 0.5 × 0.2 pads centred 0.25 mm further out than
  TI's land pattern (0.8 vs 0.55–1.05 mm), the usual LCSC/JLCPCB style. Check pin 1 of U2 and
  U3 in the assembly preview. Electrical cross-check against the TI datasheets (SLUSF65B,
  SLVS696D) 2026-09-07; not yet built.
- **R20 10 kΩ → 1 kΩ (2026-09-07, UNI-ROYAL 0402WGF1001TCE C11702, Basic).** D4 is an
  XL-1608UBC-04 (blue, 300 mcd at 20 mA, Vf 3.3 V typical at that current). On a 3.3 V rail
  the LED can never get near its rated current, so it runs current-starved: 10 kΩ gave ≈ 80 µA,
  about 1 mcd, which the fabricated rev 1 shows is visible indoors (the inverted firmware kept
  it lit at idle); 1 kΩ gives ≈ 0.3–0.8 mA depending on the part's Vf, 5–10× brighter, a normal
  indicator level, and well inside the GPIO's sink rating. The LED is now only on during
  trigger/bulb/countdown, so the extra current costs nothing at idle. Wiring is unchanged since
  rev 1: VCC → D4 anode, cathode → R20 → GPIO20 (active-low).
- **Resistor sourcing (2026-09-07).** Three lines had 19–40 pieces in JLCPCB stock: the 10 kΩ
  group R6/R7/R8/R20 → UNI-ROYAL 0402WGF1002TCE C25744 (Basic), R12 1 kΩ →
  0603WAF1001T5E C21190 (Basic, ±1 % instead of ±5 %), R18 3 kΩ → FOJAN FRC0402F3001TS
  C2909355. R12 has since gone with the LDO and R20 became 1 kΩ (see above); R6/R7/R8
  and R18 keep these parts. Library symbols are named after the MPN, so the three symbols were renamed and the
  100 kΩ one removed. Re-check stock at JLCPCB right before ordering.
- **C14/C26/C29 1 µF → Samsung CL10A105KB8NNNC C15849 (2026-09-07).** The HRE
  CGA0603X5R105K500JT (C6119852) was down to 8 pieces at JLCPCB. Same spec (1 µF ±10 % 50 V
  X5R 0603) and a Basic part, so no extended-part fee. All three sit on 3.3 V (VCC, CHIP_EN),
  so any ≥ 10 V 1 µF 0603 would do if this one runs out too. Every other BOM line had
  ≥ 500 pieces the same day; U3 (BQ25185, 572) and U2/U1 (~8 k) are the thinnest.
- **U4 pads** are 1.6 mm on the unchanged 1.0 mm drill (rev 1: 1.7 mm) because the S4B-XH-A
  footprint from LCSC draws them so — annular ring 0.30 mm, above JLCPCB's 0.20 mm minimum.
- The S1_DRV via next to U1 pin 9 moved 0.15 mm east (mask dam to the pad was 0.067 mm), and
  `VDDA` joined the `3v` net class (0.20 mm); the seven existing stub segments were drawn at
  0.16 mm and still are.
- **J1 — 1×4 GPIO header, not populated (branch `gpio-header`, 2026-09-07).** Through-hole
  pads along the bottom edge, x = 34.4–42.0 mm, y = 20.6 mm (0.55 mm copper to edge), 2.54 mm
  pitch, for a benchtop header or wires soldered straight into the holes. Pin 1 (square) =
  **3V3**, 2 = **GND**, 3 = **GPIO21** (U0TXD, so it doubles as a UART TX for logging with a
  USB-UART dongle), 4 = **GPIO6**. Silkscreen labels `3V3 GND TX IO6` sit above the pads in
  two staggered rows (1.0 mm text), below the U4 housing so they stay readable with the
  connector fitted; the footprint's own silk outline was removed to make room. The symbol is marked DNP and excluded from the BOM, and the footprint carries
  `exclude_from_bom` / `exclude_from_pos_files`, so J1 stays out of the BOM and the position file
  whichever way they are exported and JLCPCB never sees it; the pads are just copper and holes on the
  bare board. Why only two GPIOs: GPIO21 sits on the QFN's left column and escapes freely,
  but every other free pin (GPIO5/6/7/8/10) is on the right column, where the single gap
  between the VCC, CHIP_EN and S2_DRV tracks fits exactly one more escape — the same limit
  the 2026-09-03 header attempt hit. GPIO6 took it. A third would need the VCC spine on
  B.Cu (x ≈ 31) and the S1/S2 drive diagonals moved. The header sits below the AGND island
  (y > 17.7) in the GND domain, so camera isolation is untouched. Three GND stitching vias that
  collided with the pads were removed, one was added at (32.8, 17.6) to re-connect the F.Cu
  ground strip the tracks cut off (the two new tracks also leave a few via-connected F.Cu
  pieces along the bottom edge), and the tracks were routed with a scratch grid router
  (0.16 mm, DRC-clean at the board's 0.127 mm rule). Cost: GPIO6 has to loop north of U1's
  right column on B.Cu before it can head south, which separates a ~57 mm² piece of the B.Cu
  ground east of U1 (under R21/R22 and LDO1) from the main flood; it stays connected through
  the stitching vias there, and the flood under U1 itself is intact. The case has no opening
  for the header.
- **Under-board clearance** the enclosure has to provide, from the datasheets:

  | What | Height below the board |
  |---|---|
  | BAT1 through-hole tails, B2B-PH-K-S | 3.4 mm unclipped |
  | S3 through-hole tails, B2B-PH-K-S | 3.4 mm unclipped |
  | U4 through-hole tails, S4B-XH-A | 3.4 mm unclipped |
  | USB1 shell posts | ~1 mm |

  The cell can only sit against the board if those tails are **clipped flush**. Budget
  3.4 mm otherwise. A foam pad between cell and board is still wanted, but 1.5 mm of it
  only fits after clipping.

**Removed again:** an earlier attempt widened the board to 25 mm for an unpopulated 1×3
expansion header (GPIO4 / 3V3 / GND) along the switch edge. It was reverted. Reaching the
new edge strip forced the GPIO4 return path across the bottom pour, which split the B.Cu
ground under U1 and LDO1 into two islands and displaced three stitching vias next to the
antenna trace. One GPIO, on a header that was not going to be populated, did not pay for
that. There is no room on this outline for a through-hole header: a hole needs both layers
clear at once, and only two isolated spots on the whole board qualify. Bottom-side solder
pads do fit, but the cell now occupies the bottom. Revisit it together with the enclosure.

- **Routing pass (2026-09-08).** U2's exposed pad has four GND vias (0.45/0.25) and U2's
  pads, like USB1's GND pads 1/12, now connect to the GND pour solid instead of through one
  thermal spoke — the four `starved_thermal` warnings are gone. The B.Cu VCC feed from U2's
  output no longer runs under U2's pad; it goes around the west side of the package. The
  SW1/SW2 pad exits are 0.254 mm (the `5v` class width) instead of 0.16. GPIO21's F.Cu jog
  past U1 pin 1 (LNA_IN) moved 0.75 mm west: 0.79 mm to the RF trace instead of 0.21. Two GND
  stitching vias next to it moved out of the way. The B.Cu ground under U1 still reaches the
  main pour through the same channel between the two GPIO21 vias (main B.Cu island 562 mm²,
  as before).

- **Review fixes (2026-09-08, after the rev-2 order).** A full review against rev 1 found the
  schematic sound and four layout items worth fixing before the next order; all are in
  (coordinates in the board frame, aux origin at the top-left corner):
  - C23 (the only 10 µF on SW_SYS) was 7 mm and two vias away from U2 pin 5 (VIN). It now
    sits at (15.15, 10.5), rot 180: pad 2 is 1.2 mm of 0.254 F.Cu from pin 5, pad 1 has a
    0.4 mm F.Cu strap into U2's exposed pad (PGND) and its own GND via at (15.85, 11.2).
  - The B.Cu ground under U1 hung on a 0.12 mm neck at (20.4, 18.6) — below the zone's own
    0.127 mm minimum, so a refill could have cut it. The VCC via at (20.32, 19.15) moved to
    (20.33, 19.40) and the CHIP_EN via 0.16 mm north to (22.92, 17.78). The erosion test that
    found the neck now gives ≥ 0.32 mm from U1 to every neighbouring pour region; the two
    pre-existing 0.16–0.20 mm necks in the north-west corridor (BAT+ vs the VCC B.Cu run,
    SW_SYS vs the VSYS via) were opened to ≥ 0.26 mm by nudging those runs 0.2–0.25 mm.
  - GPIO21 is one B.Cu run from a single via at (18.0, 14.17) to (25.15, 19.0) instead of
    four vias with two layer changes; the via is 0.25 mm from XTAL_N copper (was 0.16). The
    crossing under the LNA_IN microstrip at (19.3, 18.2) remains — every route from U1's left
    column to J1 has to cross the RF trace's line, so the slot (0.41 mm along the trace) can
    only go away by moving TX off GPIO21 or J1 off the bottom edge. Note: the earlier "0.79 mm
    to the RF trace" measured the F.Cu track; the via was 0.57 mm.
  - U3's exposed pad had no vias and thermal spokes. It has two GND vias 0.45/0.25 at
    (16.65, 3.7) and (17.35, 3.7), placed along x because the 0.4 mm-pitch pad rows leave only
    0.125 mm above/below, and U3 connects solid to the pour like U2.
  DRC after: 0 errors, 0 unconnected, the same 7 courtyard + 1 silk + 2 text warnings.
  Still open from the review, not done here: paste windows on U2/U3 exposed pads (100 % vs
  TI's 84–88 %), the F.Cu ground island under C26/C29/C6 with one via, the 68.7 mm² B.Cu
  island south-east of U1 with one via, a return via next to C24, 0.16 mm power necks at the
  U2/U3 pads, a `+` mark for BAT1 on F.SilkS, the 0.098 mm mask dam on U3.

- **GPIO8 pull-up R23 (2026-09-10).** GPIO8 (U1 pin 14) is a strapping pin with no internal
  pull (ESP32-C3 datasheet table 3-1: default floating) and Joint Download Boot needs it high
  (table 3-3), so the BOOT+EN recovery procedure depended on a floating QFN pad. Rev 1 and the
  ordered rev 2 have it unconnected; the no-connect flag kept ERC quiet about it. R23 is a
  10 kΩ 0402 (same UNI-ROYAL C25744 line as R6/R7/R8) from pin 14 to VCC, at (25.283, 13.669)
  rot 180, pad 2 (GPIO8) 0.16 mm east of pin 14 through a 0.16 mm stub, pad 1 on the VCC copper.
  To make room: C29 moved 0.55 mm east to (26.409, 14.395); the 0.635 mm VCC artery from C29
  pad 2 to R8 now runs down x = 25.709 instead of x = 25.197; the C29→C6 VCC link is one 0.4 mm
  diagonal (25.709, 14.395)→(25.76, 12.867); GPIO6's escape via moved from (24.65, 13.5) to
  (24.62, 14.29) as a 0.4/0.2 via, leaving pad 12 with one 45° stub, and its B.Cu run to
  (26.05, 12.3) starts there. DRC 0 errors, 0 unconnected, schematic parity clean; three new
  courtyard warnings (R23 against U1/C29/C6). The review that found this, and its counter-read,
  are in `review-2026-09-10.md` and `review-2026-09-10-verify.md`.
  **Not done: the 1 µF on VDD_SPI (pin 18)** the hardware design guidelines recommend. Pin 18
  can only leave north, into the 0.7 mm strip between the top pad row and S1's pad (the VCC stub
  to R6 runs there), and an 0402 needs 0.79 mm; moving R6 does not help because both R6 pads
  sit in the same strip. It needs S1 or GPIO9's route moved, or a part on the bottom side.

## Rev 3 (in source since 2026-09-15, not yet fabricated)

Rev 2 as ordered is frozen in [`../../archive/2026-09-07-rev2/`](../../archive/2026-09-07-rev2/). The
source here is rev 3: the review fixes and R23 above, plus:

- **Battery voltage sense (2026-09-15).** Rev 2 cannot read the cell: BQ25185 has no I2C, its
  STAT pins only say charging/not charging, and no ADC1 pin (GPIO0–4) was free — GPIO0/1 carry
  X2, GPIO2 is a strapping pin with R8, GPIO3/4 drive the shutter relays; GPIO5 is ADC2, which
  Espressif does not support on the C3 alongside the radio. Rev 3 frees **GPIO3** by moving the
  S2 relay drive to **GPIO6** (pin 12, MTCK): every other spare pin (GPIO5, GPIO7, GPIO10) is
  boxed in by the VCC artery, the S1_DRV/CHIP_EN/GPIO6 diagonals or the GPIO9 stub, while GPIO6
  already had a route to J1 that passes R22 — the relay is fed from that track at (150.55, 99.3)
  and `J1` lost its 4th pin: a 1×3 header (3V3, GND, TX) with a new `PinHeader_1x03_P2.54mm_Vertical` footprint and `Conn_01x03` symbol, the GPIO6 track to the old pin 4 and the `IO6` silk removed (user 2026-09-15: S1 is not exposed either, the relay output can be probed on `U4`). The divider measures
  **`SW_SYS`** (the switched side of S3), not `BAT+`: BAT+ lives at the far left and every path
  from there to U1 is closed by the VCC trunk, the SW_SYS/VSYS wall and the S1_DRV bridge, while
  SW_SYS is on S3 pad 2 right next to the old S2_DRV copper. On battery SW_SYS is the cell
  voltage; on USB it sits at the higher BQ25185 SYS regulation voltage. That is a hint, not a
  USB-present flag: worst-case tolerances (charger, 1 % divider, ±70 mV ADC) let a full cell and a
  USB-powered SYS rail both land near 4.3 V, and DPPM/supplement mode can drop SYS with USB
  connected. Source impedance is 500 kΩ, so ADC leakage can add tens of mV of DC error on top —
  bench-measure against a multimeter (low/mid/full cell, BLE active, USB in and out) before
  trusting absolute values; 100 kΩ/100 kΩ is the fallback if the error drifts. It draws nothing
  with the switch off. Parts: R24 + R25 1 MΩ 0402
  (UNI-ROYAL 0402WGF1004TCE, C26083, basic) at (149.05, 96.0) and (150.15, 96.0) rot 90 under
  S3, C32 100 nF (same C77020 as C25) at (149.6, 98.0) rot 90; tap 1.5–2.3 V into GPIO3
  (ADC1_CH3) through the old S2_DRV copper (pad-8 stub, via at (143.86, 107.46), B.Cu diagonal
  and the x = 149.007 slot through the S1_DRV bridge), joined at a new via (148.75, 98.2).
  GND vias at (150.4, 94.9) and (148.5, 99.05). DRC 0 errors, 0 unconnected, two new courtyard
  warnings (C32 against R24/R25 — S3's courtyard above and the GPIO6 track below leave no
  slack); ERC unchanged. Title block rev 3.
  **Firmware (done 2026-09-15):** `rev3` / `rev3-debug` envs in `platformio.ini` set `S2_PIN=6` and
  `VBAT_ADC_PIN=3`; the default env stays rev 2. With `VBAT_ADC_PIN` the firmware averages 8
  `analogReadMilliVolts` samples ×2 every 10 s and exposes them as a uint16 mV BLE characteristic
  (read + notify, UUID in the root README). Not done: a low-battery LED warning.
- **Review round 2026-09-25** (`review-2026-09-25.md`), applied in the same source:
  - **Q3 reverse-battery block.** AO3401A P-MOSFET (SOT-23, LCSC C15127, basic) between BAT1
    pin 1 and everything else: drain on the cell (new net `BAT_CELL`), source on `BAT+`
    (C21, U3 BAT), gate on GND. A cell plugged in backwards leaves the FET off and its body
    diode reverse-biased; the right way round the body diode conducts until V<sub>GS</sub> =
    −V<sub>cell</sub> turns the channel on, in both directions (charge and discharge), so the
    charger still sees the cell within ~5 mV (50 mΩ × 111 mA). The block is complete only with
    USB out: with USB in, the charger pulls BAT+ up, V<sub>GS</sub> reaches −4 V and the FET
    turns on whatever the cell's polarity, so a reversed cell looks shorted to the BQ25185,
    which trickles ~7 mA into it until its safety timer expires (about 90 min). Small, but
    unplug USB before fixing a reversed cell. At (126.9, 91.7) rot 180 in
    the top-left corner between BAT1, C20 and L3; VBUS moved to B.Cu under it (via
    (121.397, 92.159), run at y = 91.8 to the existing via at (130.5, 92.986)); BAT+ leaves
    the source east of the gate pad, then west of L3 pad 1 (the pad is 3.4 mm wide) down to
    the C21 via at (126.8, 95.888); gate via at (127.3, 93.4). The footprint is KiCad's
    `SOT-23` copied into `openrz67.pretty/` with KiCad's own STEP for the render (not an LCSC
    model; `fetch_3d.sh` will report C15127 separately). Two courtyard warnings (BAT1, L3).
    Q3's orientation matched the JLCPCB order preview on 2026-09-25 (no `ROT_FIX` needed).
  - **C24 at the buck-boost output.** VOUT is U2 pin 1 (pin 10 is FB, tied to VOUT externally);
    C24 sat 5 mm from it. Now at (134.15, 95.9) rot −90 in the 1 mm notch between L3's body and the VSYS
    corner (whose via moved 0.3 mm east to (135.3, 94.7) to make room): its VCC pad is 0.8 mm
    from pin 1, on the VCC bridge that joins pins
    1 and 10 along y = 96.7, with a return GND via at (134.15, 94.85). L3's and U2's silk outlines
    clip its pads' mask openings by 0.05 mm (four `silk_over_copper` warnings, cosmetic;
    the bodies themselves are 0.15 mm clear) beside its GND pad. The VCC
    transfer via moved from (137.5, 96.7) to (137.2, 97.1). (A first cut of this review put C24
    at (138.0, 97.0) next to pin 10, i.e. FB — caught in PR review.)
  - **Paste windows on the exposed pads.** U1's 3.7 mm EP has no paste on the pad itself and
    four 1.5 × 1.5 mm aperture pads instead (66 % coverage, Espressif's four-window pattern);
    U2 and U3 keep one aperture reduced to 92 % linear (85 % area, TI's 84–88 %). Applied in the
    library footprints and the board copies alike, so `lib_footprint_mismatch` stays quiet.
  - **RF line 0.8 mm** from the U.FL pad through C1/L1/C2 (was 0.5): at the 0.127 mm pour gap
    on 1.6 mm FR-4 that is roughly 52 Ω instead of ~60 Ω (hand calculation, coplanar with
    ground, no solder mask). The 0.3 mm tail into U1 pin 1 is unchanged; it cannot be wider
    between the 0.5 mm pitch pads.
  - **S2_DRV via 0.45/0.25** (was 0.4/0.2, which JLCPCB surcharges: 0.2 or 0.25 mm hole with a
    diameter under 0.45 costs more). It sits in a 0.70 mm slot between U1 pad 13, R23 pad 2 and
    the VCC diagonal, at (144.605, 104.295), 0.13–0.14 mm from each.
  - Bottom silk `v3`, a `+` at BAT1 pin 1 on the top silk, and the schematic note now says
    S2 = GPIO6 / VBAT_SENSE = GPIO3.
  - **Accepted, not changed** (why, in the notes file): no ESD array on USB-C (no room in the
    corner without moving the USB resistors; the bottom side sits 0.5 mm over the cell's foam;
    the C3's own pins are ±2 kV HBM behind 22 Ω, and D± only carry the bench build); BQ25185
    IN/SYS/BAT caps 5–10 mm from the pins (linear charger, no switching loop; the 10 µF are still
    the transient sink); the CHIP_EN RC 11 mm from pin 7 (the strip below the pad row is full);
    the π-match at the U.FL end and untuned (7 mm ≈ λ/10, matching would need a VNA); no test
    points (the bottom faces the cell, the top is full); 0.10 mm via annular ring (0.45/0.25 is
    what the two fabricated revisions used and is JLCPCB's no-surcharge floor).
- Still open from the 2026-09-08 review and 2026-09-10 (see above): one-via ground islands,
  0.16 mm power necks, U3 mask dam, the 1 µF on VDD_SPI.

## Port notes (2026-09-03)

- Import path: EasyEDA Pro **v2** `.epro` → KiCad "Import Non-KiCad Project". The v3
  `.epro2` export loads as an empty board in KiCad 10.0.6.
- Removed the "JeefunPCB" A3 sheet-frame symbol that came with the EasyEDA template
  and replaced it with a KiCad title block. Annotated the 62 power flags (`#PWR001…`),
  deleted two floating GND flags, added a no-connect on U4 pin 1.
- EasyEDA local labels became global labels so net names match the board (`BAT+`, `D7`, and the
  Wemos-style `D1`/`D6`, renamed `S2_DRV`/`S1_DRV` on 2026-09-04); EasyEDA auto-nets (`$1N…`) were renamed to KiCad's `Net-(…)` names.
  Connectivity was verified pad-for-pad against the schematic netlist before renaming.
- USB-C shell pads 13/14 are GND in the schematic; the EasyEDA board had them net-less.
  They are GND now (they sit in the GND pour).
- Schematic footprint fields for L2 (L0603→L0402), U1 (TL→BL QFN variant) and
  R18 (R0603→R0402) were corrected to what is actually on the board.
- DRC: 0 errors, 0 unconnected, schematic parity clean. Remaining warnings are silk
  overlaps/courtyards from the LCSC footprints. Two dangling vias (+5V_VIN, a duplicated
  VCC via) and a 0.1 mm track stub from the original layout were removed.
- **USB1 locating pegs (fixed 2026-09-07).** The connector (C2765186) has two 0.7 mm
  locating pegs besides its four shell legs. The importer turned their NPTH holes into
  two small circles on Edge.Cuts, and the first cleanup pass moved those to F.Fab as
  "stray polygons" — so the rev-2 drill set had **no NPTH holes at all**. JLCPCB caught it
  before assembly ("no drill hole for the indicated pins" on USB1); that order was
  cancelled. The pegs are `np_thru_hole` pads again, in the library footprint and on the
  board, at the rev-1 positions (NPTH drill matches `../../archive/2025-09-23-rev1` exactly).
  They sit 0.171 mm from pads 1/12, as in the LCSC footprint and the fabricated rev 1;
  `openrz67.kicad_dru` accepts 0.17 mm between the pegs and USB1's own pads, and holds the
  pours 0.25 mm off the peg holes like rev 1 (JLCPCB's NPTH-to-copper minimum is 0.2 mm). A
  first version of the rule was unscoped, so the zone filler took 0.15 mm as its target too.
  Side effect: pads 1/12 now get one thermal spoke instead of two (2 DRC warnings).
- Gerber check against the fabricated 2025-09-23 set: copper and mask match apart from
  U4 (now S4B-XH-A side-entry instead of B4B-XH-A) and pour-fill details after KiCad's
  refill (thermal shapes); silkscreen differs in font rendering only. Drill files: PTH
  identical (incl. the four USB1 slots); NPTH identical again after the fix above —
  compare `out/gerber/*.drl` against the archive whenever a footprint changes.
- 3D models: the importer left dangling `EASYEDA_MODELS/…` references. Models were fetched
  per LCSC number with `easyeda2kicad` (`tools/fetch_3d.sh`) and both the board footprints and
  the library `.kicad_mod` files repointed to `openrz67.3dshapes/<name>.wrl`, so "Update
  Footprints from Library" does not undo it. The importer's model offsets were wrong for the
  three connectors (checked 2026-09-07 against the pin geometry inside the `.wrl` files): U4 sat
  3.45 mm off along its axis and 3.4 mm low, BAT1/S3 0.6 mm off and 3.5 mm low, USB1 1.2 mm off
  and 0.9 mm low. They now read U4 `offset 0 6.91 0, rotate 180`, PH `0 1.2 0, 180`, USB1
  `0 0 0, 0`; the pin tails land in their holes in the side renders. U2/U3 got the LCSC models
  (`WSON-10…DLH0010A.wrl` rotate 270, `SON-10…P0.50.wrl` rotate 0, as easyeda2kicad emits them). Board STEP:
  `kicad-cli pcb export step --subst-models -o out/openrz67.step openrz67.kicad_pcb`
  (needs the `.step` files, run `tools/fetch_3d.sh` first).
- Bottom silkscreen label changed from "EPS32-C3 Camera Trigger V1.0 / 2025-08-23" to
  "OpenRZ67 Trigger v2 / 2026-09".
- Pin electrical types were set by hand for the ICs (ESP32-C3, BQ25185, TPS63031, USB-C);
  passives, connectors and the PhotoMOS pins are `passive`. Supply nets without a driver carry `PWR_FLAG`
  (GND, AGND, BAT+, VBUS, SW_SYS, VDDA). ERC runs at default severities: 0 errors; the 15
  warnings are `endpoint_off_grid` from the redrawn charger/buck-boost section, whose
  symbols sit on whole millimetres rather than the 1.27 mm grid (cosmetic, connectivity
  verified by the netlist). The eight dangling wire ends inherited from the EasyEDA drawing were removed
  (an orphan S1/S2/AGND label cluster and three over-long wire tails); the netlist is
  unchanged, verified node-for-node before and after.
- The two mounting holes are real footprints (`MountingHole_2.0mm_Pad3.0`, plated 3.0 mm pad,
  2.0 mm drill) with `MountingHole` symbols H1/H2 in the schematic (excluded from BOM/POS).
- Courtyards were regenerated as pad/body bounding boxes (+0.05 mm) — the LCSC ones were
  oversized. Silkscreen outlines of 0402/0603 parts and of the two overhanging connectors
  (USB-C, U4) live on F.Fab now. DRC: 0 errors, 9 warnings: 5 courtyards where neighbours are
  closer than 0.1 mm on the fabricated layout (C21/USB1, L3 vs C20/R9/R12, H1/USB1), 2 silk-text
  size items from the LCSC footprints, 2 starved thermals on USB1 pads 1/12 (see the pegs note).
- The library symbol file was pruned to the symbols in use; the schematic's embedded copies are
  regenerated from it, so "symbol differs from library" warnings are gone.

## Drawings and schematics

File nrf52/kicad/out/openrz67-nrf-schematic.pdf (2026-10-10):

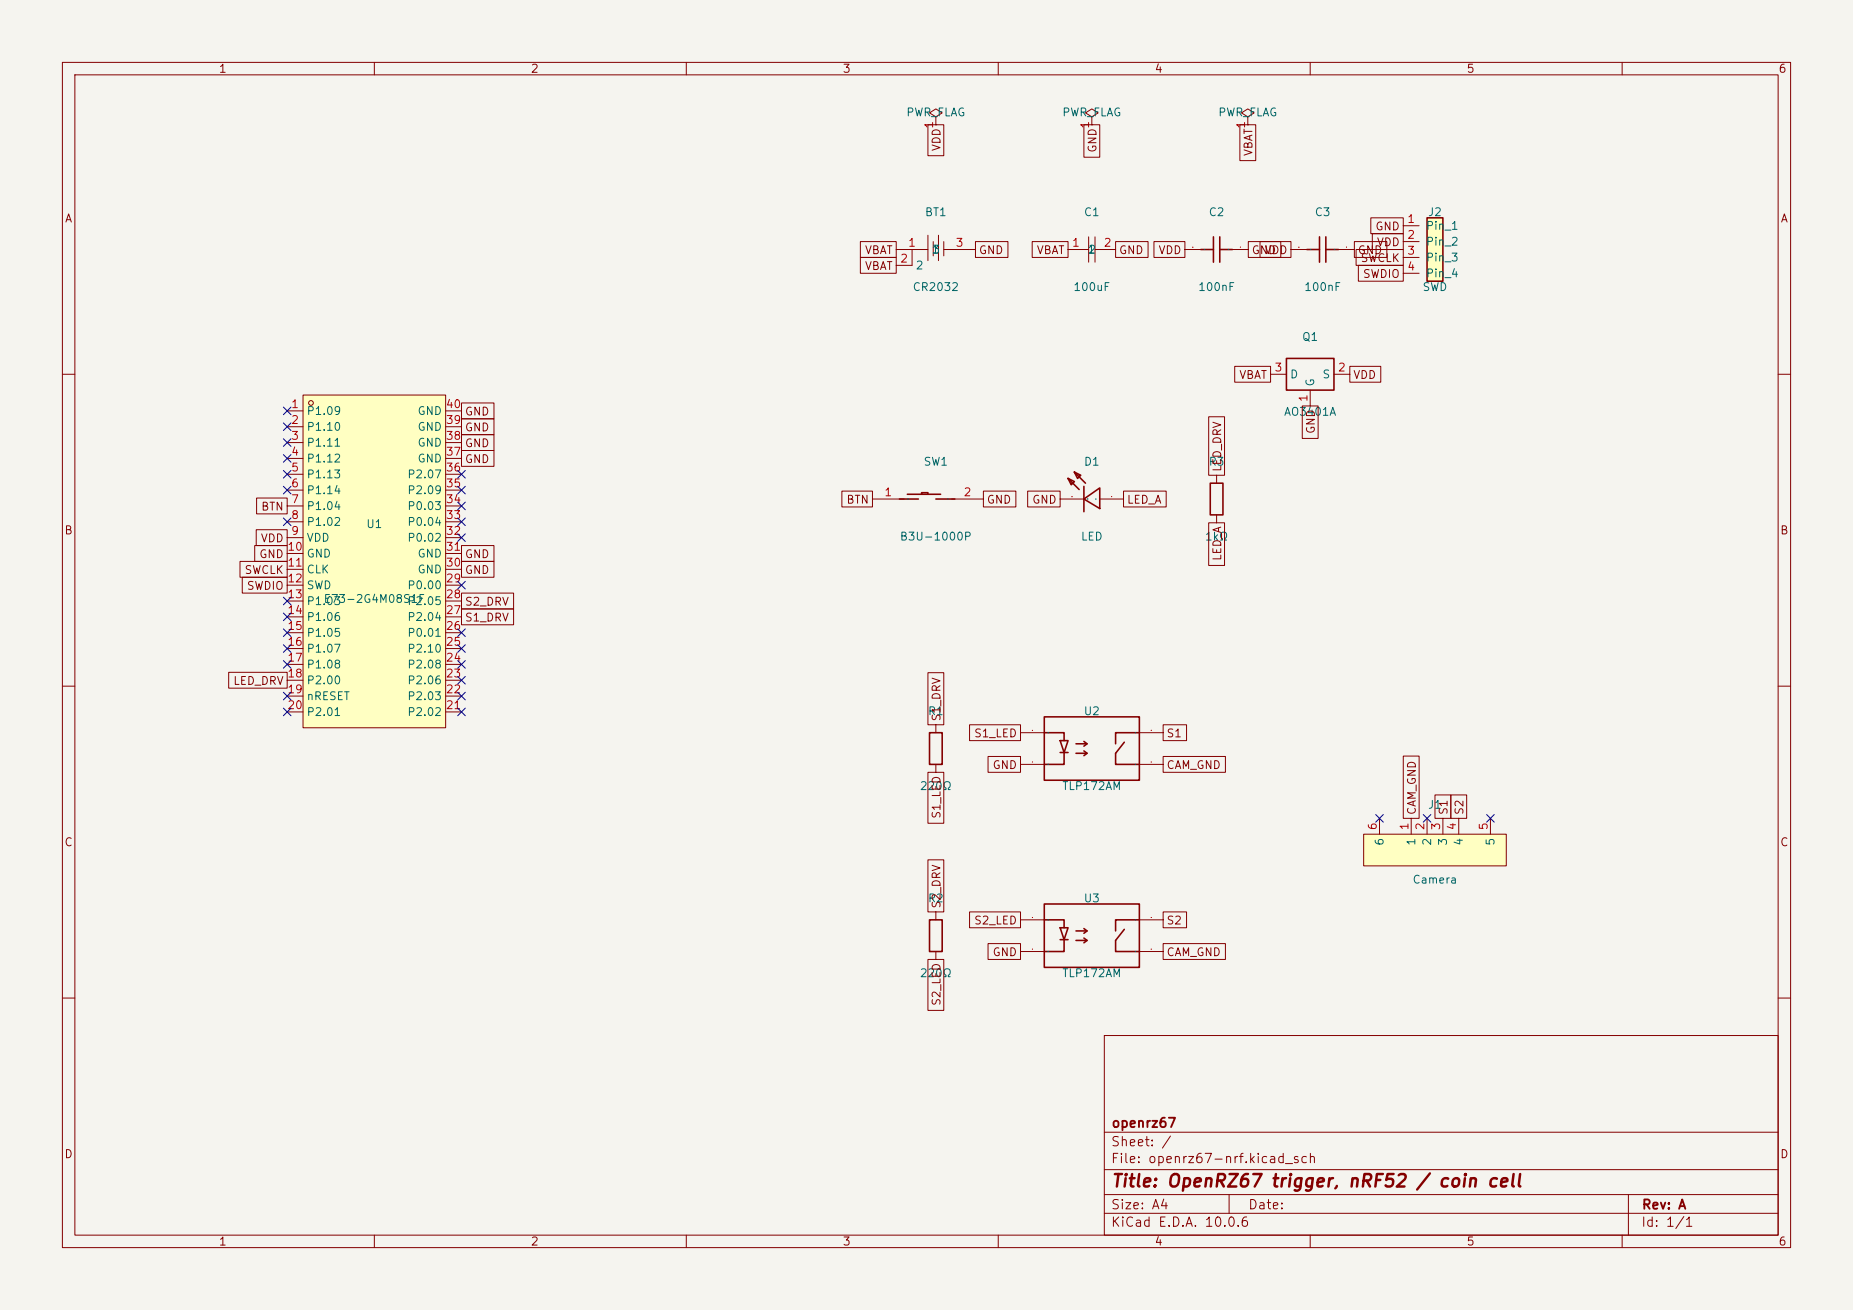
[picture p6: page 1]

Sheet: /
File: openrz67-nrf.kicad_sch
Title: OpenRZ67 trigger, nRF52 / coin cell

Size: A4 | Rev: A
KiCad E.D.A. 10.0.6 | Id: 1/1

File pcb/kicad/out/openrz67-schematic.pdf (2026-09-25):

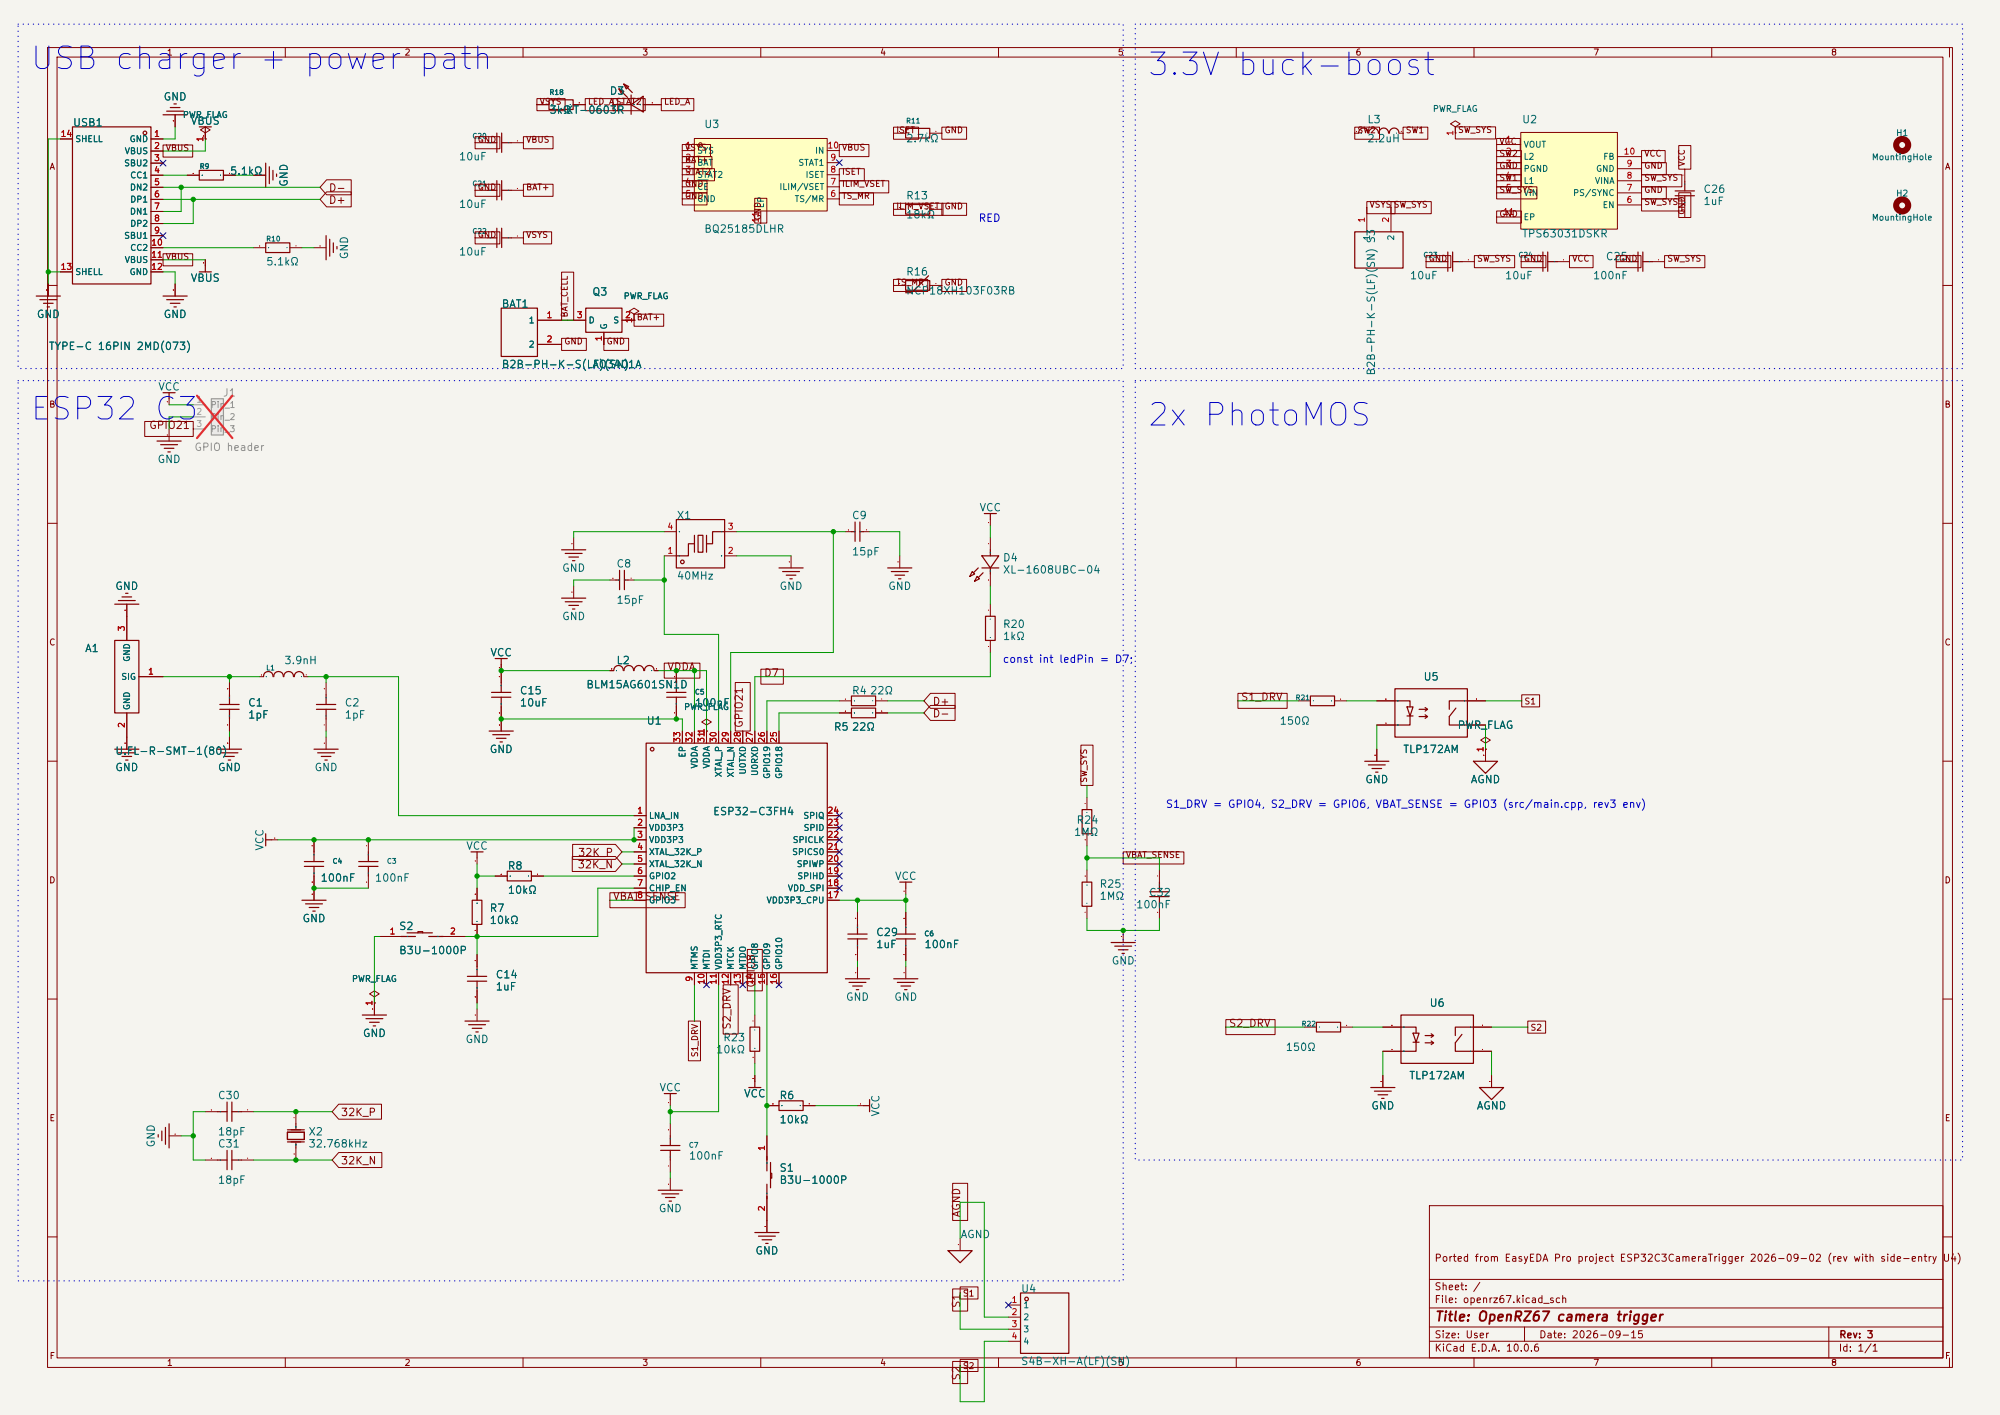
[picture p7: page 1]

USB charger + power path
SW_SYS S2S2

2 PWR_FLAG
VDD3P3_CPU 17 VDD_SPI 18 SPIHD 19 SPIWP 20 SPICS0 21 SPICLK 22 SPID 23 SPIQ 24 GPIO18 25 GPIO19 26 U0RXD 27 U0TXD 28 XTAL_N 29 XTAL_P 30 VDDA 31 VDDA 32 EP 33

S1_DRV = GPIO4, S2_DRV = GPIO6, VBAT_SENSE = GPIO3 (src/main.cpp, rev3 env)

XTAL_32K_P 4

Size: User | Rev: 3 | F Date: 2026-09-15
KiCad E.D.A. 10.0.6 | Id: 1/1

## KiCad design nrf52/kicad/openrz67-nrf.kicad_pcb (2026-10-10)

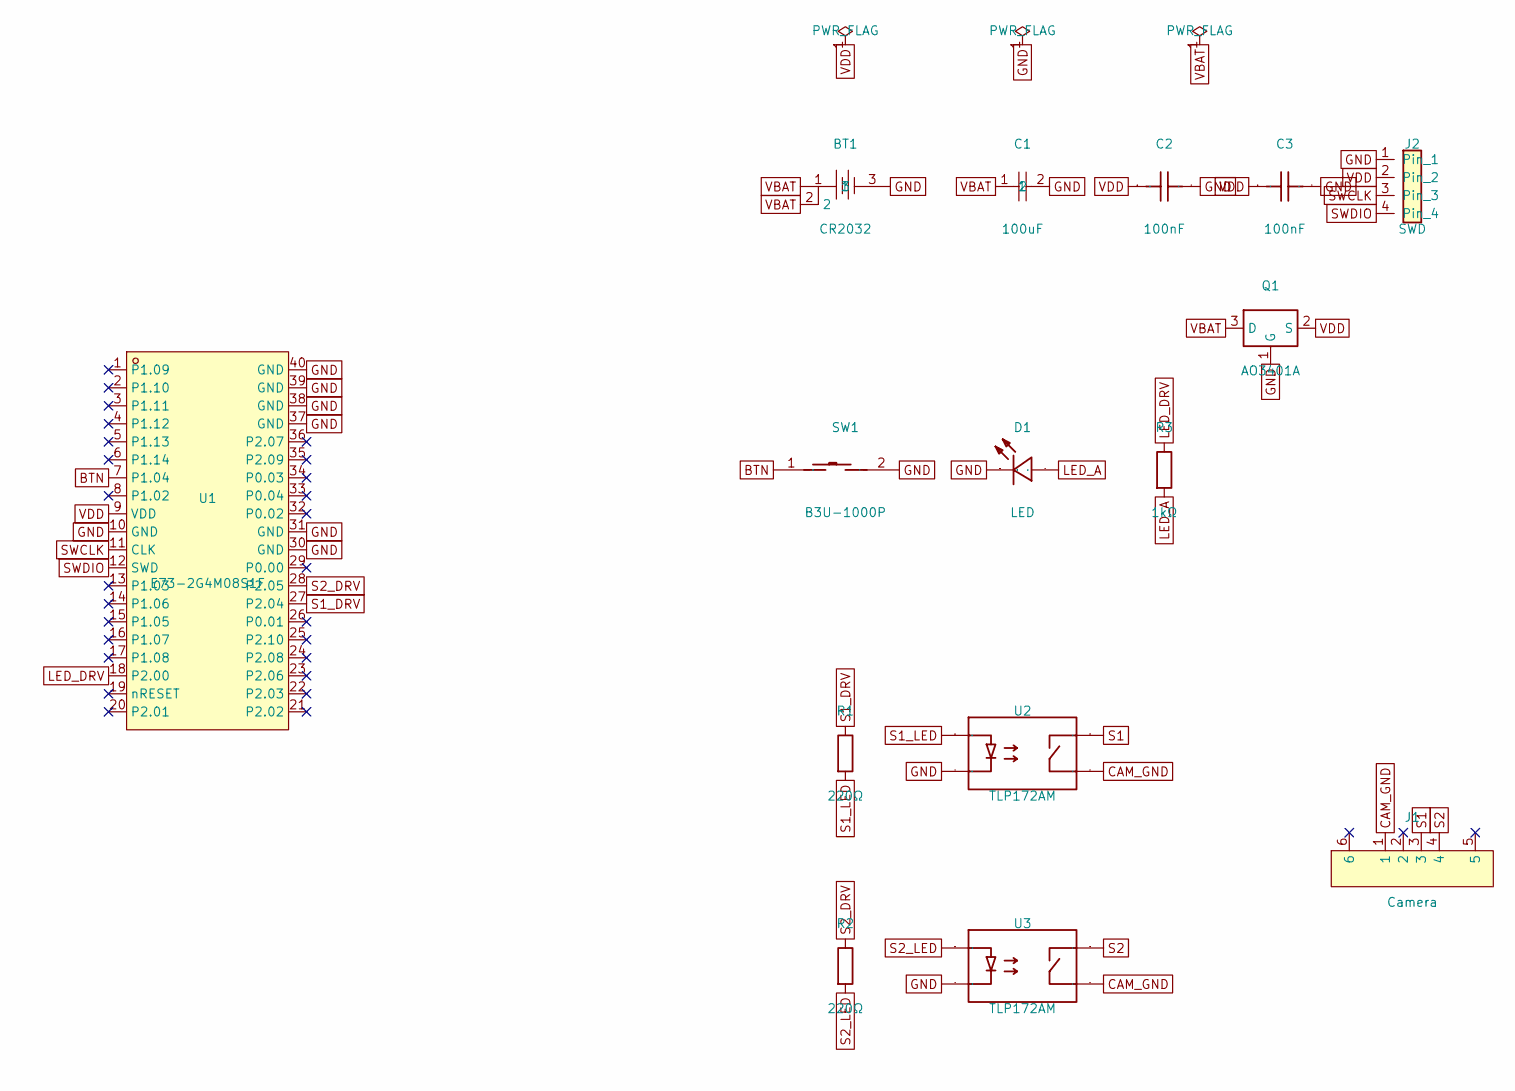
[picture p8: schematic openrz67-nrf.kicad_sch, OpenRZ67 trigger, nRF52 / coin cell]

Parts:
BT1: CR2032; BAT-SMD_MY-2032-16; MPN MY-2032-16; LCSC C2902340
C1: 100uF; C1206; MPN CL31A107MQHNNNE; LCSC C15008
C2, C3: 100nF; C0402; MPN CL05B104KO5NNNC; LCSC C1525
D1: LED; LED0603-RD; MPN KT-0603R; LCSC C2286
J1: Camera; CONN-SMD_4P-P1.00_SM04B-SRSS-TB-LF-SN; MPN SM04B-SRSS-TB(LF)(SN); LCSC C160404
J2: SWD; CONN-SMD_4P-P1.00_SM04B-SRSS-TB-LF-SN; MPN SM04B-SRSS-TB(LF)(SN); LCSC C160404
Q1: AO3401A; SOT-23; MPN AO3401A; LCSC C15127
R1, R2: 220Ω; R0402; MPN 0402WGF2200TCE; LCSC C25091
R3: 1kΩ; R0402; MPN 0402WGF1001TCE; LCSC C11702
SW1: B3U-1000P; KEY-SMD_B3U-1000PM; MPN B3U-1000P; LCSC C231329
U1: E73-2G4M08S1F; WIRELM-SMD_E73-2G4M08S1F; MPN E73-2G4M08S1F; LCSC C54337734
U2, U3: TLP172AM; SMD-4_L4.6-W3.7-P2.54-LS7.0-BR; MPN TLP172AM(TPL,E); LCSC C2152276

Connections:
BTN: SW1.1, U1.7 (P1.04)
CAM_GND: J1.1, U2.3 (D), U3.3 (D)
GND: BT1.3, C1.2, C2.2, C3.2, D1.1 (K), J2.1, Q1.1 (G), SW1.2, U1.10 (GND), U1.30 (GND), U1.31 (GND), U1.37 (GND), U1.38 (GND), U1.39 (GND), U1.40 (GND), U2.2 (K), U3.2 (K)
LED_A: D1.2 (A), R3.2
LED_DRV: R3.1, U1.18 (P2.00)
S1: J1.3, U2.4 (D)
S1_DRV: R1.1, U1.27 (P2.04)
S1_LED: R1.2, U2.1 (A)
S2: J1.4, U3.4 (D)
S2_DRV: R2.1, U1.28 (P2.05)
S2_LED: R2.2, U3.1 (A)
SWCLK: J2.3, U1.11 (CLK)
SWDIO: J2.4, U1.12 (SWD)
VBAT: BT1.1, BT1.2, C1.1, Q1.3 (D)
VDD: C2.1, C3.1, J2.2, Q1.2 (S), U1.9 (VDD)

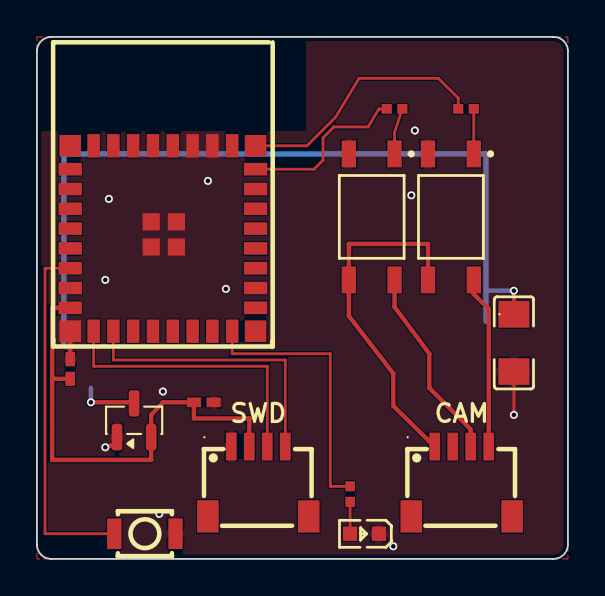
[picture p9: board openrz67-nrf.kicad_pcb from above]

Board: 2 copper layers, 29.5 x 29.0 mm, 15 parts (1 on the bottom side), 15 nets.

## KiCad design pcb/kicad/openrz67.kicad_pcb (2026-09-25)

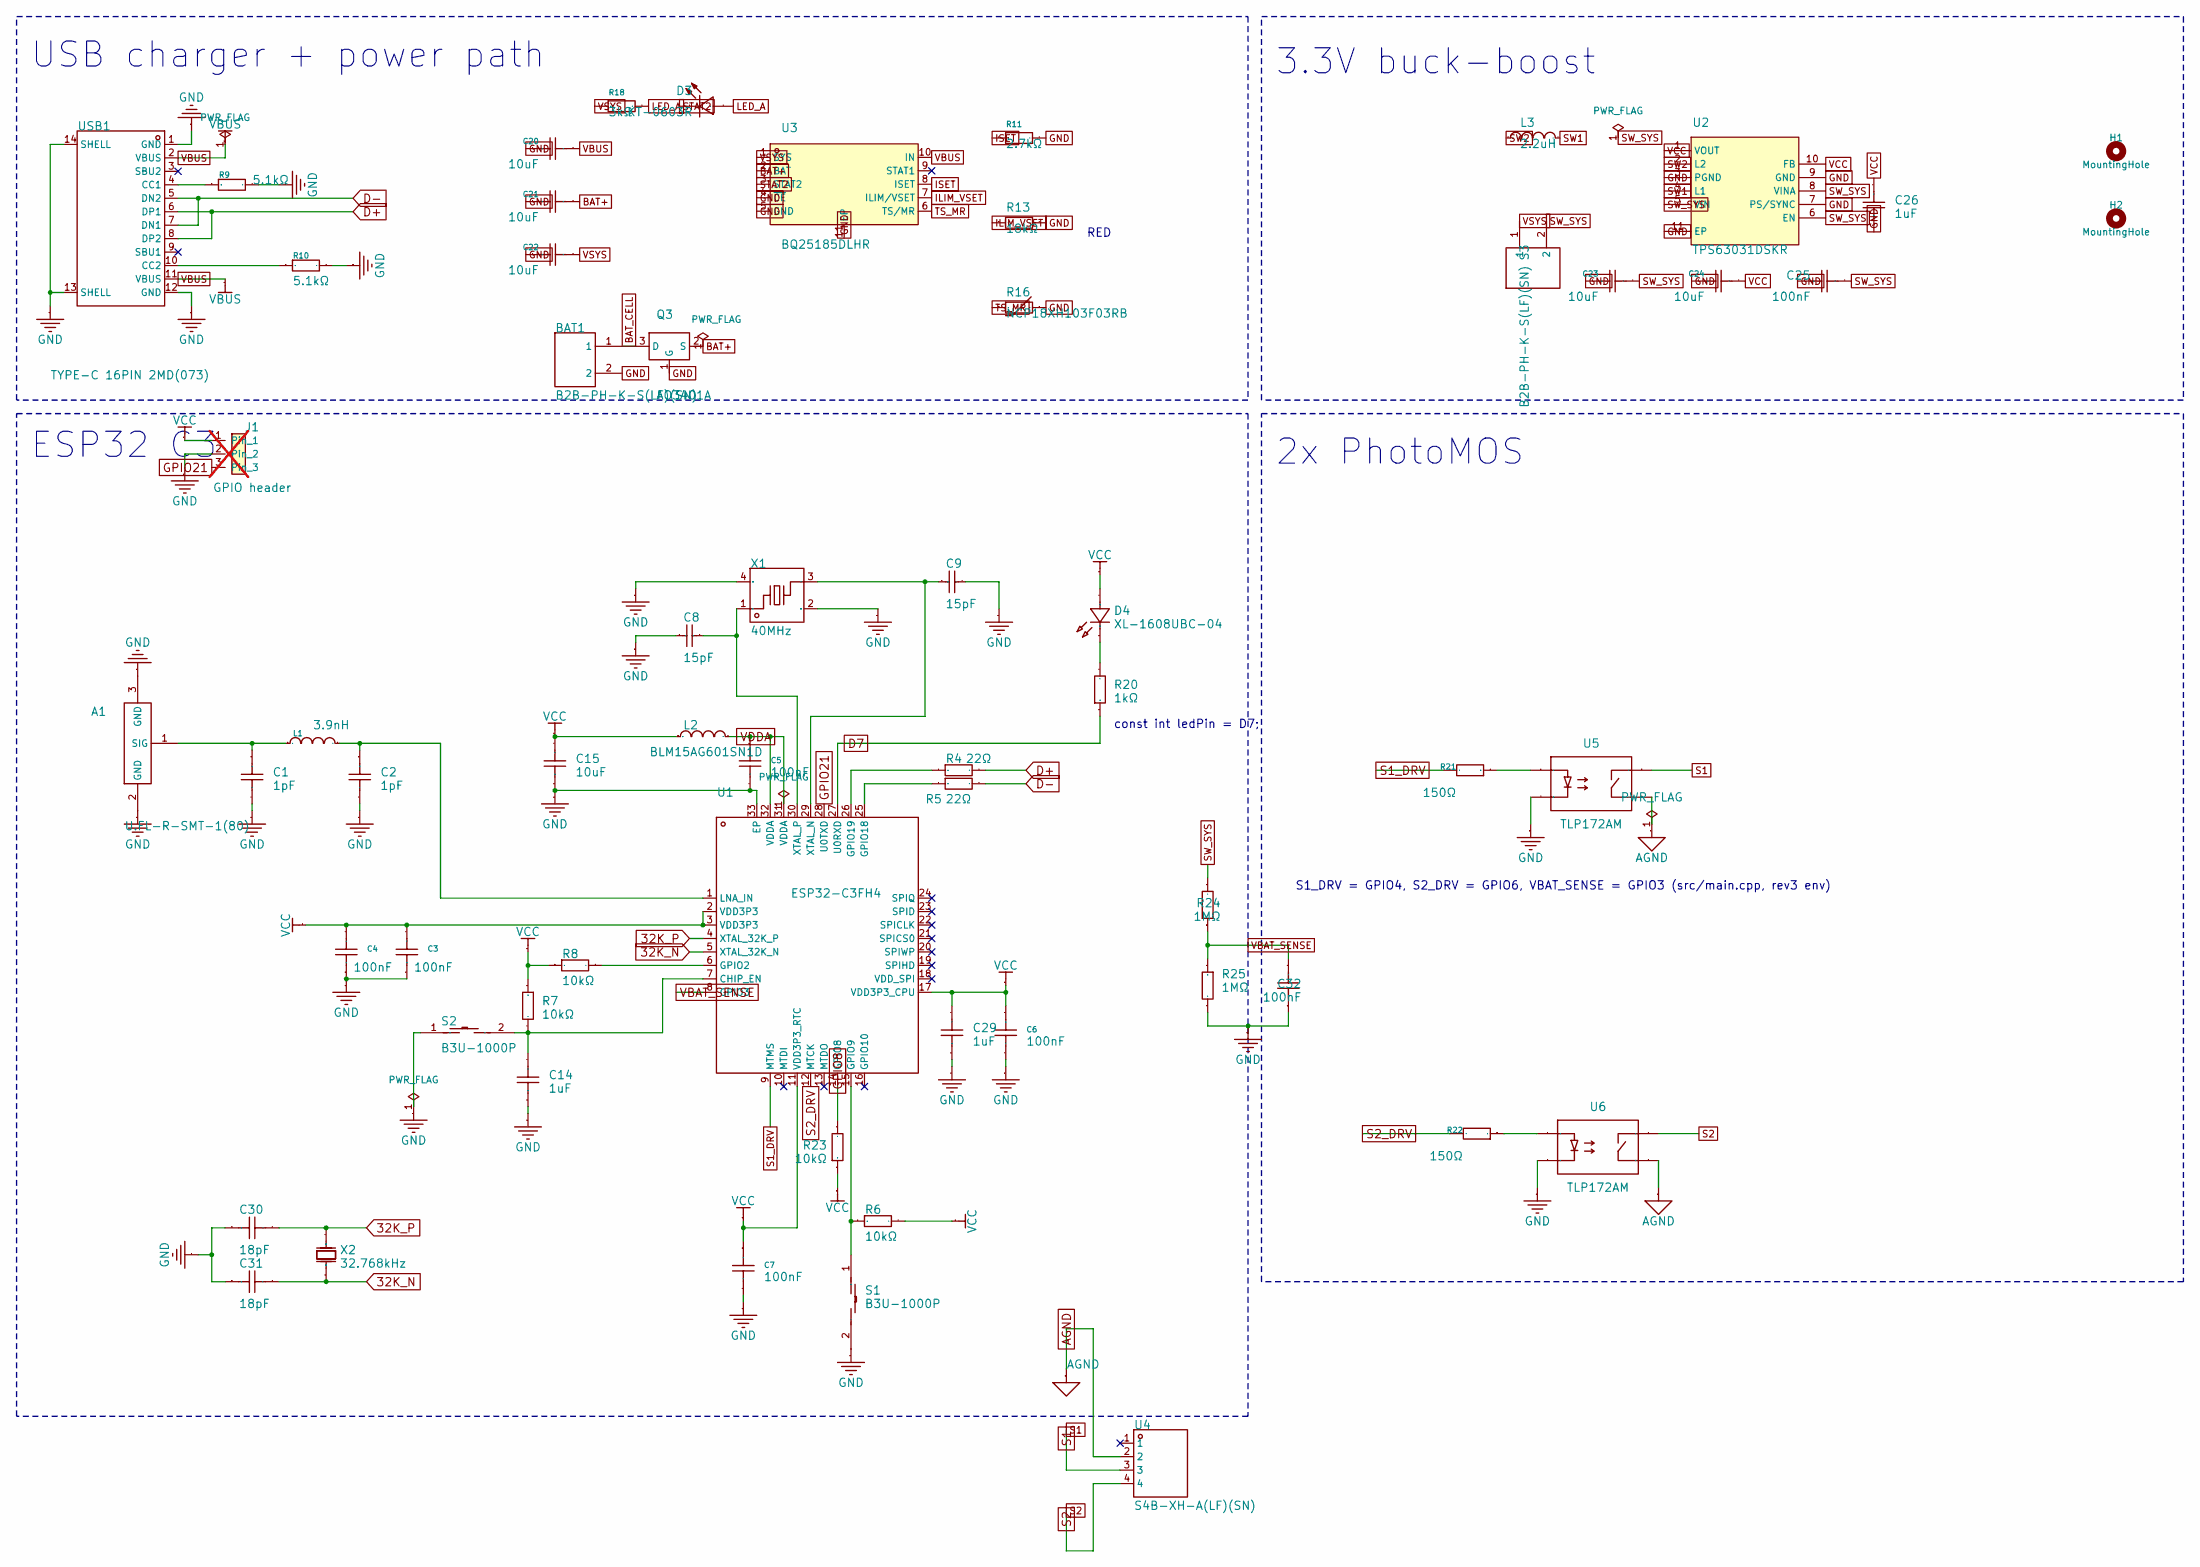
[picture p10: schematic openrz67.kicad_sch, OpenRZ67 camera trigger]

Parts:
A1: U.FL-R-SMT-1(80); RF-SMD_FRF05002-JSS103M; Manufacturer Part U.FL-R-SMT-1(80); LCSC Part Name IPEX 内针
BAT1: B2B-PH-K-S(LF)(SN); CONN-TH_B2B-PH-K-S; Manufacturer Part B2B-PH-K-S(LF)(SN); LCSC Part Name 1x2P 间距:2mm 直插 系列:PH
C1, C2: 1pF; C0402; Manufacturer Part CC0402CRNPO9BN1R0; LCSC Part Name 1pF 50V
C3, C4, C5, C6, C7, C25, C32: 100nF; C0402; Manufacturer Part GRM155R71H104KE14D; LCSC Part Name 100nF ±10% 50V
C8, C9: 15pF; C0402; Manufacturer Part GJM1555C1H150FB01D; LCSC Part Name 15pF ±1% 50V
C14, C26, C29: 1uF; C0603; Manufacturer Part CL10A105KB8NNNC; LCSC Part Name 1uF ±10% 50V
C15, C20, C21, C22, C23, C24: 10uF; C0603; Manufacturer Part CL10A106MA8NRNC; LCSC Part Name 10uF ±20% 25V
C30, C31: 18pF; C0402; Manufacturer Part GRM1555C1H180FA01D; LCSC Part Name 18pF ±1% 50V
D3: KT-0603R; LED0603-RD; Manufacturer Part KT-0603R; LCSC Part Name 0603 红灯 高亮
D4: XL-1608UBC-04; LED0603-RD_BLUE; Manufacturer Part XL-1608UBC-04; LCSC Part Name XL-1608UBC-04
H1, H2: MountingHole; MountingHole_2.0mm_Pad3.0
J1: GPIO header; PinHeader_1x03_P2.54mm_Vertical; not fitted
L1: 3.9nH; L0402; Manufacturer Part LQG15HS3N9S02D; LCSC Part Name 3.9nH
L2: BLM15AG601SN1D; L0402; Manufacturer Part BLM15AG601SN1D; LCSC Part Name 单路 0402磁珠 阻抗600Ω@100MHz
L3: 2.2uH; IND-SMD_L7.1-W6.5-P5.60; Manufacturer Part SPM6530T-2R2M; LCSC Part Name 2.2uH ±20% 8.4A
Q3: AO3401A; SOT-23; Manufacturer Part AO3401A
R4, R5: 22Ω; R0402; Manufacturer Part 0402WGF220JTCE; LCSC Part Name 22Ω ±1% 62.5mW 厚膜电阻
R6, R7, R8, R23: 10kΩ; R0402; Manufacturer Part 0402WGF1002TCE; LCSC Part Name 10kΩ ±1% 62.5mW 厚膜电阻
R9, R10: 5.1kΩ; R0402; Manufacturer Part 0402WGF5101TCE; LCSC Part Name 5.1kΩ ±1% 62.5mW 厚膜电阻
R11: 2.7kΩ; R0402; Manufacturer Part 0402WGF2701TCE; LCSC Part Name 2.7kΩ ±1% 62.5mW
R13: 18kΩ; R0402; Manufacturer Part 0402WGF1802TCE; LCSC Part Name 18kΩ ±1% 62.5mW
R16: NCP18XH103F03RB; R0603; Manufacturer Part NCP18XH103F03RB; LCSC Part Name NCP18XH103F03RB
R18: 3kΩ; R0402; Manufacturer Part FRC0402F3001TS; LCSC Part Name 3kΩ ±1% 62.5mW 厚膜电阻
R20: 1kΩ; R0402; Manufacturer Part 0402WGF1001TCE; LCSC Part Name 1kΩ ±1% 62.5mW
R21, R22: 150Ω; R0402; Manufacturer Part 0402WGF1500TCE; LCSC Part Name 150Ω ±1% 62.5mW 厚膜电阻
R24, R25: 1MΩ; R0402; Manufacturer Part 0402WGF1004TCE; LCSC Part Name 1MΩ ±1% 62.5mW 厚膜电阻
S1, S2: B3U-1000P; KEY-SMD_B3U-1000PM; Manufacturer Part B3U-1000P; LCSC Part Name 3*2.5*1.6mm 立贴 轻触开关
S3: B2B-PH-K-S(LF)(SN); CONN-TH_B2B-PH-K-S; Manufacturer Part B2B-PH-K-S(LF)(SN); LCSC Part Name 1x2P 间距:2mm 直插 系列:PH
U1: ESP32-C3FH4; QFN-32_L5.0-W5.0-P0.50-BL-EP3.7; Manufacturer Part ESP32-C3FH4; LCSC Part Name ESP32-C3FH4
U2: TPS63031DSKR; VSON-10_L2.5-W2.5-P0.50-EP1.2x2.0; Manufacturer Part TPS63031DSKR; LCSC Part Name TPS63031DSKR
U3: BQ25185DLHR; WSON-10_L2.2-W2.0-P0.40-EP0.9x1.5; Manufacturer Part BQ25185DLHR; LCSC Part Name BQ25185DLHR
U4: S4B-XH-A(LF)(SN); CONN-TH_S4B-XH-A-LF-SN; Current Rating 3A; Voltage Rating 250V; Manufacturer Part S4B-XH-A(LF)(SN); LCSC Part Name 1x4P 间距:2.5mm 弯插 系列:XH
U5, U6: TLP172AM; SMD-4_L4.6-W3.7-P2.54-LS7.0-BR; Manufacturer Part TLP172AM(TPL,E); LCSC Part Name TLP172AM(TPL,E)
USB1: TYPE-C 16PIN 2MD(073); USB-C-SMD_TYPE-C-6PIN-2MD-073; Manufacturer Part TYPE-C 16PIN 2MD(073); LCSC Part Name Type-C 母 卧贴
X1: 40MHz; CRYSTAL-SMD_4P-L2.0-W1.6-BL-2; Manufacturer Part T201640MFBDE2X; LCSC Part Name 40MHz ±10ppm 12pF
X2: 32.768kHz; CRYSTAL-SMD_L3.2-W1.5-1; Manufacturer Part XKXGI-SUA-32.768K; LCSC Part Name YST310S 32.768KHZ 2P 3215 12.5PF ±20PPM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

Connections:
32K_N: C31.2, U1.5 (XTAL_32K_N), X2.1 (OSC1)
32K_P: C30.2, U1.4 (XTAL_32K_P), X2.2 (OSC2)
AGND: U4.2, U5.3 (D), U6.3 (D)
BAT+: C21.2, Q3.2 (S), U3.2 (BAT)
BAT_CELL: BAT1.1, Q3.3 (D)
D7: R20.1, U1.27 (U0RXD)
D+: R4.2, USB1.6 (DP1), USB1.8 (DP2)
D-: R5.2, USB1.5 (DN2), USB1.7 (DN1)
GND: A1.2 (GND), A1.3 (GND), BAT1.2, C1.2, C2.2, C3.1, C4.1, C5.2, C6.2, C7.2, C8.1, C9.2, C14.1, C15.1, C20.1, C21.1, C22.1, C23.1, C24.1, C25.1, C26.1, C29.1, C30.1, C31.1, C32.1, J1.2, Q3.1 (G), R9.2, R10.2, R11.2, R13.2, R16.2, R25.2, S1.2, S2.1, U1.33 (EP), U2.3 (PGND), U2.7 (PS/SYNC), U2.9 (GND), U2.11 (EP), U3.4 (~CE), U3.5 (GND), U3.11 (EP), U5.2 (K), U6.2 (K), USB1.1 (GND), USB1.12 (GND), USB1.13 (SHELL), USB1.14 (SHELL), X1.2 (GND), X1.4 (GND)
GPIO8: R23.2, U1.14 (GPIO8)
GPIO21: J1.3, U1.28 (U0TXD)
ILIM_VSET: R13.1, U3.7 (ILIM/VSET)
ISET: R11.1, U3.8 (ISET)
LED_A: D3.2 (A), R18.2
unnamed: A1.1 (SIG), C1.1, L1.1
unnamed: D4.1 (K), R20.2
unnamed: C14.2, R7.2, S2.2, U1.7 (CHIP_EN)
unnamed: R8.2, U1.6 (GPIO2)
unnamed: R6.1, S1.1, U1.15 (GPIO9)
unnamed: R5.1, U1.25 (GPIO18)
unnamed: R4.1, U1.26 (GPIO19)
unnamed: C2.1, L1.2, U1.1 (LNA_IN)
unnamed: C9.1, U1.29 (XTAL_N), X1.3
unnamed: C8.2, U1.30 (XTAL_P), X1.1
unnamed: R21.1, U5.1 (A)
unnamed: R22.1, U6.1 (A)
unnamed: R9.1, USB1.4 (CC1)
unnamed: R10.1, USB1.10 (CC2)
S1: U4.3, U5.4 (D)
S1_DRV: R21.2, U1.9 (MTMS)
S2: U4.4, U6.4 (D)
S2_DRV: R22.2, U1.12 (MTCK)
STAT2: D3.1 (K), U3.3 (STAT2)
SW1: L3.2, U2.4 (L1)
SW2: L3.1, U2.2 (L2)
SW_SYS: C23.2, C25.2, R24.2, S3.2, U2.5 (VIN), U2.6 (EN), U2.8 (VINA)
TS_MR: R16.1, U3.6 (TS/MR)
VBAT_SENSE: C32.2, R24.1, R25.1, U1.8 (GPIO3)
VBUS: C20.2, U3.10 (IN), USB1.2 (VBUS), USB1.11 (VBUS)
VCC: C3.2, C4.2, C6.1, C7.1, C15.2, C24.2, C26.2, C29.2, D4.2 (A), J1.1, L2.1, R6.2, R7.1, R8.1, R23.1, U1.2 (VDD3P3), U1.3 (VDD3P3), U1.11 (VDD3P3_RTC), U1.17 (VDD3P3_CPU), U2.1 (VOUT), U2.10 (FB)
VDDA: C5.1, L2.2, U1.31 (VDDA), U1.32 (VDDA)
VSYS: C22.2, R18.1, S3.1, U3.1 (SYS)

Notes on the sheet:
RED
const int ledPin = D7;
USB charger + power path
3.3V buck-boost
2x PhotoMOS
ESP32 C3
S1_DRV = GPIO4, S2_DRV = GPIO6, VBAT_SENSE = GPIO3 (src/main.cpp, rev3 env)

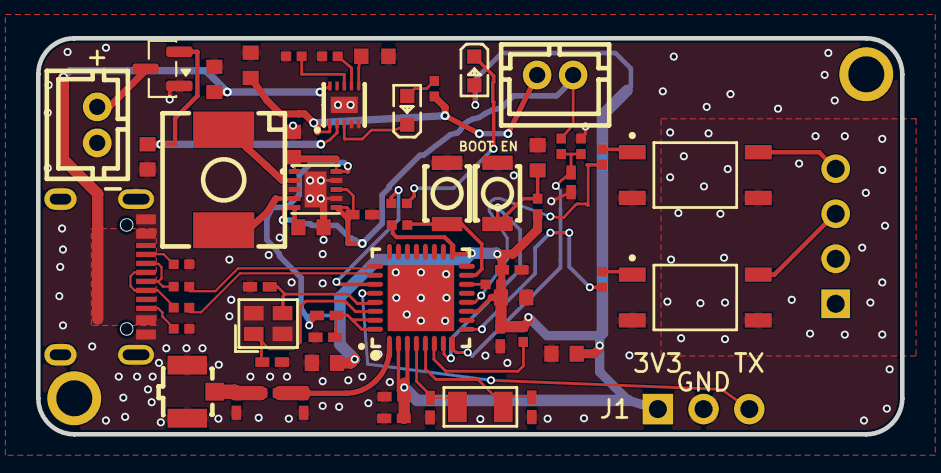
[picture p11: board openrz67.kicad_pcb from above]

Board: 2 copper layers, 48.0 x 22.0 mm, 62 parts (0 on the bottom side), 42 nets.

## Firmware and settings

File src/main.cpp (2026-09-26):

#include <Arduino.h>
#include <BLEDevice.h>
#include <BLEServer.h>
#include <esp_pm.h>
#include <driver/ledc.h>
#include <soc/rtc.h>

#define SERVICE_UUID        "c9239c9e-6fc9-4168-b3aa-53105eb990b0"
#define CHARACTERISTIC_UUID "458d4dc9-349f-401d-b092-a2b1c55f5319"
// Rev 3: SW_SYS (battery on battery power, BQ25185 SYS voltage on USB) in mV, uint16 LE, read + notify.
#define BATTERY_UUID        "cda71ce6-4af9-4aa2-8d34-329c2acdae09"
#define VBAT_PERIOD 10000
// Battery Level (0x2A19) percent from the cell voltage, linear between these two points.
#define VBAT_EMPTY_MV 3500
#define VBAT_FULL_MV  4200

#ifndef FW_VERSION
#define FW_VERSION "dev"
#endif

#define DELAY 2000
#define COUNTDOWN_DURATION 10000  // 10 seconds in milliseconds
// Idle status LED: dim steady while a phone is connected, a slow soft pulse while
// advertising. PWM via LEDC so the pulse can dim.
#define PULSE_PERIOD 4000
#define PULSE_MAX 120   // of 255; the LED is current-starved already, keep it soft
#define CONNECTED_LEVEL 25  // dim steady when connected, so trigger/bulb (255) still show

// Radio timing, the main battery-life lever with light sleep on. Advertising interval
// in 0.625 ms units: kept fast, since a slower one (100-200 ms was tried) makes the phone
// take seconds longer to find the device; connection interval in 1.25 ms units with a
// slave latency, so the chip may skip that many connection events when idle. A
// command from the phone is seen at the next event the chip listens to, so the worst
// added trigger delay is (CONN_LATENCY + 1) * CONN_MAX_INTERVAL * 1.25 ms. Latency
// is 0 until a bench measurement shows what skipping events saves against that delay.
#define ADV_MIN_INTERVAL 0x0030  // 30 ms
#define ADV_MAX_INTERVAL 0x0060  // 60 ms
#define CONN_MIN_INTERVAL 0x18   // 30 ms
#define CONN_MAX_INTERVAL 0x28   // 50 ms
#define CONN_LATENCY 0
#define CONN_TIMEOUT 400         // 4 s, in 10 ms units

// VERBOSE comes from platformio.ini: 0 in the production env (every Serial call
// compiles to a no-op), 1 in the debug env, where Serial is USB CDC.
#ifndef VERBOSE
#define VERBOSE 0
#endif
#if !VERBOSE
  struct NullStream {
      template<typename T> NullStream& operator<<(T const&) { return *this; }
      void print(...) {}
      void println(...) {}
      void setTxTimeoutMs(...) {}
      void begin(...) {}
  };
static NullStream nullSerial;
#undef Serial // the core defines it as a macro when CDC is off
#define Serial nullSerial
#endif

constexpr int ledPin = 20; // GPIO20 (U0RXD)
uint8_t ledLevel = 0; // 0 = off, 255 = full

// LEDC straight from ESP-IDF, since Arduino's ledcAttach() cannot ask for KEEP_ALIVE and
// the PWM would stop whenever the chip light-sleeps. RC_FAST is the only LEDC clock on the
// C3 that runs through light sleep (APB stops).
void setupLed() {
    ledc_timer_config_t timer = {
        .speed_mode = LEDC_LOW_SPEED_MODE,
        .duty_resolution = LEDC_TIMER_8_BIT,
        .timer_num = LEDC_TIMER_0,
        .freq_hz = 5000,
        .clk_cfg = LEDC_USE_RC_FAST_CLK,
    };
    ESP_ERROR_CHECK(ledc_timer_config(&timer));
    ledc_channel_config_t channel = {
        .gpio_num = ledPin,
        .speed_mode = LEDC_LOW_SPEED_MODE,
        .channel = LEDC_CHANNEL_0,
        .timer_sel = LEDC_TIMER_0,
        .duty = 0,
        .sleep_mode = LEDC_SLEEP_MODE_KEEP_ALIVE,
        // D4's anode is on VCC and its cathode reaches GPIO20 through R20, so the LED is
        // active-low. Clear this if a board is wired the other way round.
        .flags = {.output_invert = 1},
    };
    ESP_ERROR_CHECK(ledc_channel_config(&channel));
}

void ledWrite(uint8_t level) {
    ledLevel = level;
    ledc_set_duty(LEDC_LOW_SPEED_MODE, LEDC_CHANNEL_0, level);
    ledc_update_duty(LEDC_LOW_SPEED_MODE, LEDC_CHANNEL_0);
}
// S2_PIN comes from platformio.ini: GPIO3 on rev 1/2 (default), GPIO6 in the rev3 envs.
#ifndef S2_PIN
#define S2_PIN 3
#endif
constexpr int shutterPinS2 = S2_PIN; // drives U6 (camera S2)
// S1_PIN comes from platformio.ini: GPIO4 on rev 2 (default), GPIO21 (U0TXD) in the rev1 env.
#ifndef S1_PIN
#define S1_PIN 4
#endif
constexpr int shutterPinS1 = S1_PIN; // drives U5 (camera S1)

// Commands arrive on the BLE task (onWrite) and are executed in loop(), so the BLE
// stack is never blocked by the shutter delays. The queue is the only shared state
// between the two tasks besides the connection flags below.
struct Command {
    uint8_t button;   // 1 trigger, 2 bulb, 3 countdown
    uint8_t value;    // 1 press/start, 0 release/cancel
    uint32_t durationMs;
};
QueueHandle_t commandQueue;

int incoming;
unsigned long timestampButton;
unsigned long countdownStartTime;
unsigned long countdownDuration = COUNTDOWN_DURATION;
bool countdownActive = false;
bool bulbModeActive = false;
unsigned long lastCountdownPrint = 0;

BLEServer *pServer = nullptr;
volatile bool deviceConnected = false;
volatile bool advertiseRequested = false;

// Tickless idle forces PM_SLP_DISABLE_GPIO on, which releases every pin in light sleep.
// A released S1/S2 pin reads as off through R21/R22, fine while closed but it would end
// a bulb exposure, so the chip stays out of light sleep while the shutter is open.
esp_pm_lock_handle_t shutterAwake;
bool shutterOpen = false;

void openShutter() {
    if (!shutterOpen) esp_pm_lock_acquire(shutterAwake);
    shutterOpen = true;
    Serial.println("Setting shutterPins HIGH...");
    digitalWrite(shutterPinS1, HIGH);
    delay(10); // Allow S1's PhotoMOS to turn on before requesting release.
    digitalWrite(shutterPinS2, HIGH);
}

void closeShutter() {
    Serial.println("Setting shutterPins LOW...");
    digitalWrite(shutterPinS2, LOW);
    digitalWrite(shutterPinS1, LOW);
    if (shutterOpen) esp_pm_lock_release(shutterAwake);
    shutterOpen = false;
}

void endBulbMode() {
    Serial.println("Ending bulb mode - shutter closing");
    bulbModeActive = false;
    closeShutter();
}

void triggerShutter() {
    Serial.println("Trigger shutter");
    endBulbMode();
    openShutter();
    delay(100);
    closeShutter();
}

void startBulbMode() {
    Serial.println("Starting bulb mode - shutter opening");
    bulbModeActive = true;
    openShutter();
}

void startCountdown(unsigned long durationMs) {
    endBulbMode();
    // Clear stale button-1 state so the trigger timeout in loop()
    // doesn't fight the countdown blink over the LED pin
    incoming = 0;
    countdownDuration = durationMs;
    countdownStartTime = millis();
    lastCountdownPrint = 0;
    countdownActive = true;
    ledWrite(255);
    Serial.print("Starting ");
    Serial.print(durationMs / 1000);
    Serial.println("-second countdown...");
}

void cancelCountdown() {
    countdownActive = false;
    countdownStartTime = 0;
    ledWrite(0);
    Serial.println("Countdown cancelled");
}

void handleCommand(const Command &c, unsigned long now) {
    switch (c.button) {
        case 1:
            if (c.value == 1) {
                // A pending countdown would keep blinking the LED and
                // fire the shutter a second time, so cancel it first
                cancelCountdown();
                incoming = 11;
                ledWrite(255);
                timestampButton = now;
                triggerShutter();
            } else {
                incoming = 10;
                ledWrite(0);
            }
            break;
        case 2:
            if (c.value == 1) {
                // A pending countdown would end the bulb exposure when
                // it expires, so cancel it first
                cancelCountdown();
                ledWrite(255);
                startBulbMode();
            } else {
                ledWrite(0);
                endBulbMode();
            }
            break;
        case 3:
            if (c.value == 1) startCountdown(c.durationMs);
            else cancelCountdown();
            break;
        default:
            Serial.println("Unknown button triggered");
    }
}

class BleServerCallback : public BLEServerCallbacks {
    void onConnect(BLEServer *pServer, ble_gap_conn_desc *desc) override {
        Serial.println("*** BLE CLIENT CONNECTED ***");
        deviceConnected = true;
        pServer->requestConnParams(desc->conn_handle, CONN_MIN_INTERVAL,
                                  CONN_MAX_INTERVAL, CONN_LATENCY, CONN_TIMEOUT);
    }

    void onDisconnect(BLEServer *pServer, ble_gap_conn_desc *desc) override {
        Serial.println("*** BLE CLIENT DISCONNECTED ***");
        deviceConnected = false;
        advertiseRequested = true; // restarted from loop(), off the BLE task
    }
};

class BLECharacteristicCallback : public BLECharacteristicCallbacks {
    void onWrite(BLECharacteristic *pCharacteristic) override {
        String data = pCharacteristic->getValue();
        Command c = {};

        if (data.length() == 1) {
            // Legacy single-byte protocol: button * 10 + state
            uint8_t v = data[0];
            c.button = v / 10;
            c.value = v % 10;
            c.durationMs = COUNTDOWN_DURATION;
            Serial.print("BLE command received (legacy): ");
            Serial.println(v);
        } else if (data.length() == 3) {
            // Multi-byte protocol: [command, duration s, action]
            c.button = data[0];
            c.durationMs = (uint8_t)data[1] * 1000U;
            c.value = data[2];
            Serial.print("BLE command received (multi-byte): [");
            Serial.print(c.button);
            Serial.print(", ");
            Serial.print(c.durationMs / 1000);
            Serial.print(", ");
            Serial.print(c.value);
            Serial.println("]");
            if (c.button != 3) {
                Serial.println("Unknown multi-byte command");
                return;
            }
        } else {
            Serial.print("Invalid command length: ");
            Serial.println(data.length());
            return;
        }
        xQueueSend(commandQueue, &c, 0);
    }
};

#ifdef VBAT_ADC_PIN
BLECharacteristic *pBattery = nullptr;
BLECharacteristic *pBatteryLevel = nullptr;
unsigned long lastVbat = 0;

// 1 MΩ / 1 MΩ divider on SW_SYS into an ADC1 pin; the 100 nF at the pin makes the 500 kΩ source fine.
uint16_t readVbatMillivolts() {
    uint32_t sum = 0;
    for (int i = 0; i < 8; i++) sum += analogReadMilliVolts(VBAT_ADC_PIN);
    return sum / 8 * 2;
}

void updateVbat(unsigned long t) {
    if (lastVbat && t - lastVbat < VBAT_PERIOD) return;
    lastVbat = t;
    uint16_t mv = readVbatMillivolts();
    uint8_t percent = constrain((int)(mv - VBAT_EMPTY_MV) * 100 / (VBAT_FULL_MV - VBAT_EMPTY_MV), 0, 100);
    pBattery->setValue((uint8_t *)&mv, 2);
    pBatteryLevel->setValue(&percent, 1);
    if (deviceConnected) {
        pBattery->notify();
        pBatteryLevel->notify();
    }
    Serial.print("SW_SYS mV: ");
    Serial.println(mv);
}
#endif

void setupBLE() {
    Serial.println("Initializing BLE...");

    BLEDevice::init("OpenRZ67");
    pServer = BLEDevice::createServer();
    pServer->setCallbacks(new BleServerCallback());

    BLEService *pService = pServer->createService(SERVICE_UUID);

    BLECharacteristic *pCharacteristic = pService->createCharacteristic(
            CHARACTERISTIC_UUID,
            BLECharacteristic::PROPERTY_READ |
            BLECharacteristic::PROPERTY_WRITE_NR
    );
    pCharacteristic->setCallbacks(new BLECharacteristicCallback());
#ifdef VBAT_ADC_PIN
    pBattery = pService->createCharacteristic(
            BATTERY_UUID,
            BLECharacteristic::PROPERTY_READ |
            BLECharacteristic::PROPERTY_NOTIFY
    );
#endif
    pService->start();

    // Device Information Service (0x180A), so any BLE tool can read the firmware version.
    BLEService *pDis = pServer->createService(BLEUUID((uint16_t)0x180A));
    pDis->createCharacteristic(BLEUUID((uint16_t)0x2A29), BLECharacteristic::PROPERTY_READ)->setValue("OpenRZ67");
    pDis->createCharacteristic(BLEUUID((uint16_t)0x2A24), BLECharacteristic::PROPERTY_READ)->setValue("Trigger");
    pDis->createCharacteristic(BLEUUID((uint16_t)0x2A26), BLECharacteristic::PROPERTY_READ)->setValue(FW_VERSION);
    pDis->start();

#ifdef VBAT_ADC_PIN
    // Battery Service (0x180F): Battery Level in percent, the standard form phones show.
    BLEService *pBas = pServer->createService(BLEUUID((uint16_t)0x180F));
    pBatteryLevel = pBas->createCharacteristic(
            BLEUUID((uint16_t)0x2A19),
            BLECharacteristic::PROPERTY_READ |
            BLECharacteristic::PROPERTY_NOTIFY
    );
    pBas->start();
#endif
    Serial.println("BLE services configured");

    BLEAdvertising *pAdvertising = BLEDevice::getAdvertising();
    pAdvertising->addServiceUUID(SERVICE_UUID);
    pAdvertising->setScanResponse(true);
    pAdvertising->setMinPreferred(CONN_MIN_INTERVAL);
    pAdvertising->setMaxPreferred(CONN_MAX_INTERVAL);
    pAdvertising->setMinInterval(ADV_MIN_INTERVAL);
    pAdvertising->setMaxInterval(ADV_MAX_INTERVAL);

    BLEAdvertisementData adData;
    adData.setName("OpenRZ67");
    adData.setCompleteServices(BLEUUID(SERVICE_UUID));
    pAdvertising->setAdvertisementData(adData);

    BLEAdvertisementData scanResponseData;
    scanResponseData.setName("OpenRZ67");
    scanResponseData.setCompleteServices(BLEUUID(SERVICE_UUID));
    pAdvertising->setScanResponseData(scanResponseData);

    // 0 dBm on advertising and connections (the default is +3 dBm)
    BLEDevice::setPower(ESP_PWR_LVL_N0, ESP_BLE_PWR_TYPE_ADV);
    BLEDevice::setPower(ESP_PWR_LVL_N0, ESP_BLE_PWR_TYPE_DEFAULT);

    pAdvertising->start();
    Serial.println("*** BLE ADVERTISING STARTED - Device visible as 'OpenRZ67' ***");
}

// Runs only when nothing else owns the LED (trigger hold, bulb, countdown).
void idleLed(unsigned long t) {
    if (deviceConnected) {
        ledWrite(CONNECTED_LEVEL);
        return;
    }
    // triangle 0..1..0 over PULSE_PERIOD, squared so the fade looks even
    float x = (t % PULSE_PERIOD) / (float)PULSE_PERIOD * 2;
    if (x > 1) x = 2 - x;
    ledWrite((uint8_t)(PULSE_MAX * x * x));
}

void configurePowerManagement() {
    esp_pm_config_t pm_config = {
        // USB Serial/JTAG drops off the bus in light sleep and is untested under DFS, so
        // the debug build (CDC on) stays awake at a fixed 80 MHz; production sleeps.
        .max_freq_mhz = 80,
        .min_freq_mhz = ARDUINO_USB_CDC_ON_BOOT ? 80 : 10,
        .light_sleep_enable = !ARDUINO_USB_CDC_ON_BOOT
    };
    // Needs CONFIG_PM_ENABLE (custom_sdkconfig in platformio.ini); without it this returns
    // ESP_ERR_NOT_SUPPORTED and the clock stays at F_CPU.
    esp_err_t err = esp_pm_configure(&pm_config);
    if (err == ESP_OK) {
        Serial.println("Power management: " + String(pm_config.min_freq_mhz) + "-80 MHz, light sleep "
                       + String(pm_config.light_sleep_enable ? "on" : "off"));
        // IDF's own fallback warning is below the build's log level, so say it here.
        Serial.println(rtc_clk_slow_src_get() == SOC_RTC_SLOW_CLK_SRC_XTAL32K
                       ? "RTC slow clock: X2 (32.768 kHz)"
                       : "RTC slow clock: internal RC, X2 not running (no light sleep with BLE)");
    } else {
        Serial.println("Power management not available in this framework build ("
                       + String(esp_err_to_name(err)) + ")");
    }
}

void setup() {
#if ARDUINO_USB_CDC_ON_BOOT
    Serial.setTxTimeoutMs(0); // Don't block when no serial monitor connected
#endif
    Serial.begin(115200);
    delay(500);  // Brief delay for serial stability

    commandQueue = xQueueCreate(4, sizeof(Command));
    ESP_ERROR_CHECK(esp_pm_lock_create(ESP_PM_NO_LIGHT_SLEEP, 0, "shutter", &shutterAwake));
    setupBLE();

    Serial.println("=== OPENRZ67 TRIGGER " FW_VERSION " ===");
    Serial.print("Free Heap: ");
    Serial.println(ESP.getFreeHeap());

    setupLed();
    pinMode(shutterPinS1, OUTPUT);
    pinMode(shutterPinS2, OUTPUT);

    configurePowerManagement();
    Serial.println("=== SETUP COMPLETE - SYSTEM READY ===");
}

void loop() {
    unsigned long now = millis();

    if (advertiseRequested) {
        advertiseRequested = false;
        pServer->startAdvertising();
        Serial.println("*** RESTARTED ADVERTISING ***");
    }

    Command c;
    while (xQueueReceive(commandQueue, &c, 0) == pdTRUE) handleCommand(c, now);

    if (incoming == 11 && ledLevel > 0 && now - timestampButton >= DELAY) {
        // Shutter has fired, disable LED
        ledWrite(0);
        Serial.println("Button 1 timeout reached");
    }

    // Countdown runs regardless of connection status
    if (countdownActive) {
        unsigned long elapsed = now - countdownStartTime;

        if (now - lastCountdownPrint >= 1000) {
            Serial.print("Countdown: ");
            Serial.print((countdownDuration - elapsed) / 1000);
            Serial.println(" seconds remaining");
            lastCountdownPrint = now;
        }

        if (elapsed >= countdownDuration) {
            countdownActive = false;
            countdownStartTime = 0;
            triggerShutter();
            ledWrite(0);
            Serial.println("Countdown complete - shutter triggered!");
        } else {
            ledWrite(elapsed % 250 < 125 ? 255 : 0); // fast blink
        }
    }

    if (bulbModeActive) {
        ledWrite(255);
    }

    // Idle: steady = phone connected, soft pulse = on and waiting
    bool triggerHold = incoming == 11 && now - timestampButton < DELAY;
    if (!countdownActive && !bulbModeActive && !triggerHold) {
        idleLed(now);
    }
#ifdef VBAT_ADC_PIN
    updateVbat(now);
#endif

    delay(10);
}

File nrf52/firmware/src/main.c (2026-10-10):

/* OpenRZ67 trigger, nRF54L15 / coin cell. Zephyr (nRF Connect SDK).
 *
 * Same GATT and command protocol as the ESP32-C3 firmware in ../../src/main.cpp, so the
 * Android and iOS apps do not change:
 *   service  c9239c9e-6fc9-4168-b3aa-53105eb990b0
 *   command  458d4dc9-349f-401d-b092-a2b1c55f5319  write-without-response
 *            1 byte:  button * 10 + state        (1 trigger, 2 bulb, 3 countdown; 1 start, 0 stop)
 *            3 bytes: [3, seconds, state]        countdown with its duration
 *   battery  cda71ce6-4af9-4aa2-8d34-329c2acdae09  cell voltage, mV, uint16 LE, read + notify
 *   plus Device Information (0x180A) and Battery Service (0x180F).
 *
 * Power: boot (button press) -> advertise ADV_TIMEOUT -> no connection: System OFF, the
 * button wakes it. Connected: no timeout. Disconnect -> advertise ADV_TIMEOUT again.
 */
#include <zephyr/kernel.h>
#include <zephyr/sys/poweroff.h>
#include <zephyr/drivers/gpio.h>
#include <zephyr/drivers/adc.h>
#include <zephyr/drivers/watchdog.h>
#include <zephyr/sys/byteorder.h>
#include <zephyr/bluetooth/bluetooth.h>
#include <zephyr/bluetooth/conn.h>
#include <zephyr/bluetooth/gatt.h>
#include <zephyr/bluetooth/services/bas.h>
#include <zephyr/logging/log.h>
#include <zephyr/init.h>
#include <hal/nrf_regulators.h>

LOG_MODULE_REGISTER(openrz67, LOG_LEVEL_INF);

#define ADV_TIMEOUT      K_MINUTES(5)
#define VBAT_PERIOD      K_SECONDS(60)
#define VBAT_EMPTY_MV    2500   /* CR2032: 0 % */
#define VBAT_FULL_MV     3000   /* 100 % */
#define TRIGGER_HOLD_MS  100    /* S2 held for a plain release */
#define S1_LEAD_MS       10     /* S1 before S2, lets the camera wake its meter */
#define DEFAULT_COUNTDOWN_MS 10000
#define LED_HOLD_MS      2000   /* LED on after a trigger */
#define LONG_PRESS       K_SECONDS(3)   /* button held this long: power off */
#define WDT_TIMEOUT_MS   5000   /* the main loop wakes at least every 2 s */

/* --- Pins (devicetree, see boards/openrz67/openrz67_nrf/openrz67_nrf_nrf54l15_cpuapp.dts) ---------- */
static const struct gpio_dt_spec led = GPIO_DT_SPEC_GET(DT_ALIAS(led0), gpios);
static const struct gpio_dt_spec s1 = GPIO_DT_SPEC_GET(DT_NODELABEL(s1_drv), gpios);
static const struct gpio_dt_spec s2 = GPIO_DT_SPEC_GET(DT_NODELABEL(s2_drv), gpios);
static const struct gpio_dt_spec button = GPIO_DT_SPEC_GET(DT_ALIAS(sw0), gpios);
static const struct adc_dt_spec vdd_adc = ADC_DT_SPEC_GET_BY_IDX(DT_PATH(zephyr_user), 0);
static const struct device *const wdt = DEVICE_DT_GET(DT_ALIAS(watchdog0));

/* --- GATT ------------------------------------------------------------------------- */
#define UUID_SERVICE BT_UUID_128_ENCODE(0xc9239c9e, 0x6fc9, 0x4168, 0xb3aa, 0x53105eb990b0)
#define UUID_COMMAND BT_UUID_128_ENCODE(0x458d4dc9, 0x349f, 0x401d, 0xb092, 0xa2b1c55f5319)
#define UUID_BATTERY BT_UUID_128_ENCODE(0xcda71ce6, 0x4af9, 0x4aa2, 0x8d34, 0x329c2acdae09)

static const struct bt_uuid_128 uuid_service = BT_UUID_INIT_128(UUID_SERVICE);
static const struct bt_uuid_128 uuid_command = BT_UUID_INIT_128(UUID_COMMAND);
static const struct bt_uuid_128 uuid_battery = BT_UUID_INIT_128(UUID_BATTERY);

struct command {
	uint8_t button;      /* 1 trigger, 2 bulb, 3 countdown */
	uint8_t value;       /* 1 start, 0 stop */
	uint32_t duration_ms;
};
K_MSGQ_DEFINE(commands, sizeof(struct command), 8, 4);

static uint16_t vbat_mv;
static bool vbat_notify;

static ssize_t write_command(struct bt_conn *conn, const struct bt_gatt_attr *attr,
			     const void *buf, uint16_t len, uint16_t offset, uint8_t flags)
{
	const uint8_t *d = buf;
	struct command c = {.duration_ms = DEFAULT_COUNTDOWN_MS};

	if (len == 1) {
		c.button = d[0] / 10;
		c.value = d[0] % 10;
	} else if (len == 3 && d[0] == 3) {
		c.button = 3;
		c.duration_ms = d[1] * 1000U;
		c.value = d[2];
	} else {
		return BT_GATT_ERR(BT_ATT_ERR_VALUE_NOT_ALLOWED);
	}
	k_msgq_put(&commands, &c, K_NO_WAIT);
	return len;
}

static ssize_t read_battery(struct bt_conn *conn, const struct bt_gatt_attr *attr,
			    void *buf, uint16_t len, uint16_t offset)
{
	uint16_t v = sys_cpu_to_le16(vbat_mv);
	return bt_gatt_attr_read(conn, attr, buf, len, offset, &v, sizeof(v));
}

static void battery_ccc_changed(const struct bt_gatt_attr *attr, uint16_t value)
{
	vbat_notify = value == BT_GATT_CCC_NOTIFY;
}

BT_GATT_SERVICE_DEFINE(trigger_svc,
	BT_GATT_PRIMARY_SERVICE(&uuid_service),
	BT_GATT_CHARACTERISTIC(&uuid_command.uuid, BT_GATT_CHRC_WRITE_WITHOUT_RESP | BT_GATT_CHRC_WRITE,
			       BT_GATT_PERM_WRITE, NULL, write_command, NULL),
	BT_GATT_CHARACTERISTIC(&uuid_battery.uuid, BT_GATT_CHRC_READ | BT_GATT_CHRC_NOTIFY,
			       BT_GATT_PERM_READ, read_battery, NULL, NULL),
	BT_GATT_CCC(battery_ccc_changed, BT_GATT_PERM_READ | BT_GATT_PERM_WRITE),
);

/* --- Advertising / connection ---------------------------------------------------- */
static const struct bt_data ad[] = {
	BT_DATA_BYTES(BT_DATA_FLAGS, BT_LE_AD_GENERAL | BT_LE_AD_NO_BREDR),
	BT_DATA_BYTES(BT_DATA_UUID128_ALL, UUID_SERVICE),
};
static const struct bt_data sd[] = {
	BT_DATA(BT_DATA_NAME_COMPLETE, CONFIG_BT_DEVICE_NAME, sizeof(CONFIG_BT_DEVICE_NAME) - 1),
};
/* 30-60 ms advertising, as on the ESP32 board; the phone sees us at once */
static const struct bt_le_adv_param adv_param =
	BT_LE_ADV_PARAM_INIT(BT_LE_ADV_OPT_CONN, 0x0030, 0x0060, NULL);

static struct bt_conn *current_conn;
static void adv_timeout_fn(struct k_work *work);
static K_WORK_DELAYABLE_DEFINE(adv_timeout, adv_timeout_fn);

static void start_advertising(void)
{
	int err = bt_le_adv_start(&adv_param, ad, ARRAY_SIZE(ad), sd, ARRAY_SIZE(sd));
	if (err && err != -EALREADY) {
		LOG_ERR("adv start %d", err);
	}
	k_work_reschedule(&adv_timeout, ADV_TIMEOUT);
}

static void power_off(void)
{
	bt_le_adv_stop();
	gpio_pin_set_dt(&led, 0);
	gpio_pin_set_dt(&s1, 0);
	gpio_pin_set_dt(&s2, 0);
	/* the button (active low, pulled up) wakes the chip from System OFF */
	gpio_pin_interrupt_configure_dt(&button, GPIO_INT_LEVEL_ACTIVE);
	sys_poweroff();
}

static void adv_timeout_fn(struct k_work *work)
{
	if (current_conn == NULL) {
		LOG_INF("nobody came, sleeping");
		power_off();
	}
}

static void connected(struct bt_conn *conn, uint8_t err)
{
	if (err) {
		return;   /* recycled() restarts advertising */
	}
	current_conn = bt_conn_ref(conn);
	k_work_cancel_delayable(&adv_timeout);
	/* 30-50 ms interval, no latency: a shutter command is acted on within one interval */
	bt_conn_le_param_update(conn, BT_LE_CONN_PARAM(0x18, 0x28, 0, 400));
}

static void disconnected(struct bt_conn *conn, uint8_t reason)
{
	/* the app can no longer send the stop: end a bulb here so the outputs do not stay on */
	struct command stop = {.button = 2, .value = 0};
	k_msgq_purge(&commands);   /* drop queued starts, make room for the stop */
	k_msgq_put(&commands, &stop, K_NO_WAIT);
	if (current_conn) {
		bt_conn_unref(current_conn);
		current_conn = NULL;
	}
}
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

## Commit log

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2026-09-07 PCB: restore USB1 locating-peg NPTH holes
    JLCPCB flagged the rev-2 PCBA order: no drill holes under the USB-C
    connector's two 0.7 mm locating pegs. The EasyEDA importer had put them on
    Edge.Cuts and the cleanup pass moved them to F.Fab, so the NPTH drill file
    was empty. The pegs are np_thru_hole pads again, in the library footprint
    and on the board, at the rev-1 positions; the NPTH drill now matches the
    fabricated 2025-09-23 set. openrz67.kicad_dru relaxes hole clearance to
    0.15 mm for those two pads only (0.171 mm to pads 1/12 is inherent to the
    LCSC footprint). Outputs regenerated; README notes updated.
    [openrz67-B_Cu.gbl, openrz67-B_Mask.gbs, openrz67-B_Paste.gbp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]
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2026-09-07 PCB rev 2: apply pre-fab review fixes
    Blockers from the 2026-09-07 review:
    - R11 100k -> 10k. It sets the LGS5500 charge current; 100k meant 1 A into
    the 250 mAh cell (rev 1 shipped like that). 10k = 400 mA per datasheet.
    - Three resistor lines had 19-40 pieces in JLCPCB stock: 10k group ->
    C25744 (Basic), R12 1k -> C21190 (Basic), R18 3k -> C2909355. Library
    symbols renamed to the new MPNs, 100k symbol dropped, board fields synced.
    - The VCC via feeding L2 pad 1 had its hole 0.083 mm inside the pad copper;
    moved 0.55 mm below the pad with a short F.Cu stub.
    Should-fixes:
    - openrz67.kicad_dru: two scoped rules instead of one unscoped one, so the
    pours stay 0.25 mm off the USB1 peg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
    [openrz67-B_Cu.gbl, openrz67-B_Mask.gbs, openrz67-B_Paste.gbp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]
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2026-09-07 Firmware: USB CDC logging only in a debug build
    The 2025-09-23 commit turned CDC off because Serial blocked boot with no
    host attached, and the 2025-09-28 commit enabled automatic light sleep,
    which the ESP32-C3's USB Serial/JTAG port does not survive: the host loses
    the device every time the chip dozes. So the previous commit's unconditional
    CDC-on was wrong for a battery device. Production env: CDC off, VERBOSE 0,
    light sleep on, as before. New debug env: CDC on, VERBOSE 1, and light sleep
    disabled via the same flag so the link stays up; setTxTimeoutMs(0) keeps
    prints from blocking when no monitor is attached. UART TX on GPIO21 (header
    J1 on the gpio-header branch) is the logging path that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
    [main.cpp]
2026-09-07 PCB: unpopulated 1x4 GPIO header J1 along the bottom edge
    3V3, GND, GPIO21 (U0TXD, doubles as UART TX for logging) and GPIO6 on
    2.54 mm through-hole pads at x = 34.4-42.0, y = 20.3 mm, below the AGND
    island so camera isolation is untouched. J1 is DNP in the schematic and on
    the board, so --exclude-dnp keeps it out of the BOM and CPL; the pads are
    just copper and holes on the bare PCB.
    Only one right-column ESP32-C3 pin fits through the gap between the VCC,
    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
    [openrz67-B_Cu.gbl, openrz67-B_Mask.gbs, openrz67-B_Paste.gbp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]
2026-09-07 PCB: silkscreen labels for J1, header moved 0.3 mm toward the edge
    3V3 GND TX IO6 in two staggered rows above the pads (1.0 mm text), kept
    below the U4 housing so they stay readable with the connector fitted. The
    footprint's own silk outline is removed (board and library) to make room;
    the square pad already marks pin 1. Pads now at y = 20.6 mm, 0.55 mm copper
    to edge, and a third GND stitching via that fell within hole-to-hole
    distance of pad 2 is gone. Tracks re-routed to the new pad positions.
    DRC 0 errors / 9 known warnings, ERC 0/0, parity clean.
    [openrz67-B_Cu.gbl, openrz67-B_Mask.gbs, openrz67-B_Paste.gbp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]
2026-09-07 Camera plug: flat two-half shell, prints without supports
    Body as tall as the nose so each half lies on its outer face; rear wall with
    wire notches replaces the glue chamber.
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2026-09-07 Case: cut the lid tongue in the U4 band; LED window follows D3
    cut_xh only started at the split, so the lid's tongue and snap bead stood in
    the connector band and had to pass through the U4 body while the lid was
    lowered (2.5-59 mm3 collision at 0.2-4 mm lift; 0 when closed, which is why the
    probe passed). The cut now spans the full lap depth. Lift sweep 0.2-8 mm: 0 mm3.
    D3 moved next to the new charger on the PCB, so led_pos is updated and the
    light-pipe window widened to 4.4 mm to cover both LED bodies.
2026-09-07 PCB rev 2: BQ25185 charger + TPS63031 buck-boost replace LGS5500 + LDO
    The cell is rated for 120 mA charge current; the LGS5500's lowest setting is
    400 mA and rev 1 shipped at 1 A. U3 is now a BQ25185DLHR (linear charger with
    power path): R11 2.7 k on ISET -> 111 mA nominal, R13 18 k on ILIM/VSET -> 500 mA
    input limit / 4.20 V / 3.0 V precharge, R16 NTC on TS/MR, STAT2 drives D3 (lit
    while charging). SYS feeds S3 and then U2, a TPS63031DSKR fixed 3.3 V buck-boost
    that replaces the ME6211 LDO (L3 2.2 uH reused, C23/C24 10 uF, C25 100 nF VINA).
    LDO1, R12, R14, R17 and the +5V nets are gone. Cross-checked against the TI
    datasheets; the LCSC footprints were compared with TI's land patterns.
    R21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
    [openrz67-B_Cu.gbl, openrz67-B_Mask.gbs, openrz67-B_Paste.gbp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]
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2026-09-07 PCB: R20 1 kOhm, J1 excluded from BOM/CPL by attribute, 3D model fixes, MPN
    - R20 10k -> 1k (C11702): the blue status LED was practically invisible.
    - J1: in_bom no on the symbol, exclude_from_bom/exclude_from_pos_files on the
    footprint, so the exclusion no longer hinges on --exclude-dnp.
    - TLP172AM MPN 'TLP172AM(TPL,E' -> 'TLP172AM(TPL,E)'.
    - 3D models: the imported offsets put U4 3.45 mm off and 3.4 mm low, BAT1/S3
    0.6 mm off and 3.5 mm low, USB1 1.2 mm off and 0.9 mm low (checked against the
    pin geometry in the .wrl files). Corrected in the library and the board; the
    BQ25185 and TPS63031 got their LCSC models.
    DRC 0 errors / 14 known warnings, ERC 0 errors.
    [openrz67-B_Cu.gbl, openrz67-B_Mask.gbs, openrz67-B_Paste.gbp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]
2026-09-07 PCB README: correct the R20/D4 reasoning (10 k was dim, not invisible)
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2026-09-07 PCB: model blocks inside the two new library footprints
    The (model ...) had landed after the footprint's closing paren, so
    FootprintLoad() gave 0 models and a fresh placement from the library would
    have had none. Rewritten from the board copies with KiCad's own writer.
    [openrz67-B_Cu.gbl, openrz67-B_Mask.gbs, openrz67-B_Paste.gbp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]
2026-09-07 Firmware: 80 MHz via board_build.f_cpu; correct core version and clock claims
    The build uses Arduino core 2.0.14 (framework 3.20014 pinned by espressif32
    6.6.0), not 2.0.17, and the board default F_CPU is 160 MHz. esp_pm cannot lower
    the clock in this build, so set it at build time instead; README and comments
    no longer claim light sleep.
    [main.cpp]
2026-09-07 PCB: C14/C26/C29 1 µF → Samsung CL10A105KB8NNNC (C15849); HRE part low on stock
    [openrz67-B_Cu.gbl, openrz67-B_Mask.gbs, openrz67-B_Paste.gbp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]
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2026-09-08 PCB: filled 0.4 mm pin-1 silk dots on WSON-10 (U3) and QFN-32 (U1)
    JLCPCB asked to confirm U3's polarity on the 2026-09-08 order: the WSON-10
    footprint's pin-1 mark was a 0.06 mm ring, below their 0.15 mm silk minimum,
    so their preview had no mark to check against. The QFN-32 had no pin-1 mark
    at all. Both footprints (library and board copies) now carry a filled 0.4 mm
    dot outside the body at the pin-1 corner. out/ regenerated; DRC unchanged.
    [openrz67-B_Cu.gbl, openrz67-B_Mask.gbs, openrz67-B_Paste.gbp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]
2026-09-08 PCB: routing pass — U2 EP vias + solid GND, VCC feed off U2 pad, GPIO21 jog away from LNA_IN
    - U2 exposed pad: 4 GND vias (0.45/0.25); U2 and USB1 pads 1/12 solid zone
    connect, starved_thermal warnings gone
    - B.Cu VCC feed from U2 output routed around the west side of U2 instead of
    under its pad; SW1/SW2 pad exits 0.254 mm
    - GPIO21 F.Cu jog next to U1 pin 1 (LNA_IN) moved 0.75 mm west (0.21 -> 0.79 mm
    to the RF trace); two GND stitching vias relocated
    - DRC: 0 errors, 0 unconnected; B.Cu ground under U1 keeps its channel
    - README: via 0.45/0.25, warnings table, changelog; out/ regenerated
    [openrz67-B_Cu.gbl, openrz67-B_Mask.gbs, openrz67-B_Paste.gbp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]
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2026-09-08 PCB: review fixes — C23 at U2 VIN, GND necks opened, GPIO21 single B.Cu run, U3 EP vias
    [openrz67-B_Cu.gbl, openrz67-B_Mask.gbs, openrz67-B_Paste.gbp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]
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2026-09-09 PCB: archive rev 2 as ordered 2026-09-07 (commit 0e1376e); archive/ = upload record, status is a README line
    [openrz67-bom.csv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]
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2026-09-09 Camera plug: peg holes Ø1.9 (0.2 print went on but very tight); sleeve channel +0.2 wide, own width clearance so the skins stay 0.4
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2026-09-10 Case: every export script rebuilds openrz67-case.3mf; the 3mf was stale for three plug prints. History comment corrected
2026-09-10 PCB: R23 10k pull-up on GPIO8 (strapping pin was floating); C29 +0.55 mm, GPIO6 via moved, VCC artery on x 25.709
    GPIO8 needs to be high for Joint Download Boot and has no internal pull;
    rev 1 and the ordered rev 2 leave it floating behind a no-connect flag.
    Also adds the 2026-09-10 design review and its adversarial counter-read
    under notes/. VDD_SPI 1 uF not added: no room on the top side (README).
    [openrz67-B_Cu.gbl, openrz67-B_Mask.gbs, openrz67-B_Paste.gbp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]
2026-09-13 Case: stacked layout — cell under the PCB on 11 mm posts, 4 cantilever snap fingers, U4 plug inside + keyhole cable slot
    - LiPo flat under the board (foam between), open pockets front 3 / back 5 mm
    for fingers and the battery lead; guide fins on both long edges
    - Snap: four fingers cut free in the lid tongue (bead near the tip, lap 7)
    with matching pockets in the base lip; walls 3.2 stay rigid
    - U4 header + plug stay inside; only the heat-shrunk cable leaves through a
    keyhole in the lid's right wall, open down to the seam
    - make_3mf: lift each part by -min(z) after recentring so a taller part is
    not clipped below the bed (the 15.4 mm base lost its 2 mm floor)
    - README rewritten for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
2026-09-14 Case: tighter snap, funnel seat for the light pipe, Futura nameplate with a rail
    First stacked print (2026-09-14): the lid held loosely and the LED counterbore
    printed ragged on the bed side.
    - Snap: bead 0.45 -> 0.55, small 0.15 chamfer on the retention side (was 0.4:
    both retention faces were 45° ramps), pocket ceiling chamfer 0.5 -> 0.2,
    pocket 0.3 taller instead of 0.5 (less slop). pocket_extra_d/h, bead_ch_*,
    pocket_ch as named constants.
    - Light pipe: the head seat is a 26.6° funnel (led_head_lip 0.7 over led_head_t
    1.4) instead of a stepped counterbore — no ledge over the first-layer opening,
    under the slicer's 30° support threshold. Still a top hat from above.
    - Lid t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
2026-09-14 Case: KCD11 snap-in rocker replaces the SS12F15 slide switch + screw pillars
    Snap-in hole 13.5x8.5 (+0.3/side) centred on the lid's front wall, wall pocketed
    from inside to 2.0 mm around it for the latches, flange proud outside. Lid grows
    1.9 mm (box 66.3 x 36.0 x 25.5): comp_clr is now set by the rocker body + latch
    room, not the PH plugs. Wired with 2.8 mm flag receptacles to S3; asserted that
    tabs + receptacles end before the light pipe and the S3 plug. KCD11 dims are
    vendor-nominal — measure before printing. SS12F15.stp dropped.
    [SS12F15.stp]
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2026-09-15 PCB rev 3: battery voltage sense on GPIO3, S2 relay moved to GPIO6
    R24/R25 1 MΩ + C32 100 nF under S3 divide SW_SYS (switched cell voltage; BQ25185
    SYS voltage on USB) into GPIO3/ADC1_CH3 through the old S2_DRV copper. S2_DRV now
    comes from GPIO6 (pin 12), fed off the existing GPIO6 track at (150.55, 99.3), so
    J1 pin 4 carries the S2 drive. Every other spare pin was boxed in; BAT+ was
    unreachable from U1. DRC 0 errors / 0 unconnected (two new courtyard warnings),
    ERC unchanged, title block rev 3. Firmware todo for rev 3 in pcb/kicad/README.md;
    src/ still targets rev 2.
    [openrz67-B_Cu.gbl, openrz67-B_Mask.gbs, openrz67-B_Paste.gbp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]
2026-09-15 PCB rev 3: J1 shrinks to 1x3 (3V3, GND, TX); GPIO6 track to the old pin 4 and IO6 silk removed
    [openrz67-B_Cu.gbl, openrz67-B_Mask.gbs, openrz67-B_Paste.gbp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]
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2026-09-15 Docs: the battery reading is a system voltage, not a USB-present flag
    Worst-case tolerances (charger, 1 % divider, ±70 mV ADC) let a full cell
    and a USB-powered SYS rail both land near 4.3 V, and DPPM/supplement mode
    can pull SYS down with USB connected, so the old '> 4300 mV means USB'
    claim is not safe. Note the 500 kΩ source impedance and the bench
    measurement to do before trusting absolute values.
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2026-09-16 Case: lid text as a colour-2 inlay part, baked into the .3mf
    The lid text came out fuzzy on every print. The lid prints top-face-down, so an
    empty 0.6 mm pocket floor is a bridge over open air: it sagged and the letters
    read blurry. Colouring it was manual too — slicer colour painting is stored per
    mesh triangle, and make_3mf.py replaces the mesh on every export, so it had to
    be redone each time (a height range modifier cannot be saved either: QIDI
    Studio segfaults on a .3mf carrying layer_config_ranges.xml).
    Both fixed by making the letters their own solid. openrz67_case.py builds
    lid_text as the pocket volume clipped by the lid — it fills the pockets exactly,
    inherits the top-edge cha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
2026-09-17 Case: lid text inlay 0.8 mm (4 layers), was 0.6
    Three layers let the lid's body colour ghost through and the letters read weak
    on the print. Four is noticeably stronger. 0.9 is the cap at lid_top_t = 2.0 --
    the antenna-recess assert keeps 0.8 mm of plate between the two.
    Still not as crisp as a true empty recess: the colour boundary sits in the first
    layer against the bed, which spreads. A real recess is not on the table -- the
    lid prints upside down, so the pocket floor would bridge, and printing text-up
    puts the whole lid interior (snap fingers, bosses, rocker pocket) in overhang.
    Soluble support (HIPS under ABS, dissolved out in d-limonene) would make it work
    and is noted in the README a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
2026-09-17 Docs: correct stale facts, document the antenna recess
    - BOM.md: lid text is an inlay part on filament 2, 0.8 mm deep (was
    described as a colour change at Z 0.6, wrong on both counts)
    - README.md / case/README.md: the stacked case was first printed
    2026-09-14, not "not yet print-tested"
    - case/README.md: camera plug has been printed three times (Ø1.5 no-go,
    Ø1.7 very tight, pegs sheared -> rib + groove); untested since
    - case/README.md: the light-pipe seat is a funnel, not a counterbore
    - case/README.md: document the 25.6 x 9.6 x 0.3 FPC antenna recess —
    Construction bullet, Source data row, and ant_* under "Worth adjusting"
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2026-09-19 Case: slide the board 1.4 mm into the USB wall; drop the printed camera plug
    The USB-C receptacle mouth stopped 0.4 mm short of the left wall's inner face,
    so the whole usb_recess_d went unused. usb_shell_poke = 1.4 slides the board
    toward that wall (subtracted in inner_w and bx()): the shell noses into the
    recess, the plug seats 1.4 mm deeper, and the box goes 66.3 -> 64.9 mm wide.
    usb_recess_d 1.0 -> 1.2, plus an assert that the shell can never bottom out in
    the wall (that would lift the PCB off its locating pins). 2 mm was considered
    and rejected: it would thin the lip around the USB hole to 0.4 mm, the lip that
    already printed thin and ragged on 2026-09-15.
    Height and depth are untouche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
2026-09-19 Case: press-fit the light pipe; lift the lid text off the chamfer
    Light pipe: the stem window sat in the 2 mm top plate, of which 1.4 is the
    head funnel -- only 0.6 mm of grip, so the pipe rattled and needed glue. A
    2.6 mm collar now hangs off the ceiling around the window (grip 3.2 mm) and
    the bore is 0.10 under the pipe (~0.05/side, ~1 % strain in ABS). The head
    keeps led_pipe_clr 0.2 so the taper still self-centres. A snap bead inside
    the collar was tried and dropped: deep enough to click is deeper than a
    solid pipe can squeeze past, and the 0.6 mm wall splays instead. The
    antenna's free ceiling band (band_y1) now clears the collar, and an assert
    keeps the collar above the pipe's LED gap.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
2026-09-20 Case: revert the light-pipe press fit to a slip fit; keep the collar for guidance
    led_stem_clr -0.10 (3466b5d) could not be pressed in by hand -- a solid clear
    rod has nothing to flex, and neither does the 0.6 mm collar wall. Back to
    led_pipe_clr (0.2) on the stem too, so the pipe drops in and is glued as
    before. The collar stays: 3.2 mm of bore instead of 0.6 keeps the pipe from
    tilting, which is the part of 3466b5d that was worth having.
    README: both no-glue attempts (snap bead, interference bore) are now recorded
    as tried and dropped, so neither gets proposed again.
    make_3mf.py: drop the EXTRA_PLATES docstring left behind when the camera plug
    went (dff0c23); that code path no longer exi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
2026-09-20 Case: light pipe on its own plate with clear-print object settings
    Template re-saved from QIDI Studio: the light pipe moves to plate 2 on
    filament 3 (clear) with per-object settings -- 0.28 mm layers, 100 % infill,
    8 wall loops, 20 mm/s -- so it prints with no filament swaps and none of that
    leaks into the case parts. Per-object metadata lives in model_settings.config
    and survives make_3mf.py's mesh swap the same way the extruder does.
    make_3mf.py: a template saved from an exported project already contains the
    lid-text sub-part, so add_sub_parts was adding a second copy. strip_sub_parts
    removes any SUB_PARTS mesh the template carries (part, component and mesh
    object) before the fresh one go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
    [bambu-template.3mf]
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2026-09-25 Case: name the pin/bead/keepout numbers, one USB-C body tuple, drop unused KCD params
    usbc_body feeds both the lid keepout cut and its probe (inset 0.5), so they cannot drift. kcd_tab_pitch / kcd_conn_w were never read; kcd_flange_l now checks the flange stays on the flat front face. Meshes byte-identical.
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2026-09-25 Case: make_3mf fails loudly on an unexpected template; warn when the template is missing
    build_mapping skipped objects without source_offset and never noticed a missing part; it now requires exactly base, lid and lightpipe. The face_count updates are anchored to their own <object> (the object-level count and the part's mesh_stat, not a duplicate) and must match. openrz67_case.py prints a stderr warning instead of silently skipping the 3mf.
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2026-09-25 PCB rev 3: reverse-battery P-FET Q3, C24 at the buck-boost output, EP paste windows, 0.8 mm RF line, review notes
    Review round 2026-09-25 (pcb/kicad/notes/review-2026-09-25.md):
    - Q3 AO3401A (SOT-23, C15127) between BAT1 pin 1 (new net BAT_CELL) and BAT+;
    gate to GND. VBUS moved to B.Cu under it; BAT+ rerouted west of L3 pad 1.
    - C24 to (138.0, 97.0), 1.5 mm from U2 VOUT, with a return GND via.
    - U1 exposed pad: no paste on the pad, four 1.5 mm aperture windows; U2/U3
    exposed pads 85 % paste. Same change in the library footprints.
    - RF line 0.8 mm from the U.FL pad to C2 (~52 ohm).
    - S2_DRV via 0.45/0.25 (no JLCPCB surcharge), nudged into the free slot.
    - Bottom silk v3, '+' at BAT1 pin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
    [openrz67-B_Cu.gbl, openrz67-B_Mask.gbs, openrz67-B_Paste.gbp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]
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2026-09-25 PCB rev 3: C24 at U2 pin 1 (VOUT), not pin 10 (FB); reversed cell with USB documented
    PR #9 review: VOUT is pin 1, pin 10 is FB tied to VOUT, so the first move only
    got the cap to the FB side. C24 now at (134.15, 95.9), VCC pad 0.8 mm from pin 1,
    in the notch between L3 and the VSYS corner; the VSYS via moved 0.3 mm east to
    make room. Return GND via beside its GND pad. README: with USB in, the charger
    turns Q3 on regardless of cell polarity and trickles ~7 mA into a reversed cell
    until the safety timer; unplug USB first. DRC 0 err / 22 warn (+2 courtyard,
    +4 silk clipped by mask at C24), ERC unchanged.
    [openrz67-B_Cu.gbl, openrz67-B_Mask.gbs, openrz67-B_Paste.gbp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]
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2026-09-25 Firmware: automatic light sleep between BLE events
    Power management was off in the prebuilt Arduino libraries, so the chip idled awake
    at 80 MHz. custom_sdkconfig has pioarduino rebuild them with PM, tickless idle and BLE
    modem sleep on the 32.768 kHz crystal X2; esp_pm_configure() now actually enables DFS
    and light sleep in production.
    - Status LED on IDF LEDC from RC_FAST in keep-alive mode, so the pulse survives sleep.
    - PM lock while the shutter is open: tickless idle forces PM_SLP_DISABLE_GPIO on,
    which would release S1/S2 in the middle of a bulb exposure.
    - debug env stays awake at a fixed 80 MHz for USB CDC.
    - FW_VERSION 0.4.0.
    Untested on a board.
    [main.cpp]
2026-09-25 Firmware: log whether X2 runs as the RTC slow clock
    IDF's own fallback warning is below the prebuilt log level (errors only), so the
    bench check needs its own line.
    [main.cpp]
2026-09-30 Docs: READMEs describe, notes explain
    READMEs are for humans: what it is, how to build, how to use. Dates, 'was X until Y'
    and rejected alternatives move out.
    - pcb/kicad/README.md: 6300 -> 1000 words. The rev 2 changes, rev 3 and port notes
    move verbatim to pcb/kicad/notes/revisions.md; a short Revisions table stays.
    - case/README.md: 4700 -> 2200 words. The tried-and-dropped history moves to
    case/notes/design-history.md.
    - README.md: 1800 -> 1400 words. One status line for the board revisions.
    - BOM.md: fix the row numbering, printed parts are ABS.
    - CLAUDE.md: rule for where history goes.
2026-10-03 nrf52: generated KiCad board, first pass
    [openrz67-nrf-B_Cu.gbl, openrz67-nrf-B_Mask.gbs, openrz67-nrf-B_Paste.gbp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]
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2026-10-03 nrf52: JST SH camera connector, datasheet facts
    [openrz67-nrf-B_Cu.gbl, openrz67-nrf-B_Mask.gbs, openrz67-nrf-B_Paste.gbp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]
2026-10-03 nrf52: board 27 x 29
    [openrz67-nrf-B_Cu.gbl, openrz67-nrf-B_Mask.gbs, openrz67-nrf-B_Paste.gbp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]
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2026-10-04 nrf52: review fixes before ordering
    [openrz67-nrf-B_Cu.gbl, openrz67-nrf-B_Mask.gbs, openrz67-nrf-B_Paste.gbp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]
2026-10-04 nrf52: via off the cell pad, JLC CPL format
    [openrz67-nrf-B_Cu.gbl, openrz67-nrf-B_Mask.gbs, openrz67-nrf-B_Paste.gbp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]
2026-10-04 nrf52: cell clip 3D model matches JLC orientation
    [openrz67-nrf-B_Cu.gbl, openrz67-nrf-B_Mask.gbs, openrz67-nrf-B_Paste.gbp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]
2026-10-04 nrf52: rotate cell clip 180° in the CPL for JLC
    [openrz67-nrf-B_Cu.gbl, openrz67-nrf-B_Mask.gbs, openrz67-nrf-B_Paste.gbp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]
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2026-10-04 nrf52: no paste on cell pad, VBUS to GND, vias out of pads
    [openrz67-nrf-B_Cu.gbl, openrz67-nrf-B_Mask.gbs, openrz67-nrf-B_Paste.gbp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]
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2026-10-04 nrf52 case: fix mirrored board mapping, button tab off the wall
2026-10-04 nrf52: track firmware CMakeLists, stop regen on generator failure
2026-10-04 nrf52 case: clear light pipe over the LED
    [qidi-template.3mf]
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2026-10-04 nrf52 pcb: cell polarity label on the back silkscreen
    [openrz67-nrf-B_Cu.gbl, openrz67-nrf-B_Mask.gbs, openrz67-nrf-B_Paste.gbp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]
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2026-10-05 nrf52 case: thinner first layer for sharper lid text
    [qidi-template.3mf]
2026-10-05 nrf52 pcb: basic C2, R3 shares the 330 Ω part
    [openrz67-nrf-B_Cu.gbl, openrz67-nrf-B_Mask.gbs, openrz67-nrf-B_Paste.gbp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]
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2026-10-06 nrf52 pcb: connector names and board name on silkscreen
    [openrz67-nrf-B_Cu.gbl, openrz67-nrf-B_Mask.gbs, openrz67-nrf-B_Paste.gbp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]
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2026-10-07 nrf52 pcb: reverse-cell P-MOSFET
    [openrz67-nrf-B_Cu.gbl, openrz67-nrf-B_Mask.gbs, openrz67-nrf-B_Paste.gbp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]
2026-10-08 nrf52: J2 mouth at the board edge, board 29.5 wide
    [openrz67-nrf-B_Cu.gbl, openrz67-nrf-B_Mask.gbs, openrz67-nrf-B_Paste.gbp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]
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2026-10-10 nrf52 pcb: 220 Ω relay drive, C3 at the module
    [openrz67-nrf-B_Cu.gbl, openrz67-nrf-B_Mask.gbs, openrz67-nrf-B_Paste.gbp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]
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2026-10-10 nrf52: archive rev A fab package as ordered
    [openrz67-nrf-bom.csv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]
